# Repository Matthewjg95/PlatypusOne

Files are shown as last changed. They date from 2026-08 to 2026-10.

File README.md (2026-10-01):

# PlatypusOS

An extensible embedded operating environment for the **Arduino UNO Q**, built by
Platypus One. PlatypusOS is not a single application — it is an engineering
handheld platform where **every feature is an app**.

## Architecture at a glance

```
┌─────────────────────────────────────────────────────┐
│  apps/        launcher · shadowscan · viewer ·      │
│               measurement · inspection · docs ·     │
│               settings          (all implement IApp)│
├─────────────────────────────────────────────────────┤
│  services/    appfw · renderer · vision · ai ·      │
│               geometry · export · filesystem        │
├─────────────────────────────────────────────────────┤
│  platform/    HAL interfaces + board drivers        │
│               (IBoard · ICamera · ISensorHub ·      │
│                IDisplay · IAudioOutput · IMcuBridge)│
├─────────────────────────────────────────────────────┤
│  Arduino UNO Q:  Linux MPU (QRB2210)  ⇄  STM32U585 │
└─────────────────────────────────────────────────────┘
```

Dependency direction is strict: **apps → services → platform**. Nothing points
upward. Concrete hardware types exist only in board implementations and the
composition root ([main.cpp](apps/launcher/src/main.cpp)).

## Key principles

- **Everything is an app.** Features implement `IApp` and register with
  `AppRegistry`. The launcher is itself just an app.
- **Interfaces over hardware.** No module touches a driver; capabilities come
  through `IBoard` accessors that return `nullptr` when absent.
- **Dependency injection, no global state.** All services flow through
  `AppContext`, built once in the composition root.
- **Host-first development.** `HostSimBoard` lets the whole OS build and run on
  a workstation with zero hardware.
- **Plugin-ready.** `AppFactory` is the future dynamic-loading ABI.

## Building

```
cmake -B build -DPLATYPUS_TARGET_HOST=ON
cmake --build build
ctest --test-dir build
./build/apps/launcher/platypus_launcher
./build/apps/launcher/platypus_launcher --geometry 800x480
```

Requires CMake ≥ 3.22 and a C++20 compiler (GCC 12+, Clang 15+, MSVC 19.3+).
Every subsystem is an independent CMake target and compiles on its own.

`--geometry WxH` simulates a different panel (default 320×240). No resolution
is compiled in: the display target is deliberately dynamic while the production
panel is undecided, and prototyping runs against a linked external display —
see [ADR-0001](docs/adr/0001-dynamic-linked-prototype-display.md) and the
[presentation link protocol](docs/protocols/presentation.md).

The Scout prototype also has a local Linux/KMS kiosk for the UNO Q + Media
Carrier + Waveshare 800×480 panel. Use the [pinned UNO Q build/launch sequence](docs/hardware/UNO_Q_SCOUT_BASELINE.md)
for that path. Dream Lab was submitted September 30; [stabilization and evidence status](docs/contest/POST_DREAMLAB_STABILIZATION.md)
separate the merged single-capture baseline from staged sessions/classifier work.

## Documentation

- [docs/PRODUCT_REQUIREMENTS_BASELINE.md](docs/PRODUCT_REQUIREMENTS_BASELINE.md) — what Platypus One must be and how each requirement is verified
- [STATUS.md](STATUS.md) — where the project actually is right now
- [docs/ARCHITECTURE.md](docs/ARCHITECTURE.md) — layers, diagrams, rationale
- [docs/CODING_STANDARDS.md](docs/CODING_STANDARDS.md) — C++/Python conventions
- [docs/ROADMAP.md](docs/ROADMAP.md) — prioritized TODO roadmap
- Carrier-board methodology, BOM scope layering, and post-contest research
  dossiers live in the private planning overlay until their components are
  promoted into Contest Core
- [docs/adr/](docs/adr/README.md) — architecture decision records
- [docs/protocols/](docs/protocols/) — wire protocols (MCU bridge, presentation link)
- Per-module headers carry interface documentation inline.

## Repository layout

| Path | Contents |
|---|---|
| `platform/` | HAL interfaces and board drivers (hardware, display, camera, sensors, audio) |
| `services/` | Hardware-agnostic engines (appfw, renderer, vision, ai, geometry, export, filesystem) |
| `apps/` | User-facing applications |
| `third_party/` | Vendored dependencies (currently none — kept dependency-free) |
| `docs/` | Architecture, standards, diagrams, roadmap |
| `tests/` | Unit tests (run on host, no hardware needed) |

## License

PlatypusOS is licensed under the [Apache License 2.0](LICENSE). This permits
commercial use, modification, and distribution subject to the license terms.
The license does not grant rights to project names or trademarks.

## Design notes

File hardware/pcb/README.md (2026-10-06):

# Platypus One PCB workstream — design status

**Authoritative status for custom PCBs.** Last updated **2026-10-05**.
Tracking issue: [#33](https://github.com/Matthewjg95/PlatypusOne/issues/33).
Upstream gates (not duplicated here): [Rev A gates](../../docs/hardware/PERCEPTION_CARRIER_REV_A_GATES.md),
[pre-layout split](../../docs/hardware/PERCEPTION_CARRIER_REV_A_PRELAYOUT.md).

Nothing in this directory is bench evidence. Every value is tagged with where it
came from (datasheet, derived, estimate) or marked `BENCH_VERIFY` / `UNKNOWN`.

## What PCB are we designing?

**Perception Head PCB, Rev A** — a small rigid board at the top of the
handheld that carries the sensing stack as one calibrated unit:

| Function | Rev A implementation | Source sheet |
|---|---|---|
| ToF depth | Pololu #3419 VL53L8CX carrier, hosted on headers + 2× M2, own I2C bus, power-cyclable 3.29 V rail in the host 3.3 V logic domain | `tof.kicad_sch`, `power.kicad_sch` |
| IMU | Bosch BMI270, I2C bus A, INT1 direct to host | `imu.kicad_sch` |
| Controlled white illumination | 2-channel linear constant-current sink, analog set-point (DAC/filtered PWM), current-limited switched 5 V, off-board light boards | `illumination.kicad_sch` |
| Identity / calibration | AT24CS32 EEPROM with factory 128-bit serial, write-protected by default | `id_calibration.kicad_sch` |
| Control I/O | TCA9534 expander for slow enables (ToF power, illumination enable, EEPROM WP, status LED) | `host_interface.kicad_sch` |
| Host link | one locking 14-pin JST GH cable (5 V, 3V3, 2× I2C, 3 interrupts/sync, illumination set) + Qwiic bench port | `host_interface.kicad_sch` |
| Camera | **mechanical only**: 4 standoff holes for the selected IMX219 module; CSI stays on the Media Carrier | `debug_test.kicad_sch` |
| Bring-up | 31 test points, 3 Kelvin current shunts, LED-current sense points, illumination kill jumper | `debug_test.kicad_sch` |

KiCad project: [`perception_head_rev_a/`](perception_head_rev_a/README.md) (KiCad 9.0).

**Host / Power / Controls Carrier (B)** is defined at architecture/interface
level only: [HOST_CARRIER_ARCHITECTURE.md](HOST_CARRIER_ARCHITECTURE.md).

## Why does it exist?

The camera↔ToF relative pose is a calibration quantity. If camera and ToF are
held by the enclosure, every display change, cover removal or chassis revision
can invalidate calibration. A rigid head PCB that also holds the camera module
makes the pose a property of one serviceable sub-assembly, independent of the
display decision (#41) that is still moving.

## What is Rev A supposed to prove?

1. ToF + IMU + illumination can run on the UNO Q MCU side **without disturbing**
   the proven RGB CSI path (Media Carrier CSI + DSI display).
2. The single-cable interface (power + 2 I2C buses + interrupts) is electrically
   clean at the real cable length.
3. Camera↔ToF extrinsic calibration survives remove/refit of the head
   (datum-hole scheme).
4. Controlled illumination at a measured current improves capture repeatability
   enough to earn its power/thermal cost — or is shown not to.
5. Per-unit identity + compact calibration record can be read by software and
   tied to captures.
6. Real power numbers for every head load, measured through on-board shunts.

## Explicitly out of scope (Rev A)

MIPI CSI routing on our board; replacing the Media Carrier; display interface;
battery/charging; bare VL53L8CX integration (Rev B candidate); radar, thermal,
RF experiments, robotics; cosmetics; production certification; algorithm tuning.

## Status board

| Item | State | Notes |
|---|---|---|
| Architecture split A/B | **FROZEN** | per pre-layout doc |
| Camera = replaceable module on Media Carrier CSI | **FROZEN for Rev A** | |
| ToF option: host Pololu #3419 (not bare IC) | **DECIDED for Rev A** | [ledger §VL53L8CX](RESEARCH_LEDGER.md#vl53l8cx-decision-host-the-pololu-3419-for-rev-a) |
| ToF on dedicated I2C bus + switchable rail | **DECIDED** | reset = power cycle (UM3109 §4.2) |
| IMU = BMI270 on bus A | **DECIDED** | BNO055 is NRND |
| Illumination topology (linear CC, analog set) | **PROVISIONAL – strong** | current, LED part, placement open |
| LED current / LED part / light-board geometry | **OPEN** | optical + thermal + host 5 V evidence |
| EEPROM identity scheme | **PROVISIONAL – strong** | record schema to define in software |
| Host connector family/pinout | **PROVISIONAL** | JST GH 14 for bench; final after Fusion routing |
| Host-side pin assignment | **PROVISIONAL (TBD_*)** | candidates in [ICD](ICD_PERCEPTION_HEAD.md) |
| ToF rail 3.29 V + voltage-domain crossings | **DECIDED by worst-case analysis (ICD §5a) – BENCH_VERIFY (T2, T13)** | 3.43 V is a conditional fallback only |
| Board outline, hole positions, connector placement | **BLOCKED (MECHANICAL)** | [Fusion inputs](MECHANICAL_FUSION_INPUTS.md) |
| Camera choice (B0394/B0393/B0390) | **BLOCKED (BENCH)** — analysis pipeline ready, capture matrix not yet run | [intake table](CAMERA_EVIDENCE_INTAKE.md), [characterization](../../docs/hardware/CAMERA_CHARACTERIZATION.md) |
| ToF usefulness / operating modes | **BLOCKED (BENCH, Platypus Lab #3)** | no physical ToF data yet |
| Power budget | **BLOCKED (BENCH)** | [power tree](POWER_TREE_REV_A.md) |
| Schematic ERC | **0 errors / 0 warnings** (2026-10-05, KiCad 9.0.9) | [report](perception_head_rev_a/outputs/erc_report.txt) |
| Layout / Gerbers / order | **NOT STARTED – gated** | |

## What can proceed now (no physical evidence needed)

- Firmware skeleton for the head on the STM32 side: TCA9534 safe-init order,
  BMI270 config upload, AT24CS32 record format + CRC, ToF power-cycle state machine.
- Calibration record schema (EEPROM + host files keyed by serial).
- Symbol/footprint verification of remaining stock parts against manufacturer drawings.
- Light-board concept (LED candidates, diffuser, baffle) as a separate tiny board.
- Host-carrier block diagram refinement once the display path narrows.

## Gate releases

**Schematic freeze** requires all of:
1. Host pin map frozen (UNO Q pins proven by a bench harness with this exact signal set).
2. Pololu 1×4 header order continuity-checked; AVDD ≥ 3.13 V under 8×8 ranging at the chosen rail voltage.
3. Bus B clean on a scope at the real cable length (with/without C18/C19).
4. Host 5 V headroom measured with UNO Q + Media Carrier + display + camera running → sets R15 (switch limit) and LED full-scale.
5. Illumination current + LED part chosen from optical/thermal tests.
6. Platypus Lab ToF evidence shows ToF earns its place (or ToF is dropped/deferred, which simplifies the board).
7. Every DECISION REQUIRED row in the [register](DECISION_REGISTER.md) closed or explicitly deferred.
8. Measured, not inferred: register items **H1, H2, H4, H6, T2, T3, T4, T5, T13** stay provisional until bench evidence exists. ERC and the netlist check are hygiene, not circuit validation.

**Layout start** additionally requires:
1. Fusion delivers head outline envelope, camera/ToF optical centres, datum-hole
   positions, connector exits and keep-out cones ([list](MECHANICAL_FUSION_INPUTS.md)).
2. Camera module selected and its board/holes/lens stack measured (#40 T5).
3. Footprints frozen (connector families final).

**Fabrication** additionally requires:
1. DRC clean with fab-house rules; 3D STEP fit-checked in Fusion.
2. Bring-up plan ([BRINGUP_AND_TEST.md](BRINGUP_AND_TEST.md)) reviewed; test fixture/harness ready.
3. BOM availability re-checked on order day (stock/lifecycle).
4. Independent review of the schematic (human or second agent) with this README's gates ticked.

## Document map

| Document | Purpose |
|---|---|
| [RESEARCH_LEDGER.md](RESEARCH_LEDGER.md) | Sources and exact facts used; decisions derived from them |
| [DECISION_REGISTER.md](DECISION_REGISTER.md) | Every unknown, classified, owned, with blocking impact |
| [ICD_PERCEPTION_HEAD.md](ICD_PERCEPTION_HEAD.md) | UNO Q / Media Carrier ↔ head interface, connector candidates |
| [POWER_TREE_REV_A.md](POWER_TREE_REV_A.md) | Rails, KNOWN / MEASURED / ESTIMATED / UNKNOWN loads, bench measurements needed |
| [BOM_PERCEPTION_HEAD_REV_A.md](BOM_PERCEPTION_HEAD_REV_A.md) | Candidate BOM with rationale and alternates |
| [MECHANICAL_FUSION_INPUTS.md](MECHANICAL_FUSION_INPUTS.md) | Optical/mechanical constraints and what Fusion must supply |
| [BRINGUP_AND_TEST.md](BRINGUP_AND_TEST.md) | Safe power-up, bring-up sequence, failure isolation tests |
| [CAMERA_EVIDENCE_INTAKE.md](CAMERA_EVIDENCE_INTAKE.md) | Drop-in table for the B0394/B0393/B0390 results |
| [HOST_CARRIER_ARCHITECTURE.md](HOST_CARRIER_ARCHITECTURE.md) | Board B architecture and interfaces (no layout) |

Directory layout is deliberately flat: add `manufacturing/` or `bringup/`
sub-directories only when they contain real files (fab outputs, logs).

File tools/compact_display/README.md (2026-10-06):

# tools/compact_display

Software preparation for the compact DSI panels in
[COMPACT_DISPLAY_SELECTION.md](../../docs/hardware/COMPACT_DISPLAY_SELECTION.md):
the Waveshare 3.5inch DSI LCD (H) and (E) on UNO Q + UNO Media Carrier.

**None of this has run on a board yet.** Host tests prove consistency, not function.

| Path | Purpose |
|---|---|
| `panels/*.panel` | Panel definitions in the shell format of `dcuartielles/uno_q_dsi_displays` (pinned `d633636`), plus Goodix keys |
| `reference/waveshare_35dsi_overrides.json` | Values decoded from Waveshare's own `Waveshare_35DSI.dtbo`; the tests compare against it |
| `gen_overlay.py` | Overlay for a controller-less panel (polled GT911, no ATTINY) |
| `install_panel.sh` | Board-side install with backup and test-compose; `--dry-run` works anywhere |
| `restore_5in.sh` | Back to the proven 5" |
| `bench_accept.sh` | Acceptance stages D0–D7 → evidence + `results.json` |
| `test_compact_display.py` | Host unit tests |

```sh
python3 -m unittest tools/compact_display/test_compact_display.py
tools/compact_display/install_panel.sh --dry-run          # generate + compile the (H) overlay
```

Procedure: [COMPACT_DISPLAY_BENCH_ACCEPTANCE.md](../../docs/hardware/COMPACT_DISPLAY_BENCH_ACCEPTANCE.md).

The board scripts call upstream scripts for the module build. Upstream files
are not copied here: the upstream repository is the one that built our working
5", and we keep it as the single source.

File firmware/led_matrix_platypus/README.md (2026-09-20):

# led_matrix_platypus — UNO Q mascot / MCU aliveness check

Draws the Platypus One mascot on the UNO Q's **8 × 13** LED matrix (104 LEDs),
replacing the factory heart/animation demo.

It earns its place in `firmware/` by doubling as the first checklist item's
proof: [TEST_CHECKLISTS.md §1](../../docs/hardware/TEST_CHECKLISTS.md) ends with
"MCU side alive: stock LED matrix demo (or blink) runs". If the platypus
paddles, the MCU is running **our** code, not factory firmware — a stronger
signal than the stock demo, and it photographs well for the contest
documentation score.

## The animation

Four frames at 220 ms: glide → kick → glide → blink. The silhouette is a side
view facing left, shaded in four tones using the matrix's grayscale mode:

```
        ##########              crown of the head   (mid edges, full centre)
      ##  ##########            eye notch (off)
##########################      bill (dim→mid) | body (full) | tail (mid→dim)
##########################
      ####################      body + tail
      ##############            belly (mid, in shadow)
        ####    ####            webbed feet (dim, under the water)
```

Proportion carries the read at this size: the bill is two rows tall and the
tail three, against a six-row body, so the thin shapes either side are
unmistakably a bill and a paddle tail. The tones give it volume: lit from
above, darker underneath, extremities fading out.

## Editing the mascot

Frames are literal brightness tokens in `kPlatypus[][8][13]` — `o` off, `d`
dim, `m` mid, `X` full — so what you see in the source is what lights up. Edit
by eye; no bitmap tooling needed. The driver quantises to 8 hardware levels, so
the token values are chosen to land on levels 1 / 3 / 7.

## Porting note

The UNO Q matrix is **8 × 13**, unlike the UNO R4 WiFi's 12 × 8, so R4 examples
and frame-packing tools do not transfer. Only `showFrame()` and two lines in
`setup()` touch the vendor API:

```cpp
matrix.begin();
matrix.setGrayscaleBits(8);   // setup
matrix.draw(&frame[0][0]);    // showFrame — row-major 8x13 bytes, 0..255
```

**Verified on hardware** (2026-09-19) against `arduino:zephyr` 1.0.0 /
`Arduino_LED_Matrix` 0.1.3 via `arduino-cli compile --fqbn
arduino:zephyr:unoq` and `arduino-cli upload -p COM7`. The upload goes through
the board's Linux side, which drives OpenOCD over SWD to the STM32U585. Note
the 1-bit `renderBitmap()` macro on this core takes a non-`const` pointer, which
is why the first (unshaded) revision needed a `const_cast`; the grayscale
`draw()` path takes `const` directly.

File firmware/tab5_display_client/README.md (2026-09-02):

# tab5_display_client (M5Stack Tab5)

The display-client half of the
[presentation link](../../docs/protocols/presentation.md): receives pixel
tiles over USB CDC, blits them, reports touch. Deliberately dumb — no app
knowledge, per ADR-0001.

Shares `platform/display/include/platypus/hal/link/Framing.hpp` verbatim;
build with the include path, never a copied header (see the sketch header for
the `arduino-cli` line).

## Verification

Per STATUS.md protocol this sketch is **NOT COMPILED** until it builds against
the M5Stack Tab5 core. Bench questions to settle in the first session
(status board steps 5–6 in
[TEST_CHECKLISTS.md](../../docs/hardware/TEST_CHECKLISTS.md)):

- USB topology/role: which end hosts the CDC link (UNO Q USB-C ↔ Tab5 USB-C),
  and the resulting device path on the UNO Q (default assumption
  `/dev/ttyACM0`).
- RGB565 byte order into `pushImage` — flip `setSwapBytes` if colors invert.
- Touch coordinate orientation vs the negotiated geometry (rotation is the
  client's job, spec §5).
- Measure real tile throughput and replace the protocol's §2 estimates.

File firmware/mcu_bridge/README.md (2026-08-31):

# mcu_bridge firmware (STM32U585)

The MCU side of [mcu-bridge v1](../../docs/protocols/mcu-bridge.md): Ping/Pong
plus the core GPIO / analog / PWM topics. Shares
`platform/hardware/include/platypus/hal/mcu/Framing.hpp` with the Linux driver
and the host tests — build with the include path, do not copy the header:

```bash
arduino-cli compile --fqbn <uno-q-mcu-fqbn> firmware/mcu_bridge \
  --build-property "compiler.cpp.extra_flags=-I$(pwd)/platform/hardware/include"
```

`<uno-q-mcu-fqbn>` is the UNO Q MCU board id from the Arduino UNO Q core
(check `arduino-cli board listall` after installing the UNO Q platform); a
bench Nucleo U575/U585 with the STM32duino core works for protocol testing
over USB CDC.

## Verification

Per STATUS.md protocol this sketch is **NOT COMPILED** until it builds against
the real UNO Q core — the RPMsg serial binding and `analogWrite` range are the
board-specific risks. Bring-up sequence is
[TEST_CHECKLISTS.md §2](../../docs/hardware/TEST_CHECKLISTS.md): Ping/Pong
round-trip, then GPIO loopback (jumper two pins, `GpioSet` one, `GpioRead`
the other).

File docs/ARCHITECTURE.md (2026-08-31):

# PlatypusOS Architecture

## 1. Product model

PlatypusOS is an embedded operating environment for a commercial engineering
handheld (Platypus One) built on the Arduino UNO Q. The product is a *platform*:
every feature — 3D scanning (shadowscan), model viewing, measurement,
inspection, documentation capture, settings — is an application on a shared
runtime.

## 2. Target hardware

The Arduino UNO Q is a dual-brain board:

| Core | Role in PlatypusOS |
|---|---|
| Qualcomm QRB2210 (quad-A53, Linux) | Runs PlatypusOS proper: UI, vision, AI, storage |
| STM32U585 (Cortex-M33) | Real-time I/O: GPIO, PWM, ADC, deterministic sensor sampling |

The two communicate over an RPC transport abstracted by `IMcuBridge`
([IMcuBridge.hpp](../platform/hardware/include/platypus/hal/IMcuBridge.hpp)).
Nothing outside the bridge implementation knows the wire protocol.

## 3. Layering

```mermaid
flowchart TD
    subgraph apps
        L[launcher] --- S[settings] --- SS[shadowscan] --- V[viewer] --- M[measurement]
    end
    subgraph services
        AF[appfw<br/>IApp · AppContext · AppRegistry]
        R[renderer]
        FS[filesystem]
        G[geometry]
        VI[vision*] --- AI[ai*] --- EX[export*]
    end
    subgraph platform
        B[IBoard]
        C[ICamera]
        D[IDisplay]
        SH[ISensorHub]
        A[IAudioOutput]
        MB[IMcuBridge]
        ST[IStorage]
    end
    apps --> services --> platform
    B --> C & D & SH & A & MB & ST
```

\* skeleton directories, not yet implemented.

Rules:

1. **Strict downward dependencies.** An app may use services and HAL
   interfaces; a service may use HAL interfaces; the HAL depends on nothing.
2. **Interfaces at every boundary.** Concrete driver types appear only inside
   board implementations and the composition root.
3. **No global state.** The single composition root
   ([main.cpp](../apps/launcher/src/main.cpp)) constructs the object graph and
   injects it. The only static is the POSIX signal flag, which cannot be
   avoided.
4. **Independent compilation.** Every directory is a standalone CMake target;
   interface layers are header-only `INTERFACE` libraries.

## 4. The application model

```mermaid
sequenceDiagram
    participant Shell as Shell loop (main)
    participant Reg as AppRegistry
    participant App as IApp

    Shell->>Reg: create("one.platypus.shadowscan")
    Reg-->>Shell: unique_ptr<IApp>
    Shell->>App: onStart(ctx)
    loop every ~33 ms
        Shell->>App: onFrame(ctx, dt)
        Note over App: draws via ctx.renderer,<br/>reads hardware via ctx.board
    end
    App->>Shell: ctx.requestLaunch(id)
    Shell->>App: onStop()
```

- `AppContext` is the DI seam: `board`, `renderer`, `projects`, and a
  `requestLaunch` callback. Apps own nothing global.
- `AppManifest` declares identity and hardware requirements so the launcher can
  grey out apps whose hardware is absent.
- `AppFactory` (a plain function pointer) is deliberately ABI-simple: the same
  signature will be exported from dynamically loaded plugin `.so` files.

## 5. Hardware absence is normal

`IBoard` accessors return `nullptr` for missing capabilities. A Platypus One
without a camera still boots; apps declaring `requiresCamera` are simply not
launchable. This same mechanism supports future sensor expansion: new sensors
register self-describing `SensorDescriptor`s with `ISensorHub`, and generic UIs
render them without code changes.

## 6. Error handling

The HAL is exception-free across module boundaries: all fallible calls return
`Result<T>`/`Status` with a compact `Error` enum
([Result.hpp](../platform/hardware/include/platypus/hal/Result.hpp)). Services
may use exceptions internally but must not leak them into HAL callbacks.

## 7. Threading model

- The shell loop is single-threaded; all `IApp` callbacks run on it.
- Driver callbacks never invoke apps directly. Touch and button input enters the
  bounded `appfw::EventQueue`, then the shell dispatches a fixed snapshot on the
  UI thread each tick. Camera and sensor payload queues follow the same rule.
- Long computations (mesh reconstruction, AI inference) run on app-owned worker
  threads joined in `onStop()`.

## 8. Language split

- **C++20** — platform, services, app shells (deterministic, low-overhead).
- **Python 3.11+** — permitted in `services/ai` and `services/vision` behind a
  C++ interface boundary, for model prototyping on the Linux MPU. Production
  inference paths get ported to C++ once stable.

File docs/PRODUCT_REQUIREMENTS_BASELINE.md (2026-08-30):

# Platypus One — Product and System Requirements Baseline

- **Baseline:** P1-PRB-0.1
- **Date:** 2026-08-25
- **Status:** Proposed
- **Owner:** Matthew
- **Change authority:** Owner approval through pull request or an accepted ADR

This document is the design anchor for Platypus One. It translates the product
idea, industrial-design direction, PlatypusOS architecture, hardware BOM, and
contest obligations into one traceable baseline. It does not freeze unresolved
parts or claim performance that has not been measured.

## 1. Requirement language and status

- **SHALL**: required for the stated baseline.
- **SHOULD**: expected unless testing or a documented trade study rejects it.
- **MAY**: permitted, not required.
- **Locked**: owner decision already made; change requires an ADR or baseline revision.
- **Target**: design objective requiring verification.
- **Open**: decision or numeric threshold is not yet resolved.
- **Deferred**: intentionally outside the contest Rev A baseline.

A requirement is not verified merely because code, CAD, or a BOM line exists.
Verification evidence must be linked or recorded against the requirement.

## 2. Product definition

### 2.1 Mission

**An engineer standing beside you.**

Platypus One is a one-handed, local-first physical-engineering observation
instrument. It converts imperfect real-world inputs—photos, geometry,
measurements, motion, and sensor observations—into structured engineering
evidence that can be reviewed, exported, and improved through iteration.

The primary interaction is:

> **Point → Understand → Visualize/Create**

The larger closed loop is:

> reality → sensor → local interpretation → evidence → engineering artifact →
> experiment or decision → improved knowledge → next observation

### 2.2 Product boundary

| ID | Requirement | Status |
|---|---|---|
| PROD-001 | Platypus One SHALL be a civilian engineering tool for inspection, measurement, reverse engineering, and documentation. | Locked |
| PROD-002 | The product SHALL NOT be designed or presented for weapons, military operations, harmful surveillance, or autonomous targeting. | Locked |
| PROD-003 | The product SHALL operate without a required cloud connection for its baseline workflows. | Locked |
| PROD-004 | The product SHALL remain useful when an optional sensor, camera, module, or network connection is absent. | Locked |
| PROD-005 | Every included feature SHALL save a recognizable step in a physical-engineering workflow; novelty alone is insufficient justification. | Locked |
| PROD-006 | Platypus One SHALL be treated as a product platform, not a single-purpose scanner or meter. | Locked |

### 2.3 Primary users

The baseline serves makers, product designers, manufacturing engineers,
technicians, inspectors, repairers, field engineers, and students who work
beside physical objects and later need trustworthy digital records.

The owner is the first ergonomic test user. His measured thumb-to-pinky hand
span is approximately **7.5 in**. That is a prototype fit input, not a
population-wide anthropometric requirement; broader fit testing remains open.

## 3. Baseline workflows

### 3.1 Contest Rev A workflows

| ID | Workflow | Required outcome | Status |
|---|---|---|---|
| WF-001 | Inspect | View a live or captured sensor observation and save it into a project record with source context. | Target |
| WF-002 | Measure | Capture a supported measurement, display its value and unit, and save it with time and source metadata. | Target |
| WF-003 | Document | Capture a photo and note without moving the evidence through a separate phone/notebook workflow. | Target |
| WF-004 | Visualize | Open and inspect a supported mesh or point-cloud artifact on the handheld. | Target |
| WF-005 | Capture geometry | Convert a controlled physical observation into a reviewable geometry artifact through the ShadowScan path. | Target |
| WF-006 | Export | Move a project artifact to a standard, user-owned file without a proprietary cloud dependency. | Target |

Rev A does not require every aspirational application to be equally mature. The
contest prototype SHALL demonstrate at least one complete closed loop from
physical observation to saved evidence to exported engineering artifact.
ShadowScan plus measurement is the preferred demonstration path in the current
roadmap.

### 3.2 Future physical-to-CAD handoff

Platypus One is the physical-world capture counterpart to Mesh2CAD and the
portable SketchAsset library. A future workflow MAY:

1. observe or scan a part;
2. identify a useful mechanical interface;
3. ask the user to confirm critical dimensions;
4. create a source-agnostic SketchAsset;
5. open or export that interface for Fusion, FreeCAD, or KiCad.

Automatic SketchAsset creation is **Deferred** from contest Rev A. The
requirements now are that Platypus One preserve enough provenance and units for
a future adapter, and that it not lock evidence to one CAD backend.

## 4. Functional requirements

### 4.1 Application platform

| ID | Requirement | Verification | Status |
|---|---|---|---|
| FUNC-001 | PlatypusOS SHALL present capabilities as applications sharing common platform services. | Architecture inspection + host test | Locked |
| FUNC-002 | The launcher SHALL identify applications whose required hardware is absent and prevent launch without preventing system boot. | Automated host test | Locked |
| FUNC-003 | Applications SHALL access hardware through HAL interfaces rather than concrete device drivers. | Dependency inspection | Locked |
| FUNC-004 | Application, service, and platform dependencies SHALL point downward only: apps → services → platform. | Build graph/review | Locked |
| FUNC-005 | The display geometry SHALL be discovered at runtime; apps SHALL NOT compile in one panel resolution. | Automated layout/build review | Locked |
| FUNC-006 | Long-running vision, geometry, or inference work SHALL NOT block the UI event loop. | Integration test | Target |
| FUNC-007 | User-facing operations SHALL expose cancel, failure, or unavailable states instead of silently hanging. | App acceptance tests | Target |

### 4.2 Projects and evidence

| ID | Requirement | Verification | Status |
|---|---|---|---|
| DATA-001 | A saved observation SHALL belong to an identifiable local project or explicit standalone record. | ProjectStore test | Target |
| DATA-002 | A record SHALL preserve timestamp, units where applicable, producing app, source capability, and device/software revision when available. | Schema test | Target |
| DATA-003 | Raw observations SHALL remain distinguishable from derived results. | Schema and export inspection | Target |
| DATA-004 | A derived claim SHOULD include the transformation, settings, and confidence or limitation information needed to interpret it. | Report inspection | Target |
| DATA-005 | Rejected, failed, or anomalous captures SHALL NOT be silently presented as valid evidence. | Fault-injection test | Target |
| DATA-006 | Export SHALL use documented, user-owned formats and SHALL NOT require a Platypus cloud account. | Offline export test | Locked |
| DATA-007 | Saving or exporting SHALL avoid silently overwriting an existing artifact. | Filesystem test | Target |
| DATA-008 | Local project data SHALL remain available after an ordinary restart or loss of network connectivity. | Restart/offline test | Target |

### 4.3 Measurement and capture

| ID | Requirement | Verification | Status |
|---|---|---|---|
| CAP-001 | A measurement view SHALL show value, unit, source, and current validity state together. | UI inspection | Target |
| CAP-002 | The user SHALL be able to deliberately trigger a capture with the hand holding the device. | Ergonomic test | Locked |
| CAP-003 | The camera and ranging axis SHOULD align with the natural pointing direction of the barrel. | CAD inspection + physical test | Locked |
| CAP-004 | Geometry or measurement output SHALL state when required calibration is missing or expired. | Fault-injection test | Target |
| CAP-005 | Accuracy and repeatability claims SHALL be based on recorded calibration and test data; no numeric accuracy is baselined yet. | Test report review | Open |
| CAP-006 | The user SHALL be able to review a captured artifact before it is accepted into the project record. | Workflow test | Target |
| CAP-007 | Controlled illumination SHALL be available to supported camera/ShadowScan workflows. | Hardware test | Target |

## 5. Human factors and industrial design

| ID | Requirement | Verification | Status |
|---|---|---|---|
| HF-001 | Rev A SHALL use a fat pistol-grip form intended for stable one-handed operation. | CAD + physical fit test | Locked |
| HF-002 | The primary grip orientation SHALL be left-hand-first so the dominant right hand remains available to probe, mark, or adjust the work. | Ergonomic test | Locked |
| HF-003 | The scan trigger SHALL fall under the gripping hand's index finger without requiring a grip shift. | Physical fit test | Target |
| HF-004 | The push rotary encoder SHALL be reachable by the left thumb without releasing the grip. | Physical fit test | Locked |
| HF-005 | The display SHALL be the largest practical screen supported by the front-face packaging and balance constraints. | CAD trade study | Locked direction |
| HF-006 | The charging connector SHALL exit at the grip base so a cable hangs away from the work area. | CAD inspection | Locked |
| HF-007 | Camera/ToF placement SHOULD minimize parallax and preserve intuitive aiming in the intended grip. | CAD + calibration test | Target |
| HF-008 | The device SHOULD support use on a bench through a kickstand and/or 1/4-20 tripod interface. | CAD + fit test | Target |
| HF-009 | Critical controls SHALL be distinguishable by position and shape without requiring the user to read the display. | Physical usability test | Target |
| HF-010 | Production-handedness strategy beyond the Rev A left-hand-first prototype remains open; software rotation/remapping MAY support broader use. | Owner decision | Open |

No final outer dimensions or mass are baselined. They SHALL be derived from
component packaging, grip fit, balance, manufacturing process, and physical
prototype testing rather than copied from an AI concept sheet.

## 6. Hardware and packaging requirements

### 6.1 Core architecture

| ID | Requirement | Verification | Status |
|---|---|---|---|
| HW-001 | Rev A SHALL use the Arduino UNO Q as the central compute, UI, storage, wireless, and sensor-fusion platform. | BOM + assembly inspection | Locked |
| HW-002 | Linux-side work SHALL own UI, vision, local inference, geometry, and project storage. | Architecture/bring-up test | Locked |
| HW-003 | STM32-side work SHALL own deterministic I/O and sensor sampling through the documented MCU bridge. | Bridge integration test | Locked |
| HW-004 | The enclosure SHALL reserve at least the UNO Q planning envelope of 85 × 54 × 20 mm until an exact board model supersedes it. | Fusion interference check | Target |
| HW-005 | Exact vendor STEP models SHALL replace planning envelopes before carrier PCB/enclosure freeze. | CAD review | Target |

### 6.2 Display

| ID | Requirement | Verification | Status |
|---|---|---|---|
| DISP-001 | The production path SHALL target a 4.3–5 in MIPI-DSI, 800×480-class capacitive panel driven from Linux. | ADR-0002 + bring-up | Locked |
| DISP-002 | The exact panel part, active area, connector, FPC routing, and Linux device-tree support SHALL be verified before the enclosure aperture is frozen. | Candidate report + bring-up | Open |
| DISP-003 | 800×480 SHALL be the UI reference geometry, not a compiled-in assumption. | Host geometry tests | Locked |
| DISP-004 | A linked external display MAY be used for prototyping; it SHALL remain behind IDisplay. | Integration inspection | Locked |
| DISP-005 | If no viable DSI panel is identified by 2026-09-30, the documented ESP32-S3 bridge fallback SHALL be reconsidered so the carrier schedule can hold. | Decision gate review | Locked gate |

### 6.3 Enclosure, RF, and thermal

| ID | Requirement | Verification | Status |
|---|---|---|---|
| MECH-001 | The prototype enclosure SHOULD use a hybrid CNC-aluminum barrel/screen surround and printed polymer grip. | CAD/BOM inspection | Target |
| MECH-002 | The grip SHALL remain polymer or otherwise RF-transparent around the radio antenna region. | CAD + RF test | Locked |
| MECH-003 | No metal enclosure feature SHALL cover the UNO Q radio antenna without a verified RF path or external-antenna design. | CAD review + connectivity test | Locked |
| MECH-004 | The forward barrel SHALL package the camera, illumination, and selected ranging sensor along the pointing axis. | CAD interference check | Locked |
| MECH-005 | Thermal coupling between hot compute components and any aluminum heat-spreading feature SHALL be intentional and electrically safe. | Thermal design review | Target |
| MECH-006 | Surface temperature, sustained compute load, and throttling limits SHALL be measured before claiming passive-heatsink performance. | Thermal test | Open |
| MECH-007 | Service access SHALL permit assembly and replacement of the battery, compute board, display, and carrier without destructive enclosure work. | Assembly trial | Target |

### 6.4 Planning envelopes

These are packaging inputs, not final part specifications:

| Component | Current envelope |
|---|---:|
| Arduino UNO Q | 85 × 54 × 20 mm |
| Production display class | approximately 120 × 75 × 5 mm at 4.3 in; exact part TBD |
| Camera candidate | 25 × 25 × 10 mm |
| Rotary encoder | 24 × 24 × 30 mm |
| Flat battery candidate | 100 × 60 × 8 mm |
| ToF/IMU/color sensors | exact selected breakouts TBD |

### 6.5 Power

| ID | Requirement | Verification | Status |
|---|---|---|---|
| PWR-001 | Rev A SHALL use a protected rechargeable cell and a power path capable of supporting the measured UNO Q, display, sensor, and peak-compute load. | Electrical test | Target |
| PWR-002 | USB-C charging/power SHALL be accessible at the grip base. | CAD + charge test | Locked |
| PWR-003 | The system SHALL preserve or safely close project writes before an intentional shutdown when the platform provides adequate warning. | Power-loss test | Target |
| PWR-004 | The published runtime SHALL be based on a repeatable workload test; approximately two hours is a planning target, not a verified requirement. | Runtime test | Open |
| PWR-005 | Battery protection, conductor sizing, charging temperature range, and enclosure clearances SHALL be reviewed before untethered use. | Electrical safety review | Target |

## 7. Software and interface requirements

| ID | Requirement | Verification | Status |
|---|---|---|---|
| SW-001 | PlatypusOS SHALL retain host-first operation so platform and app work can continue without target hardware. | Host build/test | Locked |
| SW-002 | Platform code SHALL use C++20; Python MAY be used for AI/vision prototyping behind a C++ service boundary. | Build/review | Locked |
| SW-003 | HAL boundaries SHALL remain exception-free and return explicit Result/Status values. | API inspection | Locked |
| SW-004 | Camera and sensor callbacks SHALL hand data to the UI through a thread-safe event mechanism. | Concurrency test | Target |
| SW-005 | Applications SHALL use runtime display information and SHOULD remain usable at the 800×480 reference geometry. | Host UI tests | Target |
| SW-006 | Hardware-specific types SHALL appear only in board implementations and the composition root. | Dependency inspection | Locked |
| SW-007 | No baseline workflow SHALL require a cloud API, account, or subscription. | Offline system test | Locked |
| SW-008 | Dynamic third-party app loading, signed manifests, OTA, and full power management are Deferred to M4 unless pulled forward by a documented blocker. | Roadmap review | Deferred |

## 8. Engineering Scout Module family

Platypus One is the brain; interchangeable Engineering Scout Modules are a
future field-extension family. Candidate concepts include Scout-Cam, Scope, RF,
Thermal, Light, Measure, and Tag.

| ID | Requirement | Verification | Status |
|---|---|---|---|
| MOD-001 | Rev A SHALL reserve an expansion concept and accessible packaging region but is not required to ship a detachable Scout Module. | CAD review | Deferred implementation |
| MOD-002 | A future dock SHOULD combine mechanical retention, power, data, module identification, and energy management. | Interface trade study | Deferred |
| MOD-003 | Module absence or failure SHALL NOT prevent the base device from booting. | Fault test | Locked architecture |
| MOD-004 | Module capabilities SHOULD be discoverable through the same capability model used for onboard sensors. | Architecture prototype | Deferred |
| MOD-005 | Supercapacitor-only or dock-charged single-capture modules remain research concepts and SHALL NOT be treated as a Rev A commitment. | Baseline review | Deferred |
| MOD-006 | Modules MAY use energy from the base device, a dedicated battery, a small local store, or harvesting only after the energy budget and safety behavior are documented. | Module-specific verification | Deferred |

## 9. Quality, reliability, safety, and privacy

| ID | Requirement | Verification | Status |
|---|---|---|---|
| QUAL-001 | The host build and automated tests SHALL pass before a release candidate is labeled verified. | CI/build record | Target |
| QUAL-002 | Target-hardware features SHALL remain marked unverified until exercised on the actual board or an accepted representative fixture. | Status review | Locked |
| QUAL-003 | A capture failure SHALL leave the previous accepted project artifact recoverable. | Fault-injection test | Target |
| QUAL-004 | Calibration data and software/firmware revision SHOULD be included with measurements that depend on them. | Export review | Target |
| SAFE-001 | The product SHALL provide no autonomous actuation of machinery in Rev A. | Architecture inspection | Locked |
| SAFE-002 | Sensor or inference output SHALL be framed as engineering assistance, not an unqualified safety certification. | UI/report review | Locked |
| SAFE-003 | The enclosure SHALL prevent ordinary user contact with energized conductors and retain the battery against movement or puncture. | Physical safety inspection | Target |
| PRIV-001 | Camera, project, and measurement data SHALL remain local by default. | Offline/privacy test | Locked |
| PRIV-002 | Any future network transfer SHALL be a deliberate user action with an identifiable destination. | Workflow review | Target |
| PRIV-003 | The product SHALL NOT conceal recording state during camera or audio capture. | UI/indicator test | Target |

Environmental ingress, drop height, operating temperature, chemical
resistance, ESD immunity, and regulatory targets are **Open**. Rev A SHALL NOT
claim a rating that has not been tested.

## 10. Contest and milestone constraints

| ID | Requirement | Verification | Status |
|---|---|---|---|
| CON-001 | The hardware application package SHALL include an original Fusion design/dataset (.f3d), preliminary BOM naming UNO Q and Fusion, original cover work, and English project copy. | Application checklist | Locked |
| CON-002 | The owner, not an agent, SHALL submit the Hackster application and final entry. | Process check | Locked |
| CON-003 | The hardware application target date is 2026-09-04 ahead of the reported 2026-09-07 deadline; the owner SHALL verify the live contest page. | Owner confirmation | Open external verification |
| CON-004 | The final contest submission target is 2026-12-16 through 2026-12-18 ahead of the reported 2026-12-20 deadline. | Submission record | Target |
| CON-005 | The contest enclosure and carrier design SHALL use Autodesk Fusion/Fusion Electronics. | Native files + exports | Locked |
| CON-006 | AI-generated concept sheets SHALL remain references only; contest-facing art and CAD SHALL be original work. | Submission review | Locked |

## 11. Rev A acceptance baseline

Platypus One Rev A is acceptable for the contest prototype when all of the
following are true:

1. A reviewable Fusion assembly packages the UNO Q envelope, selected display
   envelope, camera, ranging sensor, encoder, trigger, battery, USB-C exit, RF
   window, and major service clearances without unresolved hard interference.
2. The physical prototype can be held in the left hand, aimed, triggered, and
   navigated with the encoder without a grip change during a representative
   task.
3. PlatypusOS boots with absent optional hardware, reports capability
   availability, and runs at the actual display geometry.
4. At least one complete physical-observation workflow produces a saved local
   project record and a standard exported artifact.
5. The measurement/capture result distinguishes raw evidence, derived output,
   units, validity, and known limitations.
6. Power, thermal, display, camera, and selected sensor bring-up evidence is
   recorded against the hardware checklists.
7. A repeatable demonstration and recovery path exists; a failed capture does
   not destroy the previous accepted result.
8. Contest deliverables include native Fusion files, BOM, schematics where
   applicable, code, original photos/video, and a candid account of measured
   performance and limitations.

## 12. Open decisions and decision gates

| Decision | Needed by | Blocks |
|---|---|---|
| Exact DSI panel, FPC, touch controller, and Linux support | 2026-09-30 gate | aperture, display driver, enclosure depth |
| ToF: VL53L1X vs VL53L8CX | carrier freeze | placement, first ranging driver |
| IMU: BNO055 vs BMI270 | carrier freeze | placement, first IMU driver |
| Camera: UVC OV5640-class vs higher-resolution module | camera-path confirmation | barrel window, driver |
| Trigger switch technology | carrier/enclosure freeze | control placement |
| Expansion connector and reserved module envelope | carrier/enclosure freeze or explicit descope | module dock |
| Exact battery and validated power budget | enclosure freeze | grip volume, runtime |
| Production handedness strategy | after Rev A ergonomic test | future enclosure/control layout |
| Numeric measurement accuracy/precision thresholds | after sensor selection and calibration plan | published claims |
| Environmental and drop targets | post-contest product planning | material, sealing, compliance |

## 13. Traceability sources

This baseline consolidates, but does not replace:

- [PlatypusOS architecture](ARCHITECTURE.md)
- [Project status](../STATUS.md)
- [Roadmap](ROADMAP.md)
- [Industrial design notes](hardware/INDUSTRIAL_DESIGN.md)
- [Hardware BOM](hardware/BOM.md)
- [Hardware acquisition roadmap](hardware/ACQUISITION_ROADMAP.md)
- [Hardware application checklist](contest/HARDWARE_APPLICATION_CHECKLIST.md)
- [ADR-0001: dynamic linked prototype display](adr/0001-dynamic-linked-prototype-display.md)
- [ADR-0002: MIPI-DSI production display](adr/0002-dsi-production-display.md)
- [MCU bridge protocol](protocols/mcu-bridge.md)

When a source conflicts with this baseline, do not silently select one. Record
the conflict, determine which decision is newer, and update the baseline or
write an ADR.

## 14. Change control

- Requirement IDs are stable once this baseline is accepted.
- Wording may be clarified without changing intent.
- Adding, deleting, or materially weakening a SHALL requires owner approval.
- A cross-layer or hardware-direction change requires an ADR.
- A requirement may move to Deferred only with a documented consequence and
  recovery path.
- Verified status requires evidence; implementation alone is not evidence.

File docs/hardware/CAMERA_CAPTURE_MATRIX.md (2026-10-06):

# Camera capture matrix — IMX219 bench-off (#40)

Generated from [`tools/camera_characterize/matrix_spec.json`](../../tools/camera_characterize/matrix_spec.json)
(`camera_characterize.py plan`). Edit the spec, not this table, then regenerate.

**Distances (150 / 250 / 400 / 600 mm) are bench study points, not product
working distances.** The representative distance (250 mm) carries calibration,
repeatability, lighting and clutter cells.

## Operator rules (every camera)

1. Power off before connecting or swapping a module (CSI is not hot-pluggable).
2. Bring-up first: `tools/csi_bench/csi_bench.sh <SKU> all "notes"` (PR #42).
   Record enumeration, reboot repeat, cold power cycle and DSI/touch
   coexistence in `dataset.json → bringup` with the run directories as evidence.
3. `camera_characterize.py init datasets/<sku>-<date> --camera <SKU> --dataset-id <sku>-<date>`,
   then fill `camera` (silkscreen photo!), `platform` (repo SHA, `uname -a`,
   image, CSI port, enumeration), `physical` (calipers; `status: measured`)
   and the exposure/gain/focus defaults. Anything not known stays `UNKNOWN`.
4. Fixed exposure and gain for the whole dataset unless a cell says otherwise;
   record any change on the frame.
5. Focus: set once, record it, never touch it during the dataset
   (B0394 ring locked; B0390 fixed; B0393 `not_exposed` unless a lens control
   exists, then record its position on every frame).
6. `camera_characterize.py capture datasets/<dir> --command 'tools/camera_characterize/capture_raw.sh {out}'`
   walks the cells below. Failed or bad frames are discarded *with a reason*,
   never deleted.
7. Calibration set B comes after removing and re-installing the camera in its
   fixture with focus untouched: that is the stability test. The plan tags the
   two sets with distinct `mount_id`s. Never reuse a mount_id for a set taken
   without a real remount, because the gate counts only distinct mountings.
8. Measure and verify the printed targets (ChArUco square pitch over 6 squares,
   20 mm reference square, part with calipers) and set `status: verified` +
   `source`. Until then the analysis reports shape, never absolute accuracy.

Issue #40 IMX219 bench-off capture matrix. Distances are bench study points, not final product working distances.

## B0394 — 74 frames

Before the first frame: Set the M12 focus at the representative distance on the 20 mm square, lock it, photograph the ring. Record focus_mode=manual_locked and the ring position description. Do not touch focus until the dataset is finished.

| Cell | Distance (mm) | Scene | Placement | Lighting | Count |
|---|---|---|---|---|---|
| d150-ref-center | 150 | dimensional_reference | center | even | 2 |
| d150-ref-edge | 150 | dimensional_reference | edge | even | 2 |
| d150-charuco-center | 150 | geometry | center | even | 1 |
| d150-charuco-edge | 150 | geometry | edge | even | 1 |
| d250-ref-center | 250 | dimensional_reference | center | even | 2 |
| d250-ref-edge | 250 | dimensional_reference | edge | even | 2 |
| d250-charuco-center | 250 | geometry | center | even | 1 |
| d250-charuco-edge | 250 | geometry | edge | even | 1 |
| d400-ref-center | 400 | dimensional_reference | center | even | 2 |
| d400-ref-edge | 400 | dimensional_reference | edge | even | 2 |
| d400-charuco-center | 400 | geometry | center | even | 1 |
| d400-charuco-edge | 400 | geometry | edge | even | 1 |
| d600-ref-center | 600 | dimensional_reference | center | even | 2 |
| d600-ref-edge | 600 | dimensional_reference | edge | even | 2 |
| d600-charuco-center | 600 | geometry | center | even | 1 |
| d600-charuco-edge | 600 | geometry | edge | even | 1 |
| d250-calib-A | 250 | calibration | varied | even | 15 |
| d250-repeat | 250 | repeatability | center | even | 10 |
| d250-rotated | 250 | planar_part | rotated | even | 2 |
| d250-light-hard-shadow | 250 | lighting | center | hard_shadow | 2 |
| d250-light-low | 250 | lighting | center | low | 2 |
| d250-light-bright-overhead | 250 | lighting | center | bright_overhead | 2 |
| d250-clutter | 250 | clutter | center | even | 2 |
| d250-calib-B | 250 | calibration | varied | even | 15 |

## B0390 — 74 frames

Before the first frame: Fixed focus: record focus_mode=fixed.

| Cell | Distance (mm) | Scene | Placement | Lighting | Count |
|---|---|---|---|---|---|
| d150-ref-center | 150 | dimensional_reference | center | even | 2 |
| d150-ref-edge | 150 | dimensional_reference | edge | even | 2 |
| d150-charuco-center | 150 | geometry | center | even | 1 |
| d150-charuco-edge | 150 | geometry | edge | even | 1 |
| d250-ref-center | 250 | dimensional_reference | center | even | 2 |
| d250-ref-edge | 250 | dimensional_reference | edge | even | 2 |
| d250-charuco-center | 250 | geometry | center | even | 1 |
| d250-charuco-edge | 250 | geometry | edge | even | 1 |
| d400-ref-center | 400 | dimensional_reference | center | even | 2 |
| d400-ref-edge | 400 | dimensional_reference | edge | even | 2 |
| d400-charuco-center | 400 | geometry | center | even | 1 |
| d400-charuco-edge | 400 | geometry | edge | even | 1 |
| d600-ref-center | 600 | dimensional_reference | center | even | 2 |
| d600-ref-edge | 600 | dimensional_reference | edge | even | 2 |
| d600-charuco-center | 600 | geometry | center | even | 1 |
| d600-charuco-edge | 600 | geometry | edge | even | 1 |
| d250-calib-A | 250 | calibration | varied | even | 15 |
| d250-repeat | 250 | repeatability | center | even | 10 |
| d250-rotated | 250 | planar_part | rotated | even | 2 |
| d250-light-hard-shadow | 250 | lighting | center | hard_shadow | 2 |
| d250-light-low | 250 | lighting | center | low | 2 |
| d250-light-bright-overhead | 250 | lighting | center | bright_overhead | 2 |
| d250-clutter | 250 | clutter | center | even | 2 |
| d250-calib-B | 250 | calibration | varied | even | 15 |

## B0393 — 79 frames

Before the first frame: First run tools/csi_bench/csi_bench.sh B0393 probe and record whether a lens/VCM subdevice exists. If none: focus_mode=not_exposed for every frame (compatibility result). If one exists: record its focus position control value on every quantitative frame (motorized_position).

| Cell | Distance (mm) | Scene | Placement | Lighting | Count |
|---|---|---|---|---|---|
| d150-ref-center | 150 | dimensional_reference | center | even | 2 |
| d150-ref-edge | 150 | dimensional_reference | edge | even | 2 |
| d150-charuco-center | 150 | geometry | center | even | 1 |
| d150-charuco-edge | 150 | geometry | edge | even | 1 |
| d250-ref-center | 250 | dimensional_reference | center | even | 2 |
| d250-ref-edge | 250 | dimensional_reference | edge | even | 2 |
| d250-charuco-center | 250 | geometry | center | even | 1 |
| d250-charuco-edge | 250 | geometry | edge | even | 1 |
| d400-ref-center | 400 | dimensional_reference | center | even | 2 |
| d400-ref-edge | 400 | dimensional_reference | edge | even | 2 |
| d400-charuco-center | 400 | geometry | center | even | 1 |
| d400-charuco-edge | 400 | geometry | edge | even | 1 |
| d600-ref-center | 600 | dimensional_reference | center | even | 2 |
| d600-ref-edge | 600 | dimensional_reference | edge | even | 2 |
| d600-charuco-center | 600 | geometry | center | even | 1 |
| d600-charuco-edge | 600 | geometry | edge | even | 1 |
| d250-calib-A | 250 | calibration | varied | even | 15 |
| d250-repeat | 250 | repeatability | center | even | 10 |
| d250-rotated | 250 | planar_part | rotated | even | 2 |
| d250-light-hard-shadow | 250 | lighting | center | hard_shadow | 2 |
| d250-light-low | 250 | lighting | center | low | 2 |
| d250-light-bright-overhead | 250 | lighting | center | bright_overhead | 2 |
| d250-clutter | 250 | clutter | center | even | 2 |
| d250-calib-B | 250 | calibration | varied | even | 15 |
| d250-focus-rest | 250 | focus | center | even | 5 |

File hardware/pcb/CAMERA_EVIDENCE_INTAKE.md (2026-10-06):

# Camera evidence intake → Perception Head

The camera bench-off itself lives in #40 and its comparison table in
`docs/hardware/CSI_CAMERA_BENCH.md` (PR #42, tests T1–T10). **Do not duplicate
results here.** This page lists only what the head PCB consumes, so a result
can be dropped in and immediately unblock a design item. Fill a cell only with
a link to preserved evidence (image/JSON/photo/commit); otherwise leave `—`.

**Producer (2026-10-06):** `tools/camera_characterize` turns the #40 capture
matrix into `derived/<version>/report.md` + `decision.json`
([CAMERA_CHARACTERIZATION.md](../../docs/hardware/CAMERA_CHARACTERIZATION.md)).
Its per-camera **"PCB / Fusion handoff"** block carries the table B fields
(measured envelope, holes, optical-centre offset, connector side, cable),
the working-distance envelope, focus-access need and calibration stability
after remove/reinstall. Copy values here only from a physical-capture report
(never from the synthetic CI report) and link the report + its analysis
version. Role outputs map to table A: PROPOSED → value; CANDIDATES /
INSUFFICIENT EVIDENCE → leave `—`.

Additional head-relevant fields the report provides:

| Field | Report source | Feeds |
|---|---|---|
| Focus access (ring reachable / sealed / none / software-recorded) | handoff block, `focus_type` + `bringup.focus_control` | window/bezel, service cover |
| Calibration survives remove/reinstall (focal Δ between sets A/B) | `calibration_focal_rel_delta` | datum-hole scheme (Rev A goal 3) |
| Working-distance envelope (distances passing the edge-rise rule) | `working_envelope_distances` | baseline P2, illumination L2 |
| B0393 focus control on UNO Q | `focus_control_exposed` / `bringup.focus_control` (PR #42: no lens subdev) | whether AF is a product option at all |

## A. Decisions the head needs

| Output | Value | Evidence link | Unblocks |
|---|---|---|---|
| Reference / measurement camera | — | — | H4–H7 pattern, optical centre (M1) |
| Product candidate | — | — | Fusion head envelope |
| Fallback | — | — | — |
| Preferred working distance (mm) | — | — | baseline P2, illumination L2 |
| Focus behaviour accepted (fixed / locked manual / AF with recorded state) | — | — | calibration record fields |

## B. Physical data per module (MEASURE, calipers + photo over grid)

| Field | B0394 | B0393 | B0390 | Feeds |
|---|---|---|---|---|
| Board W × H × t (mm) | — | — | — | outline |
| Mounting hole centres (mm, from board corner) + Ø | — | — | — | H4–H7 footprint positions |
| Lens/holder height above board (mm) | — | — | — | front height limit, window gap |
| Lens outer Ø / holder footprint (mm) | — | — | — | keep-out |
| Optical centre offset from board centre (mm) | — | — | — | baseline, extrinsic seed |
| FFC connector side + cable type (15/22-pin) | — | — | — | P9 bend volume |
| Required clear aperture at window (from FOV) | — | — | — | window/bezel |

## C. Electrical / behavioural data (from #40 tests)

| Field | B0394 | B0393 | B0390 | Feeds |
|---|---|---|---|---|
| Enumerates + streams on Media Carrier (T1/T2) | link | link | link | keeps "camera on Media Carrier" decision |
| DSI + touch coexistence (T4) | link | link | link | ICD §1 |
| Current: preview / capture (T10) | — | — | — | power tree §3 |
| Calibration residual (T8) and repeatability after refocus/power cycle | — | — | — | calibration record design |
| Low-light behaviour (T9) | — | — | — | illumination need (L1/L2) |
| Glare with a bench LED at 2–3 offsets (new, optional) | — | — | — | light-board geometry (L3) |

## D. How results flow

1. Matthew fills #40 / CSI_CAMERA_BENCH.md with evidence.
2. Copy the PCB-relevant numbers into tables B/C with links.
3. Update [DECISION_REGISTER.md](DECISION_REGISTER.md) rows M1/M2 (and L2/L3 if illumination data exists).
4. Fusion places the camera + ToF optical centres ([MECHANICAL_FUSION_INPUTS.md](MECHANICAL_FUSION_INPUTS.md) §4).
5. Move H4–H7 in layout; nothing in the schematic changes for any of the three modules.

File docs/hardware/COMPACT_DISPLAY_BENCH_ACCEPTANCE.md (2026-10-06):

# Compact display bench acceptance (D0–D7)

For the leading candidate, the Waveshare 3.5inch DSI LCD (H). The same
procedure applies to the (E) with its `.panel` file. See the background in
[COMPACT_DISPLAY_SELECTION.md](COMPACT_DISPLAY_SELECTION.md).

- **Automation:** stages D1–D7 are automated where a machine can judge.
  The operator judges colours and touch position.
- **Evidence:** every run writes raw output plus `results.json` to
  `/var/lib/platypus-compact-display/evidence/<UTC>-<boot>/`.
- **Archiving:** copy that directory into the repo, or attach it to #41.
  A stage without preserved evidence did not happen.
- **PENDING** means the operator still owes an answer. It is never a pass.

## Before the panel arrives (nothing here changes the board)

1. On the UNO Q, build `display_probe` from this repo and put it on `PATH`.
   This is the same build as the 5" bring-up.
2. Clone upstream and check out the pinned commit:
   `git clone https://github.com/dcuartielles/uno_q_dsi_displays && git -C uno_q_dsi_displays checkout d633636527a213e884dae05468ffd355d12974f1`.
3. Install the tools: `sudo apt install device-tree-compiler i2c-tools v4l-utils`.
4. Record the 5" baseline once. This proves the fallback still works before
   anything changes:
   - run `display_probe`;
   - run `display_probe --input 10`;
   - save the output as `5in-baseline.txt`.

## Install (reversible)

```sh
sudo shutdown -h now                      # power OFF, swap the 5" for the 3.5" (D0 below)
# boot (5" overlay still installed; the 3.5" will be dark - expected)
sudo tools/compact_display/install_panel.sh ~/uno_q_dsi_displays
sudo reboot
```

`install_panel.sh` aborts before changing anything if any of these fail:

- the overlay does not compose against the board's DTB;
- the upstream checkout is not at the pinned commit;
- the carrier overlays are missing.

**Rollback:** `sudo tools/compact_display/restore_5in.sh ~/uno_q_dsi_displays && sudo reboot`.
Then repeat step 4 and compare against `5in-baseline.txt`.

## Stages

Run `sudo tools/compact_display/bench_accept.sh --boot-kind cold` after the
first boot. It runs every stage. `--stage Dn` re-runs one stage.

| Stage | Action | PASS (all of) | FAIL → first suspect |
|---|---|---|---|
| **D0 connect** | Power off. 22-pin end in the carrier DISPLAY connector exactly as the 5" photos ([DSI_BRINGUP.md](DSI_BRINGUP.md)). 15-pin end in the panel, contacts per the panel silkscreen. 5 V/3 A supply. Photo `D0-assembly.jpg` | Operator confirms; photo saved | — |
| **D1 identify** | Read the GT911 product ID (reg 0x8140) at the installed address and the other one. Probe 0x45 | `0x39 0x31 0x31` ("911") at the installed address, **and** nothing at 0x45 | No ID at either address → FFC orientation/seat, then 3V3 at the panel. ID only at the other address → reinstall (auto-detect picks it). 0x45 answers → a 5"/4.3" is still attached |
| **D2 boot** | Compare the slot overlay with the built one. Find our compatible in `/proc/device-tree`. Driver bound on the mipi-dsi device. Collect DSI/panel/goodix/CCI dmesg errors | Slot = build, node live, `panel-simple` bound | Not live → `arduino-linux-config carrier show`. Not bound → DKMS module did not load (`modinfo panel-simple \| grep platypus`) |
| **D3 enumerate** | `/sys/class/drm/card*-DSI-*` status and modes | `connected` with `480x800` | Connector absent → overlay graph. Mode wrong → panel-simple descriptor |
| **D4 render** | Stop the display manager; `display_probe --prefer dsi --pattern 25`; photo `D4-pattern.jpg` | Probe rc 0 at 480×800. **Operator:** red top-left, green top-right, blue bottom-left, white bottom-right, yellow frame on all 4 edges, no roll/flicker | Black with D3 PASS → panel not self-initialising on this host (main risk). Rolling/noise → link rate: retry with a lower `CLOCK_KHZ`. Swapped colours → format |
| **D5 touch** | Goodix in `/proc/bus/input/devices`; `display_probe --input 30`; tap TL, TR, BR, BL, centre | Device present **and** a `down` event inside each of the five 20 % zones | Device present, zero events → CCI 12-byte fault (Goodix fix not loaded). Points mirrored → add touchscreen-inverted/swapped props |
| **D6 repeat** | Each boot: rerun `--stage D6 --boot-kind cold\|warm`. Cold = supply unplugged ≥10 s; warm = `sudo reboot` | ≥5 cold **and** ≥5 warm boots since install, every one passing D1, D2, D3 and touch-device | Intermittent D1 → the CCI cold-boot outage seen upstream. Record which boot, and keep cycling to measure the rate |
| **D7 camera** | Pattern up; capture 90 frames (USB webcam auto, or `CAM_DEV=/dev/videoN`, or `CAM_CMD='…'` for the CSI module from #40); then 5-point touch again | Capture OK, no new DSI/CCI/goodix dmesg errors, DSI still connected, touch coverage still passes, operator saw no blanking | New CCI errors → polling vs camera bus contention: record, then compare with the touch driver unloaded |

**Overall PASS** = D0–D7 all PASS. The minimum to call the (H) *compatible*
is D1–D5 PASS. D6 and D7 decide whether it is *usable*.

## What a PASS does and does not mean

- **A PASS proves:** this panel unit, on this UNO Q image, with these files,
  shows correct pixels and takes touch, repeatably, alongside the camera.
- **A PASS does not prove:**
  - brightness or readability outdoors;
  - power headroom (POWER_TREE H2 measures that, with the panel lit);
  - mechanical fit;
  - long-run thermal behaviour;
  - behaviour after a kernel upgrade (DKMS rebuilds; rerun D2–D5 after one).

## After the run

1. Commit the evidence directory under `docs/hardware/evidence/compact-display-<date>/`.
2. In the selection doc, update the classes from BENCH REQUIRED to PROVEN or FAILED.
3. If D4 fails black on a working D3, stop. Restore the 5". Report on #41
   with `D2-dmesg-errors.txt`. The next candidate is the 4.3" (zero new software).

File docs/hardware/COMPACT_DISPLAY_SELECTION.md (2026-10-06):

# Compact display selection (3.5–4.0") — UNO Q + UNO Media Carrier

Issue: [#41](https://github.com/Matthewjg95/PlatypusOne/issues/41). Written 2026-10-05.
**None of the candidates below has been connected to our UNO Q.** This page
says what is known, how it is known, and what the bench has to show.

| Class | Meaning here |
|---|---|
| **PROVEN** | Observed on *our* UNO Q + Media Carrier (bench notes / photos / logs in this repo) |
| **DOCUMENTED** | Written in a manufacturer document, kernel source, Arduino schematic, or a third party's recorded result on an UNO Q |
| **INFERRED** | Our reasoning from documented facts; plausible, not shown |
| **BENCH REQUIRED** | Settled only by a stage in [the bench procedure](COMPACT_DISPLAY_BENCH_ACCEPTANCE.md) |
| **BLOCKED / UNKNOWN** | No source available; says what would unblock it |

Raspberry Pi support counts as DOCUMENTED for *the panel's own behaviour*
(timings, touch chip, what the host must send). It never counts as UNO Q
support: the Pi uses the vc4 DSI host and its own overlays, and the UNO Q
uses the Qualcomm MSM DSI host plus Arduino's overlays.

## Decision

**Leading candidate: Waveshare 3.5inch DSI LCD (H), SKU 33087** — 480×800
portrait IPS, GT911 touch, 15-pin FFC, 3.3 V only.

- **Recommendation:** buy one as a bench evaluation unit. This is not a product freeze.
- **Fallback:** the 4.3inch DSI LCD. It carries no software risk, because the
  community has verified it on an UNO Q with the same `.panel` file as our proven 5".
  It is larger, and it is landscape-native.
- **Reasons for the (H)** are in [§6](#6-decision-matrix).

#41 says not to *order or freeze* until the Fusion envelope study is done.
This recommendation is for one evaluation unit. Driver compatibility is the
open question here, and only a panel on the bench can answer it. The aperture
stays unfrozen until D0–D7 pass and the mock-up agrees.

## 1. What the proven 5" gives us (PROVEN, [DSI_BRINGUP.md](DSI_BRINGUP.md))

| Reusable piece | Reused for the (H)? | Notes |
|---|---|---|
| Media Carrier DSI0 + `5-dsi-touch-a` slot + `arduino-linux-config` | **Yes, unchanged** | Our overlay goes in the same slot; the 5" overlay is backed up first |
| 15-pin 1.0 mm → 22-pin 0.5 mm FFC, orientation photographed | **Yes** | The (H) has the same Raspberry Pi 15-pin pinout (DOCUMENTED, Waveshare wiki) |
| panel-simple descriptor build (upstream `20-build-drivers.sh`, `25-install-dkms.sh`) | **Yes** | Our `.panel` file uses the upstream format. Generated patch checked against mainline panel-simple.c (§5) |
| **Single DSI lane on the MSM host** | **Yes** | The proven 5" already runs 1 lane at 27.777 MHz × 24 bpp = **667 Mbit/s** (upstream `waveshare-800x480.panel`) |
| ATTINY regulator at 0x45 + FT5x06 touch at 0x38 | **No** | The (H) has neither: no host-controlled power, reset or backlight |
| `DrmDisplay`, `display_probe`, kiosk | **Yes** | Touch detection is generic (`EV_ABS` + `BTN_TOUCH`, scaled to mode), so GT911 needs no code. No backlight device → `setBacklight` returns NotSupported, and nothing calls it |
| Kiosk layout (ADR-0001 geometry-driven) | **Yes, extended** | Portrait path added (§7). Landscape output byte-identical to main |

## 2. Candidates

### 2.1 Waveshare 3.5inch DSI LCD (H) — SKU 33087 — LEADING

| Item | Value | Class / source |
|---|---|---|
| Size / active area | 3.5", VA 45.36 × 75.80 mm; lens 52.56 × 88.87; PCB 56 × 86.5 | DOCUMENTED (2D drawing) |
| Resolution / orientation | 480 × 800, **portrait-native** | DOCUMENTED (wiki, `Waveshare_35DSI.dtbo` 35H) |
| Lanes / bit rate | FFC wires 2 lanes; Waveshare's overlay drives **1**. 33.6 MHz × 24 / 1 = **806 Mbit/s** | DOCUMENTED / DERIVED |
| Connector | 15-pin 1.0 mm. Pins 2/3 D1, 5/6 CLK, 8/9 D0, 11/12 SCL/SDA, 14/15 3V3 | DOCUMENTED (wiki pin table) |
| Power | 3.3 V, 180 mA, from the FFC; no 5 V | DOCUMENTED (Waveshare FAQ) |
| Touch | GT911, 5-point. Overlay lists 0x14 **and** 0x5d; wiki shows `10-0014 Goodix`. **No INT or RST on the FFC** | DOCUMENTED |
| Controller / init | **None from the host.** The Pi overlay is `vc4-kms-dsi-generic` with timings only: no regulator, reset GPIO, backlight or init sequence | DOCUMENTED (decompiled overlay → [reference JSON](../../tools/compact_display/reference/waveshare_35dsi_overrides.json)) |
| Backlight | Not adjustable; always on | DOCUMENTED |
| DT / DRM path on UNO Q | panel-simple descriptor (private compatible) + polled goodix + our overlay | INFERRED (§4); BENCH D2–D5 |
| Adapter | **Passive**: the proven 15→22 cable | DOCUMENTED (pin match) / BENCH D0–D1 |
| UNO Q software work | Done in this PR (`tools/compact_display/`); upstream Goodix CCI fix reused | — |
| Mechanics | Portrait. 56 mm PCB → 72 mm head with 8 mm edges, inside the 75–85 band. FFC exits the top short edge (STEP) | DOCUMENTED / DERIVED |

### 2.2 Waveshare 3.5inch DSI LCD (E) — SKU 33086

**Electrically and in software, a sibling of the (H):**

- same `Waveshare_35DSI.dtbo` (35E override);
- 1 lane at 24 MHz → 576 Mbit/s, *below* the proven 667;
- the same GT911 with no INT, and no controller;
- 640 × 480 landscape; VA 70.67 × 53.27; PCB 77 × 65.

`panels/waveshare-3in5-dsi-e.panel` is prepared and tested. Nothing on I2C
distinguishes it from the (H), so it carries no detect keys.

**Why it is not leading:**

- Landscape, 77.27 mm wide → 93.3 mm head. That is over the 75–85 band.
- Mounting it portrait needs software rotation, which `DrmDisplay` does not have.
- The 640×480 kiosk layout truncates the title in the side panel (§7).
- Its lower bit rate makes it the lower-*electrical*-risk 3.5". If the (H)
  fails at 806 Mbit/s but works with a slower clock, the (E) becomes interesting.

### 2.3 Waveshare 4-DSI-TOUCH-A — SKU 34354

**Panel (DOCUMENTED, Waveshare docs + `panel-waveshare-dsi-v2.c`):**

- 4.0", 480 × 800 portrait-native, ST7701S, GT911;
- **2 lanes**, video + HSE + LPM, non-continuous clock;
- a vendor **init sequence** sent by the host;
- **5 V 4.75–5.25 V, ≥180 mA input that the Media Carrier DSI connector does not carry**;
- software backlight through the panel's controller;
- 108.30 × 65.10 × 7.9 mm aluminium back, 8× M2.5.

**Software:** the compatible `waveshare,4.0-dsi-touch-a` exists **only in
`rpi-6.18.y`** (absent from 6.12–6.17). The upstream "derived panel" route
(as used for the community-verified 4-DSI-TOUCH-C) is the plausible path:
port the driver, plus an overlay derived from Arduino's 10.1" one
(INFERRED, not attempted).

**Risks:**

- the init sequence must survive the MSM host;
- the driver is new code on a 7.0 kernel;
- 5 V needs its own wire, or a Host Carrier provision;
- it is 108 mm tall.

**Status:** medium risk. Fallback if 3.5" proves too small in the mock-up.

### 2.4 Waveshare 2.8inch DSI LCD — SKU 22028 (lower bound)

- 480 × 640, VA 58.0 × 43.6, glass 71.3 × 52.9 (DOCUMENTED).
- The photographed PCB carries an **ICN6211** bridge (the 5" family) and has
  software backlight.
- Its exact host-side driver/overlay is **BLOCKED/UNKNOWN**: the wiki was not
  decoded this sprint.
- Reference only. It is smaller than the (H) in active area by 26 % and
  brings no electrical advantage.

### 2.5 Waveshare 4.3inch DSI LCD (fallback, not in the brief's list)

**DOCUMENTED (third-party UNO Q result):** upstream `waveshare-800x480.panel`
records the 4.3" verified on an UNO Q + Media Carrier, kernel 7.0.0, on
2026-09-08 (800×480, backlight, touch, no DSI errors). It is the same
definition as our proven 5", so for us it is **zero new software**.

**Mechanics:**

- PCB 106 × 68, depth 14.05 mm.
- Landscape-native, so portrait mounting needs rotation (84 mm head).
- Landscape mounting means a 122 mm wide head.

This was the #43 "next to buy" choice. It still separates size from driver,
but it is the larger size we are trying to leave.

### 2.6 Excluded

Waveshare 4-DSI-TOUCH-C (community-verified on UNO Q) and the other
round/square panels are excluded. Their glass is round or square, and their
outline works against the compact head (#41 comment 3).

## 3. Electrical compatibility

**Media Carrier DSI0** (Arduino ASX00083 datasheet §4.5; schematic sheet "DSI FLAT"):

- 22-pin 0.5 mm, 4 lanes + clock;
- I2C through a TCA9406 level shifter onto the SoC **CCI** controller;
- 3.3 V from the UNO Q `PWR_3P3V` buck (3.1–3.5 V; ABX00162 datasheet);
- **no GPIO lines**.

So a panel needing a host-driven reset, interrupt, enable or 5 V cannot get
it from this connector.

| | (H) | (E) | 4-DSI-TOUCH-A | 4.3" DSI LCD |
|---|---|---|---|---|
| Supply needed | 3V3 180 mA | 3V3 (not stated; INFERRED ≈ (H)) | **5 V ≥180 mA (extra wire)** | 3V3 (proven path) |
| Lanes used | 1 | 1 | 2 | 1 |
| Per-lane rate | 806 Mbit/s | 576 | ≈ (ST7701 mode) | 667 |
| Needs host GPIO | no | no | via its 0x45 controller (I2C) | via ATTINY 0x45 (I2C) |
| Touch IRQ | none → polling | none → polling | via controller | FT5x06 polled (proven) |
| Adapter | passive 15→22 | passive 15→22 | 22-pin direct + 5 V lead | passive 15→22 |

**INFERRED risks for the (H):**

1. **806 Mbit/s on one lane** is 21 % above the rate proven on this host (667).
   We hold no QRB2210 DSI PHY rate limit from Arduino or Qualcomm documents,
   and no UNO Q data above 667.
   *Mitigation:* if D3 passes and D4 rolls or tears, try a lower `CLOCK_KHZ` in
   the `.panel`. The panel's own tolerance is unknown.
2. **180 mA on `PWR_3P3V`**, a rail that also feeds the STM32, ANX7625 and Wi-Fi.
   Arduino gives no spare-capacity figure. The 5" (backlight also from 3V3) is
   already running from it, unmeasured.
   *Action:* POWER_TREE H2 measurement.
3. **Self-initialisation.** The Pi sends no init commands, so none are needed.
   But the vc4 host might send something implicit in its LP-to-HS handover
   that the MSM host does not. *Settled by:* D4.

## 4. DSI / touch / Linux DT

**DT path (INFERRED):**

```
&cci_i2c0  : goodix,gt911 @0x14, touchscreen-size 480x800, NO interrupts/reset
&mdss_dsi0 : vdda-supply=&pm4125_l5; panel@0 compatible "platypus,waveshare-3in5-dsi-h"
&mdss_dsi0_out : remote-endpoint=&panel_in; data-lanes=<0>
```

- These are the same three targets and the same supply as the upstream overlay
  running our 5" (PROVEN path). It drops the ATTINY regulator, backlight and
  edt-ft5x06 nodes, and adds the Goodix node.
- The upstream generator cannot express this. It drops touch whenever there is
  no panel controller, hence our
  [`gen_overlay.py`](../../tools/compact_display/gen_overlay.py).
- **Panel driver:** mainline `panel-simple` has no generic DSI "timings from DT"
  panel, so the descriptor is compiled in. This is the same mechanism as the
  proven 5". The compatible is private, so nothing built in can win the bind
  race (the lesson of upstream's 4-DSI-TOUCH-C notes).
- **Touch:** mainline `goodix.c` falls back to `input_setup_polling` at 17 ms
  when `client->irq <= 0` (DOCUMENTED, source read).
  - Without a reset GPIO the driver cannot choose the address. It uses whatever
    the GT911 latched at power-up. Hence `install_panel.sh` reads the product ID
    at both 0x14 and 0x5d before generating the overlay.
  - Goodix reads exceed the CCI controller's 12-byte limit. The upstream fix
    (`17-install-goodix-fix.sh`, measured by its author on an UNO Q) is reused.
- **Polling cost:** every 17 ms on the bus that also serves the carrier's
  devices. Camera CCI coexistence is D7. Whether a CSI camera shares this CCI bus
  is UNKNOWN; bench required.
- **Rotation:** none needed for the (H) in a portrait head. Both 3.5" panels
  need `touchscreen-size` only; no swap/invert properties are expected.
  D5 corner taps check this.

## 5. Software prepared (reversible) — `tools/compact_display/`

| File | What it does | Verified here |
|---|---|---|
| `panels/waveshare-3in5-dsi-h.panel`, `…-e.panel` | Upstream-format panel definitions + GOODIX/detect keys, every value sourced in the header | Unit tests vs the decoded vendor overlay; 60.0 Hz; bit rates |
| `gen_overlay.py` | Controller-less overlay generator | Overlays compile with `dtc -@`; fixups for `cci_i2c0`, `mdss_dsi0`, `mdss_dsi0_out` |
| `install_panel.sh` | Pre-flight → backup → GT911 address probe → generate → `fdtoverlay` test-compose against the board's DTB (aborts before changing anything) → upstream driver build + Goodix fix → slot install + enable | `--dry-run` in CI; shellcheck. **Never run on a board** |
| `restore_5in.sh` | Re-runs the exact proven 5" install; `--offline` restores backed-up overlay + module binaries | shellcheck. **Never run on a board** |
| `bench_accept.sh` | Stages D0–D7 → evidence dir + `results.json` | shellcheck. **Never run on a board** |

The upstream `gen-panel-patch.py` (pinned d633636) was run against mainline
`panel-simple.c` with the (H) `.panel`. It inserts a 480×800 descriptor:
htotal 640, vtotal 875, 33.6 MHz → 60.0 Hz, 1 lane, RGB888, `MODE_VIDEO`.
This shows the patch applies textually. It was not compiled against the
UNO Q kernel headers.

The proven 5" config is not modified. `install_panel.sh` copies the 5" slot
overlay, carrier settings and module hashes and binaries to
`/var/lib/platypus-compact-display/backup-<UTC>/` before it touches anything.
The 5" and the compact panel cannot both be installed: they share one slot,
and panel-simple carries one generated descriptor. Switching is reinstall + reboot.

## 6. Decision matrix

Scores run 1–5, where 5 is best. Weights reflect #41: size first, then integration risk.

| Criterion (weight) | 3.5" (H) | 3.5" (E) | 4-DSI-TOUCH-A | 4.3" DSI LCD | 2.8" |
|---|---|---|---|---|---|
| Fits SM1 portrait head band 75–85 mm (×3) | **5** (72 mm, spare) | 2 (93 mm landscape) | 4 (81 mm) | 3 (84 mm, rotation) | 5 |
| Usable UI area (×2) | 3 (45×76 mm) | 3 (71×53) | 4 (52×86) | 5 | 1 |
| Electrical simplicity on DSI0 (×2) | **5** 3V3 only, passive | **5** | 2 (+5 V wire) | **5** (proven) | 3 (unknown) |
| UNO Q software risk (×3) | 3 (generic panel, no init; new overlay) | 3 (same; lower bit rate) | 2 (init seq + 6.18 driver port) | **5** (community-verified; our 5" def) | 1 (unknown) |
| Native orientation matches portrait head (×1) | **5** | 1 | **5** | 1 | 4 |
| Brightness / backlight control (×1) | 2 (270 cd/m², fixed) | 2 (fixed) | 4 (software) | 4 (software) | 4 |
| Mechanical data quality (×1) | **5** (2D + STEP) | 4 (2D) | 4 | 3 | 3 |
| **Weighted total (/65)** | **52** | 38 | 43 | 52 | 37 |

**The (H) and the 4.3" tie.** The tie breaks on the brief:

- the target is 3.5–4.0", with 3.5 preferred;
- the 4.3" is the size #41 was opened to leave;
- the 4.3" needs rotation work in a portrait head.

So the 4.3" is the **fallback**, and its value is precisely that it needs no
new driver work.

The 4-DSI-TOUCH-A ranks third. It is credible, but its 5 V lead and driver
port make it a deliberate second step only if 3.5" proves too small in the
mock-up.

## 7. Kiosk portrait finding (software, host-verified)

`scout_kiosk --offscreen-size WxH` renders the real loop at any geometry.
`computeLayout` now stacks preview over panel when height > width.
Landscape takes the original path unchanged: the 800×480 output is
byte-identical to main.

- **480×800:** usable without change (CI smoke added).
- **640×480 (the (E)):** the side panel truncates "ENGINEERING SCOUT".
  This is recorded, not fixed. It belongs to UI work, which is out of scope.

## 8. Risks and what retires them

| Risk | Class | Retired by |
|---|---|---|
| (H) does not light without Pi-specific init | INFERRED | D3 (mode) + D4 (pixels) |
| 806 Mbit/s single lane unstable | INFERRED | D4 photo + D6 repeat; fallback lower clock / (E) |
| GT911 address varies by unit / boot | DOCUMENTED (both listed) | D1 + D6 (address logged each boot) |
| Polled touch misses taps or loads CCI | INFERRED | D5 corner coverage, D7 |
| 3V3 rail headroom with 180 mA panel | INFERRED | POWER_TREE H2 (measure with panel + camera) |
| Always-on backlight (no dimming → power, glare) | DOCUMENTED | Accept for Rev A, or the 4-DSI-TOUCH-A later |
| Cold-boot CCI outage seen upstream on ATTINY panels | DOCUMENTED (upstream) | D6 cold boots. No ATTINY here, so only touch can be affected |
| FFC route length/bend in the head | UNKNOWN | Fusion route → cable length (MECHANICAL inputs) |

## 9. Mechanical inputs for Fusion

[`compact_display_mechanical.csv`](compact_display_mechanical.csv) is in Fusion
Parameter I/O format, with the same naming and `disp_edge_min` as PR #43's
`rev_a_sm1_parameters.csv`. It fills the 3.5" rows #43 left UNRESOLVED:

- outline;
- active area and its offset (the (H) VA sits 3.63 mm from the top and 9.44 mm from the bottom);
- depth;
- hole pattern (49 × 58, the Raspberry Pi pattern);
- FFC edge and position.

**Effect on the SM1 proportions:**

- The (H) is narrower than every other candidate: 72 mm with 8 mm edges.
- The head band (75–85) is kept. The spare 3–13 mm is left to the mock-up
  (grip, edge margin); it is not spent.
- 88.9 mm of glass leaves 36–56 mm of the 125–145 mm height for the sensor
  flange and controls.
- The FFC leaves at the top edge, toward the sensor flange. Fusion must route
  it past the camera/ToF datum bracket without loading it.

The enclosure is not redesigned here.

## 10. Bench queue

See [COMPACT_DISPLAY_BENCH_ACCEPTANCE.md](COMPACT_DISPLAY_BENCH_ACCEPTANCE.md).

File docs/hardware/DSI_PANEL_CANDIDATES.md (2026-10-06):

# UNO Q DSI panel candidates

> **Compact display (3.5–4.0"), 2026-10-05:** superseded for panel choice by
> [COMPACT_DISPLAY_SELECTION.md](COMPACT_DISPLAY_SELECTION.md) — leading
> candidate Waveshare 3.5inch DSI LCD (H), bench procedure
> [COMPACT_DISPLAY_BENCH_ACCEPTANCE.md](COMPACT_DISPLAY_BENCH_ACCEPTANCE.md).
> The 5" stays the development fixture and software fallback.

> **Bench reality, 2026-09-28:** the panel actually in hand is the Waveshare
> *5inch DSI LCD* (800×480, ICN6211, 15-pin FPC), not Candidate A below, and the
> board image predates the carrier overlays. The executable plan for the
> hardware on the bench is [DSI_BRINGUP.md](DSI_BRINGUP.md).

**Research date:** 2026-08-25  
**Decision state:** DSI architecture remains selected; exact panel selection is conditional.

## Recommendation

Use the **Waveshare 5-DSI-TOUCH-A** as the first hardware proof-of-life
candidate, through the **Arduino UNO Media Carrier (ASX00083)**. It is the only
panel in the 4.3–5 inch target range for which the current UNO Q configuration
tool ships a named device-tree profile.

This changes the expected production geometry from “800×480-class landscape”
to **720×1280 native portrait, rendered as 1280×720 landscape if rotation is
supported by the compositor/application**. Do not freeze the enclosure around
this panel yet. Freeze only after the bench test below proves display, touch,
rotation, suspend/resume, and backlight control.

The DSI path is technically credible, but procurement is **not yet cleared**:

- Arduino's store listed the Media Carrier at €19.89 but “Coming Soon” and
  “Sold out” on the research date.
- The 5-inch panel is orderable from Waveshare, but its exact mechanical drawing
  still needs to be captured into the Fusion model before enclosure freeze.
- The current Arduino profile names this specific Waveshare family; generic
  Raspberry Pi DSI compatibility is not enough to establish UNO Q support.

If the Media Carrier cannot be obtained, or the proof-of-life test fails by the
existing **2026-09-30** gate, activate the ESP32-S3 RGB bridge fallback in
ADR-0002.

## What the UNO Q actually exposes

The UNO Q board does not expose a directly usable display FFC. Its raw
multimedia signals are on the underside **JMEDIA/JMISC high-speed board-to-board
connectors**. The supported breakout is the UNO Media Carrier.

The current carrier documentation establishes:

| Item | Verified value |
|---|---|
| Carrier | Arduino UNO Media Carrier, SKU **ASX00083** |
| Host connection | JMEDIA + JMISC underside connectors |
| Display receptacle | DSI0, **22 contacts, 0.5 mm pitch, four-lane-capable** Raspberry Pi “mini” FFC form |
| Logic | SoC control signals are in the **1.8 V** domain |
| Display interface | MIPI-DSI; touch/control uses the panel's I²C path |
| Carrier outline | 68.58 × 53.34 mm |
| Carrier power | Host rails; optional 7–24 V input for high-power configurations |
| Published receptacle MPN | **Not identified in Arduino's public datasheet/manual** |

The public Arduino material describes the DSI connector by physical/interface
class, but does not give its manufacturer part number or a text pin-by-pin table.
The safe design contract is therefore the documented Raspberry Pi-compatible
22-pin/0.5 mm interface and an included vendor cable—not an assumed receptacle
MPN. Obtain the ASX00083 schematic/CAD package and verify the footprint before
copying this connector onto any custom carrier.

The carrier is not merely a passive convenience. It supplies level translation,
power-control circuitry, and the supported physical path from the UNO Q's
high-speed connectors. A custom FFC adapter should not be the Rev A plan.

Sources:

- [UNO Media Carrier user manual](https://docs.arduino.cc/tutorials/uno-media-carrier/user-manual)
- [UNO Media Carrier datasheet source](https://github.com/arduino/docs-content/blob/main/content/hardware/02.uno/carriers/uno-media-carrier/datasheet/datasheet.md)
- [UNO Media Carrier store page](https://store.arduino.cc/products/uno-media-carrier)
- [Raspberry Pi 22-pin connector description](https://www.raspberrypi.com/documentation/computers/compute-module.html)

## Candidate comparison

Prices and availability are snapshots from manufacturer storefronts on
2026-08-25; re-check before ordering.

| Candidate | Mechanical/display facts | FFC / electronics | Current price | UNO Q Linux assessment |
|---|---|---|---:|---|
| **A. Waveshare 5-DSI-TOUCH-A** | 5 inch IPS, 720×1280 native portrait, optical bonding, five-point capacitive touch | 22-pin DSI family; panel profile is shipped by Arduino | **$34.95–36.99**, listed for purchase | **Recommended.** Exact named profile exists: `display=5-dsi-touch-a`. Still requires bench validation and landscape rotation validation. |
| **B. Waveshare 4.3-DSI-TOUCH-A** | 116.50 × 68.90 mm outline; 93.60 × 56.16 mm active area; 480×800 native portrait; 500 cd/m²; ST7701S + GT911; five-point touch | MIPI two-lane; kit includes reverse-contact 22-pin 0.5 mm FFCs; separate 5 V input documented | **$28.99**, Add to Cart | **Plausible, not supported.** Connector class and chips are credible, but no UNO Q profile exists. It needs a new panel/touch overlay and proof that the carrier's power/control routing matches. |
| **C. DFRobot DFR0550-V2** | 120.7 × 75.8 × 4.9 mm; 108.0 × 64.8 mm active area; 800×480; 550 cd/m²; optical bonding; five-point touch | Raspberry Pi DSI; 3.3 V, about 700 mA; supplied with 50 mm and Pi 5 300 mm ribbon cables | **$49.90**, orderable | **Low confidence.** Attractive mechanical fit and exact legacy resolution, but DFRobot documents Raspberry Pi compatibility only and Arduino ships no profile. Controller identity and UNO Q initialization sequence remain unverified. |

Candidate sources:

- [Waveshare 5-DSI-TOUCH-A product page](https://www.waveshare.com/5-dsi-touch-a.htm)
- [Waveshare 4/4.3-DSI-TOUCH-A product page](https://www.waveshare.com/4-dsi-touch-a.htm)
- [Waveshare DSI interface notes](https://docs.waveshare.com/Displays/LCD/DSI)
- [Waveshare 4.3-DSI-TOUCH-A technical page](https://docs.waveshare.com/4.3-DSI-TOUCH-A)
- [DFRobot DFR0550-V2 product page](https://www.dfrobot.com/product-2791.html)

### Why Candidate A wins

Arduino's current software registry is decisive. It explicitly provides
`5-dsi-touch-a`, `8-dsi-touch-a`, and `10-dsi-touch-a` display options for
the Media Carrier. Candidate A is the sole 4.3–5 inch option on that list.

Candidate B is the more compact industrial-design fit, and Candidate C preserves
the existing 800×480 assumption, but both would turn panel selection into kernel
integration work. Waveshare itself warns that DSI requires driver and
initialization support and that screens are not generally interchangeable.
Matching connector pitch and lane count therefore does not clear either panel.

The 5-inch portrait panel's resolution is not a renderer blocker because
PlatypusOS already treats display geometry as runtime data. It is, however, a
mechanical and UX change that must be tested before the housing is frozen.

## Debian/device-tree path

Do **not** hand-edit `config.txt` or manually install Raspberry Pi overlays on
the UNO Q. Arduino provides `arduino-linux-config`, which composes the
board-specific overlays into the boot DTB.

Expected workflow on a current UNO Q image:

```bash
sudo arduino-linux-config carrier list

sudo arduino-linux-config carrier enable media-carrier \
  display=5-dsi-touch-a

sudo arduino-linux-config carrier show media-carrier
sudo reboot
```

The current Arduino registry maps that option to:

```text
qrb2210-arduino-imola-carrier-media.dtbo
qrb2210-arduino-imola-carrier-media-panel-5in_touch_a-dsi.dtbo
```

It also marks the USB-C video/sound overlay incompatible with the DSI profile.
Internally, the tool runs `fdtoverlay` against
`/boot/efi/dtb/qcom/qrb2210-arduino-imola-base.dtb` and atomically replaces
`/boot/efi/dtb/qcom/qrb2210-arduino-imola.dtb`; the change takes effect after
reboot. Use the CLI/UI rather than reproducing that implementation manually.

Sources:

- [Arduino Linux Config CLI](https://github.com/arduino/arduino-linux-config)
- [UNO Q Media Carrier registry](https://github.com/arduino/arduino-linux-config/blob/main/internal/registry/registry.go)
- [Overlay application implementation](https://github.com/arduino/arduino-linux-config/blob/main/internal/dto/apply.go)

## Proof-of-life acceptance test

Order only the panel and carrier for the first pass. Do not commit the enclosure
or a custom carrier PCB until all checks pass.

1. Photograph labels, both FFC ends, contact orientation, and carrier/display
   connector orientation before assembly.
2. With power removed, install the Media Carrier and the panel using the supplied
   reverse-contact 22-pin cable.
3. Power from a supply with adequate headroom and enable
   `display=5-dsi-touch-a`.
4. After reboot, record:
   - `arduino-linux-config carrier show media-carrier`
   - `uname -a`
   - `cat /proc/device-tree/model`
   - `ls /sys/class/drm`
   - `dmesg` lines for DSI, DRM, panel, backlight, and touch
   - `libinput list-devices` or equivalent touch enumeration
5. Verify cold boot output, 30-minute display stability, all touch points,
   coordinate alignment, backlight adjustment, and three reboot cycles.
6. Verify application rendering in native portrait and intended landscape
   orientation. Record the physical active area and bezel with calipers.
7. Verify USB-C charging/data behavior while DSI is active; do not assume the
   incompatible USB-C video overlay implies all USB-C functions are unavailable.
8. Suspend/resume if the product image supports suspend, then repeat touch and
   backlight checks.

Pass criteria:

- No repeated DSI/DRM/panel errors in `dmesg`.
- Full-frame output with no clipping or persistent flicker.
- Touch is enumerated automatically and maps correctly after rotation.
- Backlight is controllable and survives reboot.
- The measured stack fits the intended barrel/display envelope.
- USB-C retains the charging/data behavior needed by the product.

## Order and fallback gates

| Gate | Result |
|---|---|
| At least two purchasable 4.3–5 inch candidates documented | **Pass** |
| A candidate has a shipped UNO Q software profile | **Pass: 5-DSI-TOUCH-A** |
| Media Carrier immediately purchasable from Arduino | **Fail on research date: Coming Soon / Sold out** |
| Exact production mechanical stack verified | **Pending hardware** |
| DSI + touch proof-of-life on UNO Q | **Pending hardware** |

Recommended order when available:

1. Arduino UNO Media Carrier ASX00083.
2. Waveshare 5-DSI-TOUCH-A, panel-only configuration with supplied FFCs.
3. No alternate panel in the first order; use the bench result to decide whether
   compactness justifies funding a custom 4.3-inch overlay.

Keep the 2026-09-30 fallback gate. Trigger fallback if the carrier is still
unobtainable, Candidate A cannot pass the acceptance test, or its rotated
mechanical envelope is incompatible with the industrial design.

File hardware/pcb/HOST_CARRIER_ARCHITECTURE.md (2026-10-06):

# Host / Power / Controls Carrier (board B) — architecture only

Status: **architecture + interfaces, no layout.** Physical layout waits for
the compact-display decision (#41) and measured system power (P1/H2).
The UNO Media Carrier remains the multimedia reference platform.

## Responsibilities

| Function | Direction | Notes / open items |
|---|---|---|
| Battery + protection + charging | required | Battery **not sized** (POWER_BATTERY_REFERENCE.md gate). Pack class (2S/3S smart pack vs 1S) drives topology. |
| System 5 V rail | required | Feeds UNO Q (5 V pin or DC_IN 7–24 V path — choose after H1), display, head (allocate ≥1 A for head). |
| Power path | required | USB-C charge-while-operating; soft power switch; brown-out safe shutdown signal to UNO Q. |
| Perception-head connection | required | Mates head J1 (JST GH 14 for Rev A); routes ICD signals to MCU pins once frozen. |
| Trigger | required | MCU GPIO with hardware debounce (RC) + EXTI; wake-capable pin. |
| Rotary encoder + push | required | Needs a timer CH1/CH2 pair in encoder mode (e.g. TIM3: D8/PB4 + A2/PA6 candidate); keep out of the head's candidate pins. |
| Buttons (2–3) | required | MCU GPIO or I2C expander on bus A. |
| Service/debug | required | USB-C pass-through, UART console (JCTL SE4 is **1.8 V** — level-shift), test points on rails, SWD only if exposed by UNO Q. |
| Compact display adaptation | only if needed | Native 22-pin DSI via Media Carrier preferred. Leading 3.5in (H) needs **none** (3V3 + I2C + 1 lane over the passive 15→22 cable); a 5 V lead only if the 4-DSI-TOUCH-A fallback is chosen ([selection](../../docs/hardware/COMPACT_DISPLAY_SELECTION.md)). |
| Media Carrier replacement/consolidation | deferred | Only if packaging forces it; would bring CSI/DSI routing onto our board — explicitly not Rev A. |

## Interfaces

- **To UNO Q:** standard UNO headers (JDIGITAL/JANALOG/Qwiic) for MCU-domain
  signals; power via 5 V pin or DC_IN. Do not use 1.8 V SoC GPIO without
  translation; never use CCI I2C or MI2S pins as GPIO.
- **To head:** [ICD_PERCEPTION_HEAD.md](ICD_PERCEPTION_HEAD.md) — the head's
  signal list is the contract; the host carrier adapts to it.
- **To display:** Media Carrier DSI0 (no change for Rev A).
- **To battery:** pack connector + SMBus (if smart pack) to MCU bus A or a
  dedicated bus — decide with the pack.

## Gates before layout

1. Display panel + driver path chosen (#41) and its 5 V load measured.
2. System power matrix measured (POWER_TREE_REV_A.md §4) → battery class.
3. Head ICD pins frozen (H6) and encoder/trigger pins allocated without conflicts.
4. Fusion gives the board envelope, connector positions and cable routes.

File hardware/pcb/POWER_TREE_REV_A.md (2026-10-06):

# Perception Head Rev A — power tree (preliminary)

Status 2026-10-05. Classes: **KNOWN** (manufacturer document) ·
**MEASURED** (preserved Platypus One bench evidence) · **ESTIMATED** (stated
engineering estimate, reason given) · **UNKNOWN** (needs a measurement).
Do **not** size the battery from this file. Sources: [ledger](RESEARCH_LEDGER.md).

**MEASURED values preserved in the repository: none.** (Searched docs and
evidence folders on 2026-10-05; the power matrix in
[POWER_BATTERY_REFERENCE.md](../../docs/hardware/POWER_BATTERY_REFERENCE.md)
is still all TBD.)

## 1. Rail tree

```
UNO Q 5V_USB_VBUS (JANALOG 5) ──J1.1/2──┬─ D1 SMF5V0A TVS
                                        └─ SH1 0.05 Ω ── +5V_HEAD ──┬─ U1 TLV758P (EN = TOF_PWR_EN, default OFF)
                                                                    │     └─ 3.29 V TOF_LDO_OUT ── SH2 0.1 Ω ── +3V3_TOF ── Pololu #3419 VIN
                                                                    │                                   (carrier LDOs → AVDD 3.3 V, CORE/IOVDD 1.8 V)
                                                                    └─ U3 TPS2553 (EN = ILLUM_EN, default OFF, limit ≈0.65 A)
                                                                          └─ +5V_ILLUM ── J3/J4 light boards ── Q1/Q2 + 1 Ω sense (linear CC sinks)
UNO Q PWR_3P3V (Qwiic 2 / JANALOG 4) ──J1.5── SH3 1 Ω ── +3V3_LOGIC ── BMI270 · AT24CS32 · TCA9534 · TLV9062 · pull-ups · status LED
```

Design intent: almost nothing on the UNO Q's shared 3.3 V buck (which also
feeds the STM32, ANX7625 and Wi-Fi); ToF and LEDs ride on 5 V where the USB-C
contract (5 V/3 A) is the documented limit.

## 2. Head loads

| Load | Rail | Typical | Max / peak | Class | Basis |
|---|---|---|---|---|---|
| VL53L8CX active ranging (via Pololu VIN) | +3V3_TOF ← +5V_HEAD | 100 mA | 150 mA peak | KNOWN | Pololu #3419; consistent with ST DS Table 12 (AVDD 43/50 + CORE 50/80 mA, +10 mA peaks) and AN5897 (215 mW typ / 320 mW max in the sensor) |
| VL53L8CX HP idle | +3V3_TOF | ~4 mA | ~19 mA | KNOWN | DS Table 12 (AVDD 1/1.6, CORE 3/17 mA) + shifter |
| ToF rail off | — | 0 | back-feed only | ESTIMATED | active discharge LDO; T5 to measure |
| U1 LDO dissipation | — | 0.17 W | 0.26 W (ΔTj ≈ 45 °C @ RθJA 176.9 °C/W) | KNOWN/DERIVED | (5 − 3.29 V) × I |
| BMI270 | +3V3_LOGIC | 0.69 mA | 0.97 mA (performance mode) | KNOWN @1.8 V; ESTIMATED same @3.3 V | Bosch DS Table 1 |
| AT24CS32 | +3V3_LOGIC | ≤6 µA standby; 0.4 mA read | 3.0 mA max during write | KNOWN | Atmel-8869C DC table (specified at 5 V; lower at 3.3 V) |
| TCA9534 | +3V3_LOGIC | µA | ≤0.25 mA | ESTIMATED | confirm DS ICC table |
| TLV9062 | +3V3_LOGIC | 1.08 mA | ~1.2 mA | KNOWN | 538 µA/ch |
| Q1/Q2 base drive | +3V3_LOGIC (via op-amp) | 0 | 5 mA at full scale | DERIVED | 2 × 254 mA / hFE(min 100) |
| Status LED D2 | +3V3_LOGIC | 1.3 mA when on | 1.3 mA | ESTIMATED | (3.3 − ~2.0 V)/1 kΩ |
| Pull-ups held low (R14, R24, R26) | +3V3_LOGIC | 0 | 1 mA | DERIVED | 3 × 0.33 mA |
| TPS2553 quiescent | +5V_HEAD | 0.12 mA (on) | 0.14 mA | KNOWN | SLVS841F supply-current table |
| TLV758P ground current | +5V_HEAD | 25 µA | 35 µA | KNOWN | DS IGND |
| Illumination, 2 ch at design full scale | +5V_ILLUM | 0 (off) | 2 × 254 mA = 0.51 A | DESIGN LIMIT (not a requirement) | R16/R17 + 1 Ω |
| — of which LEDs | | | ≈1.5 W | ESTIMATED | Vf ≈ 3.0 V at 254 mA (LED not selected) |
| — of which Q1+Q2 | | | ≈0.9 W | DERIVED | (5 − 3.0 − 0.25 V) × 0.254 A × 2 |
| — of which sense resistors | | | 0.13 W | DERIVED | 0.254² × 1 Ω × 2 |
| Illumination hard cap | +5V_ILLUM | | 0.592–0.709 A | KNOWN/DERIVED | TPS2553 eq. 1 with R15 = 40.2 kΩ |
| Measurement shunts SH1/SH2/SH3 | | | 37 mW / 2 mW / µW | DERIVED | I²R |

### Head totals (DERIVED from the rows above)

| Operating state | +5V_HEAD | +3V3_LOGIC | Head power |
|---|---|---|---|
| Idle, ToF off, LEDs off | ~0.2 mA | ~2–4 mA | ~0.01 W |
| ToF ranging, LEDs off | 100 mA typ / 150 mA peak | ~3–4 mA | 0.51 W typ / 0.76 W peak |
| ToF ranging + LEDs at design full scale | ~0.61 A typ / 0.66 A peak | ~10 mA | ≈3.1 W typ |
| Absolute bound (limiter + ToF peak) | 0.86 A | ~10 mA | ≈4.3 W |

**Margin rule (ESTIMATED, to be replaced by measurement):** allocate 1.0 A at
5 V to the head on the host carrier; Rev A bench may run LEDs at reduced
set-point until H2 shows UNO Q + display + camera leave that headroom.

## 3. System-level placeholders (all UNKNOWN)

| Load | Rail | Status | How it gets measured |
|---|---|---|---|
| UNO Q (Linux idle / camera pipeline / Wi-Fi burst) | 5 V USB-C | UNKNOWN | inline USB-C meter, states below |
| UNO Media Carrier (incl. on-board level shifting) | via UNO Q | UNKNOWN | difference with/without carrier |
| Compact display + backlight — leading 3.5in (H): **180 mA at 3.3 V on UNO Q `PWR_3P3V` via the DSI FFC** (vendor; backlight fixed, always on) | UNO Q PWR_3P3V (no 5 V) | DOCUMENTED (vendor), UNMEASURED | 5 in dev panel as proxy now; re-measure on the (H) with kiosk + camera ([selection](../../docs/hardware/COMPACT_DISPLAY_SELECTION.md) §3) |
| IMX219 camera module (each of B0394/B0393/B0390; B0393 VCM) | Media Carrier camera rail | UNKNOWN | difference preview vs no camera; record per SKU |
| Perception head | 5 V + 3V3 | §2 (datasheet-based) | head shunts SH1/SH3 |
| Battery → 5 V conversion loss | — | UNKNOWN (topology not chosen); ESTIMATED 85–93 % efficiency for a buck from 2S/3S | measure once host carrier power stage exists |

## 4. What Matthew needs to measure (closes the system model)

Use the USBC-VAMETER3 (or equivalent) inline on the UNO Q USB-C input,
5 V/3 A PD source, record 30 s average + max for each state; log ambient temp.

1. **UNO Q alone:** boot peak, Linux idle, CPU-heavy (Scout analyzer run).
2. **+ Media Carrier:** idle.
3. **+ 5 in DSI display:** idle at fixed backlight, kiosk running.
4. **+ CSI camera (B0394 first):** live preview, still capture burst; repeat for B0393 (incl. autofocus sweep) and B0390.
5. **+ Pololu VL53L8CX on Qwiic/3.3 V bench wiring:** 4×4@10 Hz and 8×8@15 Hz continuous (also supplies T2 AVDD and P2).
6. **+ bench LED at fixed current** (e.g. 100/200/250 mA from a CC bench supply into one high-CRI LED): captures for L1/L2 — measure the LED current separately, not through the UNO Q.
7. **5 V presence on DC_IN power** (H1) and DC_IN input current for the same states once a 7–24 V supply is used.
8. **Brown-out check:** run state 4 + ToF + 0.5 A dummy load on 5 V header; note any reset/USB disconnect.

Results go in `docs/hardware/POWER_BATTERY_REFERENCE.md` (matrix) with raw
meter screenshots/logs under the evidence folder; then this file's §3 changes
from UNKNOWN to MEASURED with links.

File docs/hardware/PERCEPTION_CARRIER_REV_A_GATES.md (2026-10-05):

# Rev A perception carrier — entry gates

> **Electrical design work (2026-10-05):** the Perception Head Rev A schematic,
> research ledger, decision register, ICD, power tree and bring-up plan live in
> [`hardware/pcb/`](../../hardware/pcb/README.md). This file remains the gate
> definition; `hardware/pcb/README.md` tracks which gates are released.

Status: planning gate, 2026-09-30. This document prevents schematic/layout work from outrunning verified interfaces.

The custom carrier is the primary Platypus One path. Integrated commercial RGB-D modules are reference/fallback architectures, not the default.

## Mission

Create one mechanically rigid perception head that can eventually combine:
- RGB image capture
- multizone ToF depth
- IMU
- controlled white illumination
- calibration/provenance data

The carrier exists to make the sensing stack repeatable and serviceable. It must not become a second general-purpose compute board.

## Gate 0 — proven workflow

Before carrier layout, preserve the current working reference workflow:
`touch → RGB capture → Engineering Observation → display → saved evidence`.

A carrier revision may not remove that fallback path until its replacement has equivalent physical evidence.
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

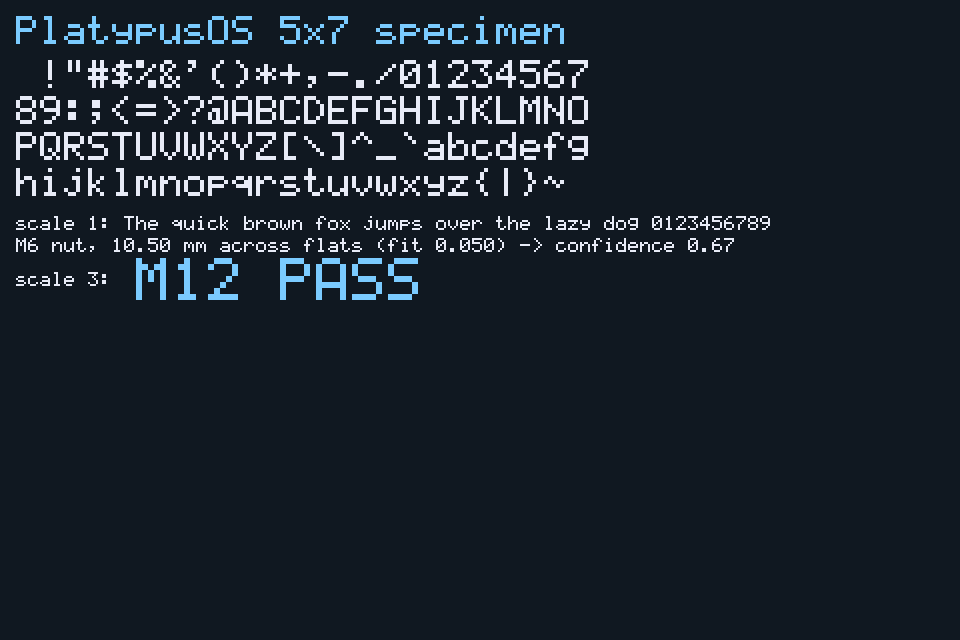
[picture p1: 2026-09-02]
docs/media/renders/font-specimen.png

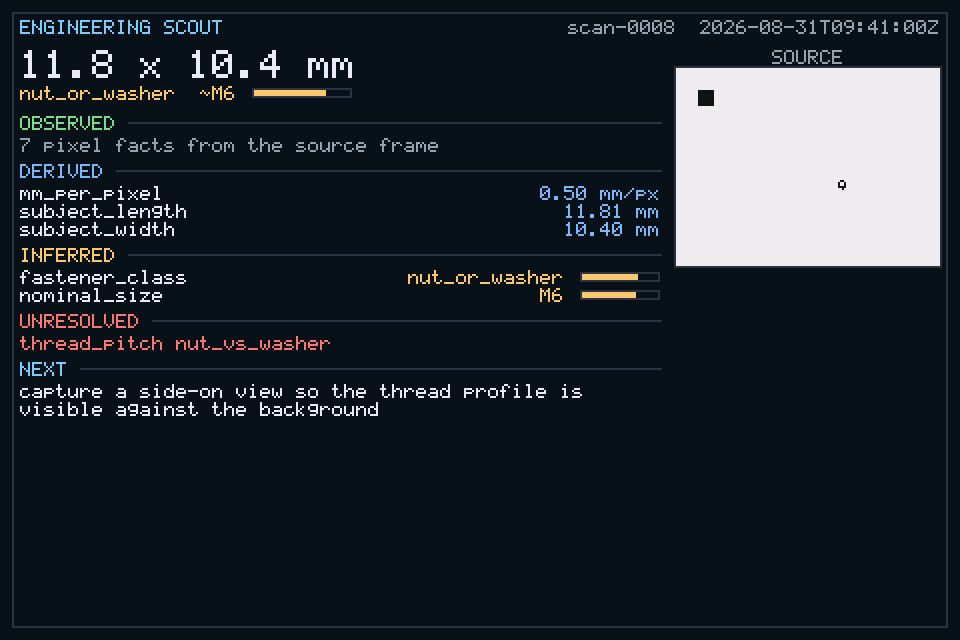
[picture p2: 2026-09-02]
docs/media/renders/scout-card-thumbnail.png

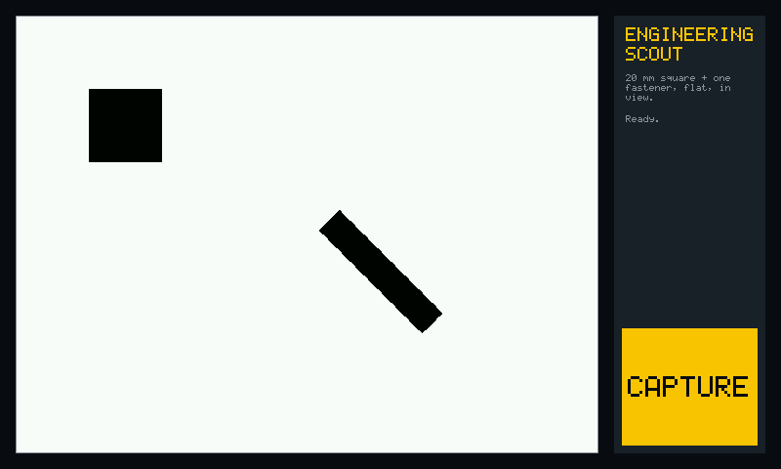
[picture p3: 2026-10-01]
docs/contest/media/scout-kiosk-preview.png

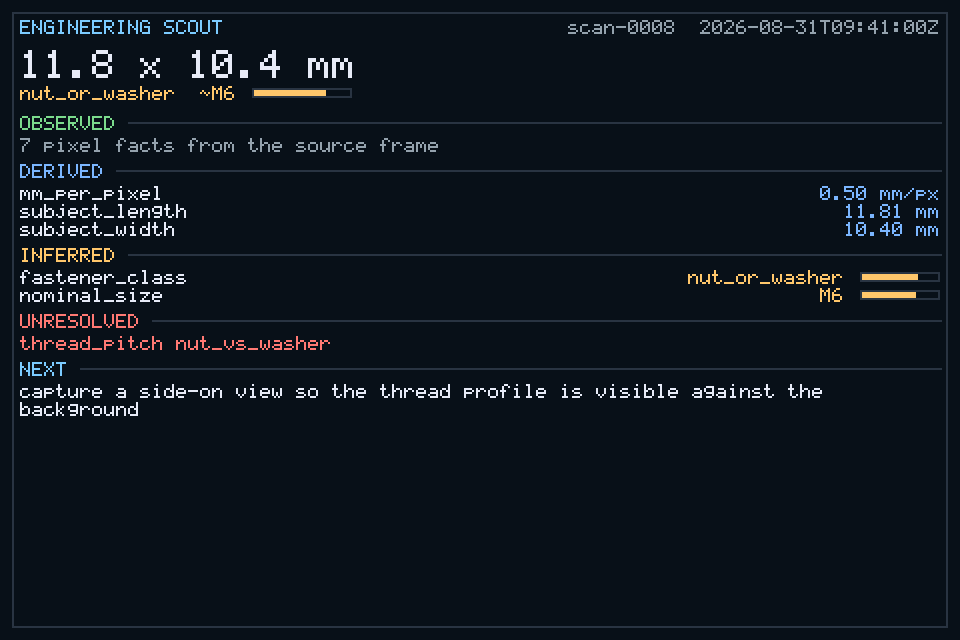
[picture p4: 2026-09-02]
docs/media/renders/scout-card-nut.png

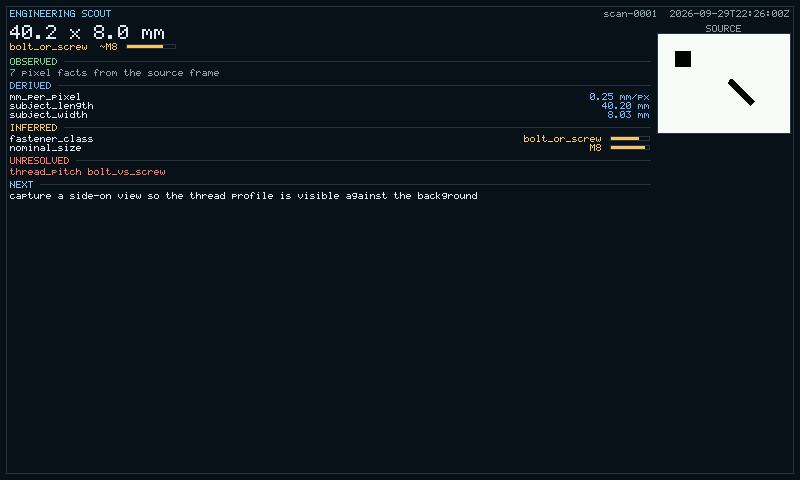
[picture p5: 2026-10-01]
docs/contest/media/scout-kiosk-card.png

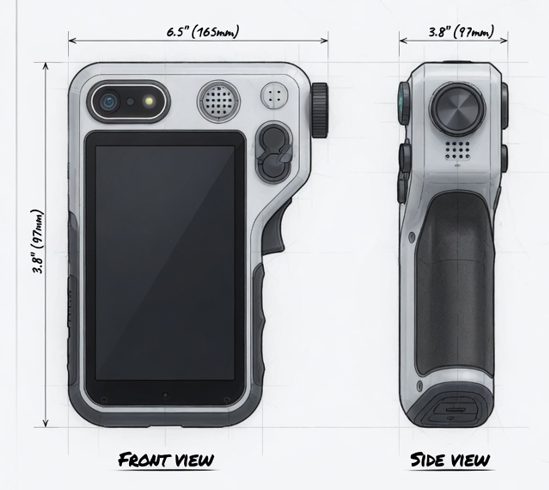
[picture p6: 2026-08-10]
docs/media/Prototype sketch 1.png

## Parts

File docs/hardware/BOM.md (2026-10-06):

# Platypus One — Bill of Materials (rev B, planning — merged)

Status date: **2026-09-30**. This is the **master planning and inventory superset**, not the frozen hardware-request BOM or the bounded Contest Core build (scope layers are governed in the private planning overlay). It merges the original planning BOM with the
envelope BOM from `industrial_design/bounding_boxes/BOM_v0_1.md` (which stays
as the packaging-envelope tracker). **Alternates are kept deliberately** —
selection analysis is pending; do not delete an option without a decision
note. Prices are indicative USD; refresh at order time.

Legend: ACQ = PLANNED → ORDERED → RECEIVED → TESTED. ✦ = primary candidate.

## Core compute

| # | Item | Qty | Est. | Envelope (mm) | Source | Notes | ACQ |
|---|---|---|---|---|---|---|---|
| 1 | **Arduino UNO Q (4G)** ✦ | 1 | $59 (or free) | 68.58×53.34 board outline; 3D clearance TBD from official STEP | Contest hw / store.arduino.cc | Required by contest. Hardware recipients announced Sep 18 | PLANNED |
| 2 | microSD 32 GB A1 | 1 | $12 | — | Amazon/DigiKey | OS + data partition | PLANNED |
| 3 | USB-C PD supply 5V/3A + cable | 1 | $15 | — | Amazon | Bench power | PLANNED |

> Received research/de-risk inventory (rows R1–R4) and its component dossiers
> are tracked in the private planning overlay, not in the public repository.
> Research intake never creates a Contest Core requirement.

## Display — **DECIDED: 4a (DSI)** per [ADR-0002](../adr/0002-dsi-production-display.md); analysis in [DISPLAY_COMPARISON.md](DISPLAY_COMPARISON.md)

| # | Option | Est. | Envelope (mm) | Notes | ACQ |
|---|---|---|---|---|---|
| 4a | **Waveshare 5-DSI-TOUCH-A + UNO Media Carrier** ◐ CONDITIONAL | Panel $34.95–36.99 + carrier €19.89 | Panel CAD TBD; carrier 68.58×53.34 | Only 4.3–5″ panel with a shipped UNO Q profile; 720×1280 native portrait. Carrier was Coming Soon / sold out on 2026-08-25. Proof plan: [DSI_PANEL_CANDIDATES.md](DSI_PANEL_CANDIDATES.md) | PLANNED |
| 4b | 4.3" parallel-RGB 800×480 cap. (SUB3-class, ST7262E43 + GT1151) + ESP32-S3 bridge | ~$35+bridge | ~121×76×7 | FALLBACK ONLY (activated if 4a sourcing fails by Sep 30) | HOLD |
| 4c | 3.2" ILI9341 320×240 SPI, resistive (XPT2046) | $16 | ~90×55×10 | DESCOPE NET only; matches current renderer/sim as built | HOLD |
| 4e | **Waveshare 3.5inch DSI LCD (H), SKU 33087** + Media Carrier + existing 15→22 cable | (check on order day) | 56×88.9×~10.7 (vendor drawing/STEP) | Compact-display LEADING candidate (#41). 480×800 portrait, GT911, 3V3 180 mA. Software prepared, **not yet bench-tested**: [COMPACT_DISPLAY_SELECTION.md](COMPACT_DISPLAY_SELECTION.md) | RECOMMENDED (1 bench unit) |
| 4d | USB-C/HDMI portable monitor or Waveshare 5" HDMI (H) | $40 | dev only | Prototyping fixture, never the product (consumes USB-C) | PLANNED |

## Input

| # | Item | Qty | Est. | Envelope (mm) | Source | Notes | ACQ |
|---|---|---|---|---|---|---|---|
| 5 | Rotary encoder, EC11-style w/ push | 1 | $3 | 24×24×30 | DigiKey | Primary nav control, at left thumb per ID doc | PLANNED |
| 6 | Tactile buttons 6×6 mm | 4 | $2 | — | DigiKey | Trigger + function keys | PLANNED |

## Sensing (alternates kept — analysis pending)

> Perception Head Rev A part selections with rationale (ToF carrier, IMU, illumination driver, ID EEPROM):
> [`hardware/pcb/BOM_PERCEPTION_HEAD_REV_A.md`](../../hardware/pcb/BOM_PERCEPTION_HEAD_REV_A.md).

| # | Item | Qty | Est. | Envelope (mm) | Source | Notes | ACQ |
|---|---|---|---|---|---|---|---|
| 7a | Camera: USB UVC OV5640-class autofocus ✦ | 1 | $25 | 25×25×10 | Amazon | Simplest Linux path (V4L2) | PLANNED |
| 7b | Camera: 13 MP autofocus module | 1 | $40 | 25×25×10 | TBD | Higher fidelity for ShadowScan; confirm UVC or MIPI-CSI availability on UNO Q before choosing | PLANNED |
| 8a | ToF: VL53L1X (single-zone, 4 m) | 1 | $12 | 13×18×2 (breakout) | Pololu/Adafruit | FALLBACK — proven, cheap single distance channel if multizone integration threatens schedule | HOLD |
| 8b | **ToF: VL53L8CX (8×8 multizone)** ✦ | 1 | $20 | 6×6×3 IC; breakout envelope TBD | ST/SparkFun | PREFERRED — 64-zone coarse depth, target/background separation, multiple-target handling, and camera-geometry cross-check; not a precision CAD scanner | PLANNED |
| 9a | **IMU: BMI270** ✦ | 1 | $8 | 2.5×3.0×0.8 IC; breakout TBD | DigiKey/Bosch | Rev A primary candidate: current device, I²C/SPI, 3.3 V-compatible VDD/VDDIO range; fusion runs on our side | PLANNED |
| 9b | BNO055 fused IMU | 1 | $25 | 20×27×4 (breakout) | Adafruit/Bosch | DEV/FALLBACK ONLY — Bosch marks BNO055 not recommended for new designs; do not anchor custom carrier to it | HOLD |
| 10 | Color: TCS34725 | 1 | $8 | 20×20×3 | Adafruit | Multi-measure lineage feature | PLANNED |
| 11 | Radar: Grove BGT24LTR11 Doppler | 1 | $30 | 40×20×12 | Seeed | **V2 candidate** (machine-health app per utilities roadmap) — envelope reserved, not in Rev A build | DEFERRED |
| 12 | White LED high-CRI + driver | 2 | $2 | — | DigiKey | Controlled shadow casting + illumination | PLANNED |

## Power

| # | Item | Qty | Est. | Envelope (mm) | Source | Notes | ACQ |
|---|---|---|---|---|---|---|---|
| 13 | Flat Li-ion/LiPo 3.7 V ~2500 mAh protected ✦ | 1 | $15 | 100×60×8 | Adafruit | Flat pack per packaging direction; exact cell TBD after display decision (display dominates power budget) | PLANNED |
| 14 | USB-C charge/boost board 5 V 3 A | 1 | $20 | ~30×20×6 | Adafruit/DigiKey | Stable 5 V under Linux load; port exits grip base | PLANNED |
| 15 | Power switch SPDT slide | 1 | $1 | — | DigiKey | | PLANNED |

## Audio & feedback

| # | Item | Qty | Est. | Source | Notes | ACQ |
|---|---|---|---|---|---|---|
| 16 | Piezo buzzer or 1 W speaker + PAM8302 | 1 | $6 | Adafruit | IAudioOutput | PLANNED |
| 17 | Vibration motor disc (optional) | 1 | $2 | Adafruit | Haptics stretch | PLANNED |

## Enclosure & interconnect (PCBWay scope — $300 credit if selected)

| # | Item | Qty | Est. | Source | Notes | ACQ |
|---|---|---|---|---|---|---|
| 18 | Carrier/breakout PCB (I²C hub, buttons, encoder, power) | 1 | ~$60 asm | **PCBWay** | Follow the [Rev-A methodology](CARRIER_BOARD_DEVELOPMENT_METHOD.md); observability/recoverability first; freeze gate Nov 10 | PLANNED |
| 19 | Enclosure: CNC alu barrel + printed polymer grip (hybrid per [INDUSTRIAL_DESIGN.md](INDUSTRIAL_DESIGN.md)) | 1 set | ~$120–250 | **PCBWay** | Metal barrel likely $150–250 alone — quote early; RF window required | PLANNED |
| 20 | JST-SH/Qwiic cables, headers, M2/M2.5 standoffs kit | — | $15 | Adafruit/Amazon | | PLANNED |
| 21 | Hookup wire, heat-shrink | — | $10 | Amazon | | PLANNED |

## Tools (if not owned)

| # | Item | Est. | ACQ |
|---|---|---|---|
| T1 | Soldering iron + solder + flux | $40 | PLANNED |
| T2 | Multimeter | $25 | PLANNED |
| T3 | USB-UART 3.3 V adapter | $10 | PLANNED |
| T4 | Digital calipers | $20 | PLANNED |

## Software (rubric: tools count)

| Item | Cost | Notes |
|---|---|---|
| Autodesk Fusion (+ Electronics) | Free personal / contest license | Enclosure + carrier PCB + schematics + contest measurement-to-parameter handoff |
| PlatypusOS (this repo) | — | C++20/CMake, own work |
| Arduino App Lab / UNO Q image | Free | Board OS |

## Totals (primary candidates only, excl. tools & contest-provided)

- With contest hardware + $300 PCBWay credit: **≈ $200–230 out of pocket**
- Fully self-funded worst case: **≈ $450–500 + tools**

## Pending decisions blocking ordering

1. **Display proof (4a)** — architecture is decided, but final selection awaits
   the UNO Media Carrier + 5-DSI-TOUCH-A bench test in
   [DSI_PANEL_CANDIDATES.md](DSI_PANEL_CANDIDATES.md). Blocks battery sizing
   and enclosure freeze; renderer geometry remains runtime-dynamic.
2. Camera 7a vs 7b — blocked on confirming UNO Q camera input paths.
3. **ToF architecture selected: 8b preferred.** VL53L8CX multizone depth now supports
   the contest capture-to-Fusion workflow; VL53L1X remains the schedule fallback.
   Final breakout, interface choice, optical window, calibration, and bench proof remain open.
4. **IMU direction updated:** BMI270 is the Rev A primary candidate. BNO055 is retained only as a development fallback because Bosch marks it not recommended for new designs. Bench/software validation of BMI270 remains required before schematic freeze.

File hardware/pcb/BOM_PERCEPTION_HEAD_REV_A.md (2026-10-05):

# Perception Head Rev A — candidate BOM with rationale

Machine-readable BOM (exported from the schematic, grouped, with DNP flags):
[`perception_head_rev_a/outputs/perception_head_rev_a_bom.csv`](perception_head_rev_a/outputs/perception_head_rev_a_bom.csv).
This page explains **why** each active/selected part is there and what the
fallback is. Lifecycle checked on manufacturer pages 2026-10-05. Stock: one JLCPCB parts-library snapshot (2026-10-05, table below). Redo at 2–3 distributors on order day. Status: SELECTED (use unless
evidence says otherwise) · CANDIDATE (reasonable, still comparing) ·
PROVISIONAL (placeholder until a gate closes).

## Active parts and modules

| Ref | Part (MPN) | Package | Status | Why this part | Verified against | Alternate |
|---|---|---|---|---|---|---|
| M1 | Pololu **#3419** VL53L8CX carrier | 12.7 × 22.9 mm, 0.1" headers | SELECTED (Rev A) | Same hardware as Platypus Lab evidence; solves 3-rail supply + 1.8 V I/O; swappable | Pololu drawing + schematic; custom footprint from drawing | Pololu VL53L7CX carrier (pin-compatible, 90° FoV); bare VL53L8CX = Rev B |
| U1 | TI **TLV75801PDBVR** | SOT-23-5 | SELECTED | Adjustable (sets 3.29 V; 3.43 V fallback), 1 % ref, active discharge for clean ToF reset, EN, 500 mA / 350 mA ISC, ACTIVE | DS pinout = KiCad `TLV75801PDBV` symbol | TLV75533P (fixed 3.3 V, less AVDD headroom) |
| U2 | Bosch **BMI270** | LGA-14 2.5 × 3.0 | SELECTED | Current Bosch IMU, 3.3 V-compatible VDD/VDDIO, I2C, 2 INTs, low current; BNO055 is NRND | Pinout Table 22 (= BMI160 symbol); Bosch land pattern → custom footprint | BMI323 (newer, different pinout/package — would need new footprint) |
| U3 | TI **TPS2553DBVR** | SOT-23-6 | SELECTED | Current-limited, soft-start, reverse-blocking 5 V switch with FAULT: protects host 5 V from LED faults; EN default off | SLVS841F pin table → custom symbol | TPS22918 (no current limit) + polyfuse |
| U4 | TI **TLV9062IDR** | SOIC-8 | SELECTED | RRIO dual, 3.3 V supply, 10 MHz, low offset → accurate low-voltage current sense loop; hand-reworkable package | DS; stock `TLV9062xD` symbol | TLV9002 (lower GBW), MCP6002 |
| U5 | Microchip **AT24CS32-STUM-T** | SOT-23-5 | SELECTED | 4 KB + factory 128-bit unique serial + WP pin: identity and compact calibration in one part | Family DS (AT24CS04/08) pinout = stock symbol; AT24CS32 DS to confirm serial read (C4) | 24AA025E48 (EUI-48, 256 B) |
| U6 | TI **TCA9534PWR** | TSSOP-16 | SELECTED | 8 I/O over bus A, no internal pull-ups (defaults defined by our resistors), INT, 5 V-tolerant | DS pin table = stock symbol | PCA9534 (NXP), PCAL6408A |
| Q1, Q2 | Nexperia **BCP56-16** | SOT-223 | CANDIDATE | 80 V/1 A NPN pass element; BJT linear-mode SOA; cheap, common | Stock symbol (B1 C2 E3 C-tab) | BCX56 (SOT-89, less dissipation); logic MOSFET in DPAK if dissipation grows |
| D1 | **SMF5V0A-E3-08** (Vishay) | SMF (SOD-123F) | CANDIDATE | 5 V unidirectional TVS on cable 5 V input | Footprint stock `D_SMF` | SMBJ5.0A (bigger) |
| D2 | Green LED 0603 | 0603 | GENERIC | Firmware heartbeat/status | — | any |

## Stock snapshot (JLCPCB parts library, 2026-10-05)

| MPN | Stock | LCSC code | Note |
|---|---|---|---|
| TLV75801PDBVR | 164,219 | C2877852 | — |
| TPS2553DBVR | 57,938 | C55266 | — |
| TCA9534PWR | 15,089 | C783615 | — |
| TLV9062IDR | 170,048 | C398355 | — |
| BMI270 | 8,032 | C2836813 | — |
| BCP56-16,115 | 32,184 | C92221 | — |
| SMF5V0A-E3-08 | 12,353 | C1972946 | (SMF6V0A-E3-08: 34,287, if 5.5 V VBUS leakage matters) |
| **AT24CS32-STUM-T** | **52** | C147891 | **thin**: SOIC 28, UDFN 261; alternate 24AA025E48T-I/OT 6,428 (C129895). See register C5 |
| SM14B-GHS-TB(LF)(SN) | 3,288 | C265343 | genuine JST |
| SM04B-SRSS-TB(LF)(SN) | thin (genuine) | — | compatible clones plentiful, e.g. HC-1.0-4PWT 108,747 |
| SM02B-GHS-TB(LF)(SN) | 2 (genuine) | C189893 | compatible clones plentiful, e.g. A1257WR-S-2P 63,705 |
| Pololu #3419 | not checked | — | buy from Pololu directly |

## Connectors / mechanical

| Ref | Part | Status | Why | Alternate |
|---|---|---|---|---|
| J1 | JST **SM14B-GHS-TB(LF)(SN)** (mates GHR-14V-S) | PROVISIONAL | Locking, 1 A/contact, 14 signals in one cable, cheap ready-made leads | Molex Pico-Lock, 0.5 mm FFC — after Fusion routing (H8) |
| J2 | JST **SM04B-SRSS-TB(LF)(SN)** | SELECTED | Qwiic bench port for bus A | — |
| J3, J4 | JST **SM02B-GHS-TB(LF)(SN)** | PROVISIONAL | Locking 2-wire LED light-board links | Pads + soldered leads |
| JP1 | Solder jumper (open) | SELECTED | Hard illumination kill | — |
| H1–H3 | M2 holes (datum/slot/clamp) | PROVISIONAL | Locate-then-clamp head to datum bracket | Dowel pins (C3 result) |
| H4–H7 | M2 holes (camera standoffs) | PROVISIONAL | Head carries the camera module | Pattern from measured module (M2) |
| FID1–2 | Fiducials | SELECTED | Cheap insurance for machine assembly | — |

## Passives with design meaning (generic parts otherwise)

| Ref | Value | Function | Basis |
|---|---|---|---|
| R5 / R6 | 49.9 k / 10 k (**0.5 %**) | ToF rail 3.29 V (52.3 k → 3.43 V conditional fallback, ICD §5a) | 0.55 × (1 + R5/R6) |
| R7 / R13 | 100 k | ToF rail and LED switch OFF at power-up | EN pull-downs |
| R15 | 40.2 k (1 %) | U3 limit ≈0.65 A nom | TPS2553 eq. 1 |
| R16 / R17 / C13 | 120 k / 10 k / 220 n | ILLUM_SET → 0–0.254 V, PWM filter, OFF when floating | divider ratio 1/13 |
| R22 / R23 | 1 Ω 1 % 1206 (≥0.25 W) | LED current sense: 1 mV = 1 mA | — |
| SH1 / SH2 / SH3 | 0.05 Ω 1206 / 0.1 Ω 0805 / 1 Ω 0603 | Head 5 V / ToF / logic current measurement | Kelvin TPs |
| R9, R11 | 0 Ω | I2C mode strap (ToF), IMU address 0x68 | — |
| R24 | 10 k | EEPROM write-protected by default | — |
| R27 | 1 k | expander → ILLUM_EN series, lets JP1 override safely | — |
| R28–R30 | 100 k | defined levels for expander P2, IMU INT2/INT1 before firmware config | — |

DNP options (fitted footprints, unpopulated): R1–R4 bus pull-ups, R8 ToF
force-on, R10 expander-controlled ToF I2C reset, R12 IMU 0x69, C15/C16 loop
compensation, C18/C19 bus-B damping.

## Not on this board (listed so they are not forgotten)

| Item | Status | Note |
|---|---|---|
| IMX219 camera module (B0394 / B0393 / B0390) | BLOCKED on #40 | Mounted to H4–H7; FFC to Media Carrier CSI |
| White LEDs (light boards) | OPEN (L6) | High-CRI (≥90) mid-power 3030/3535 class; choose after L2/L3 |
| Light-board PCB / diffuser / baffle | OPEN | Tiny separate board; geometry from Fusion + glare tests |
| Harness J1 → UNO Q (Qwiic + 0.1" pins) | Rev A bench | GHR-14V-S pre-crimped leads |

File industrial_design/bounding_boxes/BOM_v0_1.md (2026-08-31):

# Platypus One BOM v0.1 — packaging envelopes

> Canonical parts BOM (with alternates + acquisition tracking):
> [docs/hardware/BOM.md](../../docs/hardware/BOM.md). This file tracks
> **packaging envelopes only** until vendor STEP models replace them.

| Component | Candidate | Envelope (mm) |
| --- | --- | --- |
| Compute | Arduino UNO Q | 68.58 x 53.34 board outline (official mech. drawing); 3D clearance TBD from STEP |
| Display | 5-7 in LCD | 165 x 100 x 8 |
| Camera | 13 MP autofocus | 25 x 25 x 10 |
| ToF | VL53L8CX | 6 x 6 x 3 |
| Radar | Grove BGT24LTR11 | 40 x 20 x 12 |
| IMU | BMI270 | 10 x 10 x 3 |
| Rotary Encoder | EC11-style | 24 x 24 x 30 |
| Battery | Flat Li-ion | 100 x 60 x 8 |

Next action: replace every envelope with an exact vendor STEP model.

> **UNO Q note:** production CAD must use Arduino's official STEP model /
> mechanical drawing (board outline 68.58 × 53.34 mm), not an approximate
> envelope. Board outline (2D) and required 3D clearance are separate
> concepts — never derive a component height from the outline.

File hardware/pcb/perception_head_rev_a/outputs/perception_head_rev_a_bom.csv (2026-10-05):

Refs | Value | Footprint | Manufacturer | MPN | Status | Qty | DNP | Spec | Note
C1,C3,C5,C9,C10,C14,C17 | 100n | Capacitor_SMD:C_0603_1608Metric |  |  |  | 7 |  | X7R/X5R, >=10 V | VDD decoupling,VDDIO decoupling
C2,C12 | 10u | Capacitor_SMD:C_0805_2012Metric |  |  |  | 2 |  | X5R 10 V
C4,C8 | 4.7u | Capacitor_SMD:C_0805_2012Metric |  |  |  | 2 |  | X5R 10 V | Local bulk at carrier VIN
C6,C11 | 1u | Capacitor_SMD:C_0603_1608Metric |  |  |  | 2 |  | X7R/X5R, >=10 V
C7 | 2.2u | Capacitor_SMD:C_0805_2012Metric |  |  |  | 1 |  | X5R 10 V (>=1 uF effective)
C13 | 220n | Capacitor_SMD:C_0603_1608Metric |  |  |  | 1 |  | X7R/X5R, >=10 V | PWM filter
C15,C16 | 1n | Capacitor_SMD:C_0603_1608Metric |  |  |  | 2 | DNP | X7R/X5R, >=10 V | DNP_OPTION compensation
C18,C19 | 22p | Capacitor_SMD:C_0603_1608Metric |  |  |  | 2 | DNP | C0G 50 V | DNP_OPTION: Pololu suggests tens of pF if its shifter oscillates on long leads,DNP_OPTION: as C18; BENCH_VERIFY with the real host cable length
D1 | SMF5V0A | Diode_SMD:D_SMF | Vishay/Littelfuse | SMF5V0A-E3-08 | CANDIDATE | 1 |  |  | Unidirectional 5 V TVS on host 5 V input (Zener symbol used for K/A polarity)
D2 | GREEN | LED_SMD:LED_0603_1608Metric |  |  | GENERIC | 1 |  |  | Firmware status LED via expander P7 (active high)
FID1,FID2 | Fiducial | Fiducial:Fiducial_1mm_Mask2mm |  |  |  | 2
H1 | DATUM_PRIMARY | MountingHole:MountingHole_2.2mm_M2 |  |  |  | 1 |  |  | Primary locating hole (pin/shoulder screw). Position from Fusion.
H2 | DATUM_SLOT | MountingHole:MountingHole_2.2mm_M2 |  |  |  | 1 |  |  | Becomes a slot at layout (anti-rotation). Position from Fusion.
H3 | CLAMP | MountingHole:MountingHole_2.2mm_M2 |  |  |  | 1 |  |  | Clamp-only screw; does not locate.
H4,H5,H6,H7 | CAM_MNT | MountingHole:MountingHole_2.2mm_M2 |  |  |  | 4 |  |  | Camera module standoff (PROVISIONAL),Camera module standoff. PROVISIONAL Pi-camera 21 x 12.5 mm pattern; MEASURE selected Arducam board (T5).
J1 | HOST_14P_TBD | Connector_JST:JST_GH_SM14B-GHS-TB_1x14-1MP_P1.25mm_Horizontal | JST | SM14B-GHS-TB(LF)(SN) | PROVISIONAL | 1 |  |  | Connector family/pin order not frozen; mates GHR-14V-S
J2 | QWIIC_BUS_A | Connector_JST:JST_SH_SM04B-SRSS-TB_1x04-1MP_P1.00mm_Horizontal | JST | SM04B-SRSS-TB(LF)(SN) | SELECTED | 1 |  |  | Qwiic pinout 1 GND 2 3V3 3 SDA 4 SCL (matches UNO Q QWIIC1)
J3 | LIGHT_BOARD_1 | Connector_JST:JST_GH_SM02B-GHS-TB_1x02-1MP_P1.25mm_Horizontal | JST | SM02B-GHS-TB(LF)(SN) | PROVISIONAL | 1 |  |  | Pin1 LED anode (+5V_ILLUM), pin2 LED cathode (sink)
J4 | LIGHT_BOARD_2 | Connector_JST:JST_GH_SM02B-GHS-TB_1x02-1MP_P1.25mm_Horizontal | JST | SM02B-GHS-TB(LF)(SN) | PROVISIONAL | 1
JP1 | ILLUM_KILL | Jumper:SolderJumper-2_P1.3mm_Open_RoundedPad1.0x1.5mm |  |  | OPEN by default | 1 |  |  | Close to permanently disable illumination
M1 | Pololu #3419 | PlatypusOne:Pololu_3419_VL53L8CX_Carrier_THT | Pololu | 3419 | SELECTED (Rev A) | 1 |  |  | Contains VL53L8CX; 100 mA typ / 150 mA peak per Pololu
Q1,Q2 | BCP56-16 | Package_TO_SOT_SMD:SOT-223-3_TabPin2 | Nexperia | BCP56-16,115 | CANDIDATE | 2 |  |  | Linear pass element; BJT chosen for linear-mode SOA over small trench MOSFETs
R1,R2,R3,R4 | 4.7k | Resistor_SMD:R_0603_1608Metric |  |  |  | 4 | DNP | 1% 0.1W | DNP_OPTION Pololu shifter has 10k,DNP_OPTION host has 2.2k
R5 | 49.9k | Resistor_SMD:R_0603_1608Metric |  |  |  | 1 |  | 0.5% 0.1W (sets ToF rail band) | Vout 3.29 V (52.3k = 3.43 V fallback, see ICD 5a)
R6,R14,R17,R24,R26 | 10k | Resistor_SMD:R_0603_1608Metric |  |  |  | 5 |  | 0.5% 0.1W (sets ToF rail band),1% 0.1W | FAULT open-drain pull-up,Set divider bottom; defines OFF when host floats,TCA9534 INT is open-drain,Vout set (bottom),Write-protect by default
R7,R13,R28,R29,R30 | 100k | Resistor_SMD:R_0603_1608Metric |  |  |  | 5 |  | 1% 0.1W | Defined level until INT1 enabled,Defined level until INT2 enabled,Defines expander P2 when R10 is DNP,Illumination OFF at power-up,ToF rail OFF at power-up
R8 | 10k | Resistor_SMD:R_0603_1608Metric |  |  |  | 1 | DNP | 1% 0.1W | DNP_OPTION TOF_FORCE_ON (bench)
R9,R11 | 0 | Resistor_SMD:R_0603_1608Metric |  |  |  | 2 |  | 0 ohm jumper | I2C address 0x68 (populated),I2C mode strap (populated)
R10,R12 | 0 | Resistor_SMD:R_0603_1608Metric |  |  |  | 2 | DNP | 0 ohm jumper | DNP_OPTION address 0x69,DNP_OPTION: expander controls SPI/I2C pin (remove R9 first)
R15 | 40.2k | Resistor_SMD:R_0603_1608Metric |  |  |  | 1 |  | 1% 0.1W | Current limit ~650 mA nom (BENCH_VERIFY vs host 5 V)
R16 | 120k | Resistor_SMD:R_0603_1608Metric |  |  |  | 1 |  | 1% 0.1W | Set divider top
R18,R19 | 470 | Resistor_SMD:R_0603_1608Metric |  |  |  | 2 |  | 1% 0.1W | Base drive
R20,R21,R25,R27 | 1k | Resistor_SMD:R_0603_1608Metric |  |  |  | 4 |  | 1% 0.1W | Feedback,Series so JP1 can override the expander without a short,~1 mA status LED
R22,R23 | 1 | Resistor_SMD:R_1206_3216Metric |  |  |  | 2 |  | 1% 0.25W+ sense | I_LED1 = V(TP27) / 1 ohm,I_LED2 = V(TP28) / 1 ohm
SH1 | 0.05 | Resistor_SMD:R_1206_3216Metric |  |  |  | 1 |  | 1% 0.5W current shunt | Head 5 V current measurement; Kelvin TPs TP1/TP2
SH2 | 0.1 | Resistor_SMD:R_0805_2012Metric |  |  |  | 1 |  | 1% 0.25W current shunt | ToF current measurement; Kelvin TPs TP6/TP7
SH3 | 1 | Resistor_SMD:R_0603_1608Metric |  |  |  | 1 |  | 1% 0.1W current shunt | Logic 3V3 current measurement; Kelvin TPs TP4/TP5
TP1 | +5V_HOST | TestPoint:TestPoint_Pad_D1.5mm |  |  |  | 1
TP2 | +5V_HEAD | TestPoint:TestPoint_Pad_D1.5mm |  |  |  | 1
TP3 | +5V_ILLUM | TestPoint:TestPoint_Pad_D1.5mm |  |  |  | 1
TP4 | +3V3_HOST | TestPoint:TestPoint_Pad_D1.5mm |  |  |  | 1
TP5 | +3V3_LOGIC | TestPoint:TestPoint_Pad_D1.5mm |  |  |  | 1
TP6 | TOF_LDO_OUT | TestPoint:TestPoint_Pad_D1.5mm |  |  |  | 1
TP7 | +3V3_TOF | TestPoint:TestPoint_Pad_D1.5mm |  |  |  | 1
TP8 | TOF_AVDD | TestPoint:TestPoint_Pad_D1.5mm |  |  |  | 1
TP9 | TOF_CORE_1V8 | TestPoint:TestPoint_Pad_D1.5mm |  |  |  | 1
TP10,TP11,TP12 | GND | TestPoint:TestPoint_Keystone_5019_Miniature |  |  |  | 3
TP13 | I2C_A_SCL | TestPoint:TestPoint_Pad_D1.5mm |  |  |  | 1
TP14 | I2C_A_SDA | TestPoint:TestPoint_Pad_D1.5mm |  |  |  | 1
TP15 | I2C_B_SCL | TestPoint:TestPoint_Pad_D1.5mm |  |  |  | 1
TP16 | I2C_B_SDA | TestPoint:TestPoint_Pad_D1.5mm |  |  |  | 1
TP17 | TOF_INT_N | TestPoint:TestPoint_Pad_D1.5mm |  |  |  | 1
TP18 | TOF_SYNC | TestPoint:TestPoint_Pad_D1.5mm |  |  |  | 1
TP19 | TOF_LPN | TestPoint:TestPoint_Pad_D1.5mm |  |  |  | 1
TP20 | TOF_PWR_EN | TestPoint:TestPoint_Pad_D1.5mm |  |  |  | 1
TP21 | IMU_INT1 | TestPoint:TestPoint_Pad_D1.5mm |  |  |  | 1
TP22 | IMU_INT2 | TestPoint:TestPoint_Pad_D1.5mm |  |  |  | 1
TP23 | ILLUM_SET | TestPoint:TestPoint_Pad_D1.5mm |  |  |  | 1
TP24 | ILLUM_VSET | TestPoint:TestPoint_Pad_D1.5mm |  |  |  | 1
TP25 | ILLUM_EN | TestPoint:TestPoint_Pad_D1.5mm |  |  |  | 1
TP26 | ILLUM_FAULT_N | TestPoint:TestPoint_Pad_D1.5mm |  |  |  | 1
TP27 | ILED1_SENSE | TestPoint:TestPoint_Pad_D1.5mm |  |  |  | 1
TP28 | ILED2_SENSE | TestPoint:TestPoint_Pad_D1.5mm |  |  |  | 1
TP29 | EXP_INT_N | TestPoint:TestPoint_Pad_D1.5mm |  |  |  | 1
TP30 | TOF_I2C_RST_OPT | TestPoint:TestPoint_Pad_D1.5mm |  |  |  | 1
TP31 | EEPROM_WP | TestPoint:TestPoint_Pad_D1.5mm |  |  |  | 1
U1 | TLV75801PDBVR | Package_TO_SOT_SMD:SOT-23-5 | Texas Instruments | TLV75801PDBVR | SELECTED | 1 |  |  | 500 mA adj LDO, 1% Vref, active discharge, ISC 350 mA; Pololu peak ~150 mA
U2 | BMI270 | PlatypusOne:Bosch_LGA-14_3x2.5mm_P0.5mm_BoschLand | Bosch Sensortec | BMI270 | SELECTED | 1 |  |  | Active part (BNO055 is NRND). I2C 0x68.
U3 | TPS2553DBVR | Package_TO_SOT_SMD:SOT-23-6 | Texas Instruments | TPS2553DBVR | SELECTED | 1 |  |  | Current-limited 5 V switch for LED rail; FAULT -> expander P5
U4 | TLV9062IDR | Package_SO:SOIC-8_3.9x4.9mm_P1.27mm | Texas Instruments | TLV9062IDR | SELECTED | 1 |  |  | RRIO dual op-amp, 1.8-5.5 V; supplied from +3V3_LOGIC
U5 | AT24CS32-STUM-T | Package_TO_SOT_SMD:SOT-23-5 | Microchip | AT24CS32-STUM-T | SELECTED | 1 |  |  | 32 Kbit + 128-bit serial (0x58, dummy write 0x0800, read 16 B); fixed 0x50; JLC stock thin 2026-10-05, alt 24AA025E48T
U6 | TCA9534PWR | Package_SO:TSSOP-16_4.4x5mm_P0.65mm | Texas Instruments | TCA9534PWR | SELECTED | 1 |  |  | 0x20. P0 TOF_PWR_EN out, P1 TOF_LPN (input unless addr change), P2 spare/TOF I2C reset opt, P3 ILLUM_EN_REQ out (via R27), P4 EEPROM_WP out, P5 ILLUM_FAULT_N in, P6 IMU_INT2 in, P7 STATUS_LED out

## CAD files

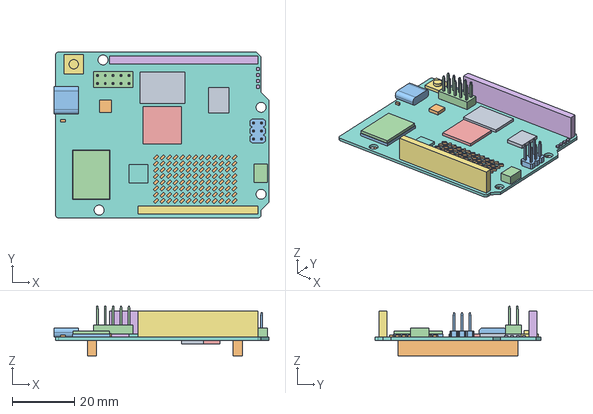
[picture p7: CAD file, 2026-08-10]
CAD/arduino_q.step
69.1 x 53.3 x 16.0 mm
Document x 128

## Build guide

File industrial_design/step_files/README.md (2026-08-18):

# STEP Files

Mechanical models used to package Platypus One.

## Current assets

- `CAD/arduino_q.step` — Arduino UNO Q model already present in the repository. Arduino publishes official STEP files for the UNO Q.

## Initial component selections / sources

- Arduino UNO Q — core compute board (required by contest).
- 5-inch display envelope — current packaging target; final display part number still under evaluation.
- Grove Doppler Radar (BGT24LTR11) — advanced motion/vibration sensing candidate.
- Flat Li-ion battery — preferred packaging direction; exact cell not yet selected.
- Rotary encoder — primary physical navigation control; exact part not yet selected.

## Source links

- Arduino UNO Q hardware page: https://docs.arduino.cc/hardware/uno-q
- Arduino UNO Q official STEP archive: https://github.com/arduino/docs-content/blob/main/content/hardware/02.uno/boards/uno-q/downloads/ABX00162-step.zip
- Seeed Grove Doppler Radar wiki: https://wiki.seeedstudio.com/Grove-Doppler-Radar/
- Waveshare 5inch HDMI LCD (H) V4 reference: https://www.waveshare.com/wiki/5inch_HDMI_LCD_%28H%29_V4

> Do not treat provisional envelope models as production CAD. Replace them with vendor STEP files once exact part numbers are frozen.

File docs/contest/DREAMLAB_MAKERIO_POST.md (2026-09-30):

# Dream Lab entry — maker.io post draft, form answer, and shot list

Working draft for the **Arduino UNO Q Dream Lab Challenge** entry. Written
2026-09-30 against the official rules and the state of the bench that day.

## The rules that shape this post

From DigiKey's challenge page and official rules (read 2026-09-30):

| | |
|---|---|
| Deadline | **11:59 p.m. CT, September 30, 2026** |
| How to enter | (1) build with the UNO Q, (2) publish a **maker.io project post** with **#UNOQDreamLab**, (3) submit the official form with the post link |
| Form asks | name, email, phone, project link, and *"If you won the Dream Lab, what would you do with it?"* |
| Eligibility | US resident, 18+, registered **MyDigiKey** account, one entry per person |
| Judging | five criteria at **20% each**: creativity/originality, technical execution, effective use of the UNO Q, **quality of documentation**, potential impact/innovation. Tie-break: creativity, then execution |
| Rights | "All entries … become the property of DigiKey"; broad licence to reproduce, modify and publicise; entrant warrants the entry is original and non-infringing |

What that means for the post:

- **Documentation is a full fifth of the score.** Show the loop working on
  the real board, with real photos, real numbers and the failures.
- **"Effective use of the UNO Q"** rewards showing *both* halves of the board
  (Linux MPU and STM32 MCU). Say clearly what each half does today.
- **Keep the post scoped to Engineering Scout.** PlatypusOne Core's industrial
  design and Rev A hardware are the Autodesk AU 2027 entry. Leave them out of
  this post rather than handing them to a second sponsor under a "property of"
  clause. The code is already public under Apache-2.0, so linking the repo
  gives nothing new away.
- **Credit third-party work** (originality warranty): the panel overlay and
  drivers from `dcuartielles/uno_q_dsi_displays`, Arduino's Zephyr core and
  LED-matrix library, and AI coding assistance.

---

## Post draft

> Placeholders are `[PHOTO: …]` and `[VIDEO]`. Numbers marked **(update)**
> should be replaced with today's bench data if a validation run happens
> before posting. Step 5 (sessions) is verified on the host only: confirm it on
> the board, or cut it to one line under "What's next", before posting.

### Engineering Scout: a UNO Q instrument that measures a part and says what it doesn't know

**#UNOQDreamLab**

Put an unknown screw on a card beside a printed 20 mm square and tap
CAPTURE. Engineering Scout measures it, names what it probably is, and saves
an engineering record. The record separates what the camera **observed**, what
was **derived** from that, what is only **inferred**, and what is still
**unresolved**, and it names the next view that would answer the unresolved
part. If the scene can't be measured honestly, Scout refuses and tells you
what to change instead of guessing.

[PHOTO: the whole bench — UNO Q on the Media Carrier, 5" panel showing a result card, webcam over the calibration card]

[VIDEO: under one minute — part down, tap, card, second capture in worse light, refusal + guidance, finish]

#### 1. Why

Every workbench has a jar of unidentified fasteners. Identifying one means
calipers, a thread gauge and a chart. Worse, most "AI measurement" demos report
a confident number whether or not the photo supports it. I wanted the
opposite: an instrument that is useful in ordinary, imperfect light and honest
about its uncertainty. It should be the first function of a real engineering
tool, not an object-detection demo.

#### 2. Hardware

| Part | Role |
|---|---|
| Arduino UNO Q | Qualcomm QRB2210 Linux side runs camera, vision, inference, UI and storage; STM32U585 MCU side runs Zephyr |
| Arduino UNO Media Carrier (ASX00083) | 22-pin MIPI-DSI "DISPLAY" connector for the panel |
| Waveshare 5inch DSI LCD, 800×480, capacitive touch (Rev2.2) | the instrument's screen and CAPTURE / FINISH buttons |
| Waveshare MIPI-DSI-Cable-12cm (15→22 pin) | panel ↔ carrier |
| USB webcam (640×480 YUYV) + USB-C hub | the camera, on the UNO Q's USB-C port |
| Printed calibration card with a 20 mm reference square | in-frame scale anchor |

[PHOTO: cable orientation, both ends — docs/media/hardware/dsi-cable-carrier-end.jpg and dsi-cable-panel-end.jpg]

#### 3. How it works (from the operator's side)

1. The panel shows a live camera preview and a guidance panel.
2. Tap **CAPTURE**. The UNO Q grabs a frame, finds the 20 mm square
   (the scale) and the part, measures the part, and classifies it.
3. The **evidence card** shows the headline measurement (e.g. `40.2 × 8.0 mm`,
   `bolt_or_screw ~M8`) and four colour-coded sections: OBSERVED (pixel
   facts), DERIVED (mm/px, length, width), INFERRED (class and nominal size with
   confidence bars), UNRESOLVED (thread pitch, bolt vs screw), plus NEXT (the
   view that would resolve them).
4. **Refusal is a feature.** No square in view, a part that runs off the frame
   edge, or a speck too small to be a part gives a plain instruction ("No part
   found beside the square. Keep it fully in frame.") and no number. The
   attempt is still saved as evidence.
5. **Sessions.** Captures of one object are grouped. Scout asks for more
   ("shift or rotate the part") until three captures agree within 0.5 mm,
   then FINISH writes a CAD handoff bundle: the silhouette as **DXF (mm)** for
   Fusion 360 / KiCad, as JSON for a mesh-to-CAD tool, the source image and a
   summary.

[PHOTO: evidence card on the panel for a real screw]
[PHOTO: session summary screen with the exported outline]

#### 4. Software architecture

Written in C++20, with no OpenCV and no cloud:

- **Camera:** V4L2, YUYV at 640×480.
- **Display:** KMS/DRM directly — a dumb framebuffer on the DSI panel, touch
  and buttons from evdev. A `platypus-mode` switch toggles between the kiosk
  and the stock desktop, because only one of them can own the screen.
- **Vision:** illumination flattening (a robust surface fit that removes
  lighting gradients), Otsu thresholding, connected components, reference
  square detection, rejection of blobs clipped by the frame edge and of
  specks under 10 mm², and a marching-squares outline tracer.
- **Inference:** a fastener classifier over the measured geometry with
  nominal-size matching (M-series), reporting confidence rather than a bare
  label.
- **Evidence contract:** every capture is an append-only
  *Engineering Observation* JSON record with provenance on every claim, saved
  next to its source image. Inference can never masquerade as measurement.
- **Tested off the board:** the same code builds on Windows (MSVC) and Linux
  (GCC) in CI; a synthetic ground-truth battery and a renderer let the whole UI
  be reviewed without hardware.

**UNO Q split today:** the Linux side does perception, inference, UI and
storage. The STM32 runs the status LED matrix (an animated platypus). A
Linux↔MCU bridge protocol is written and host-tested but not yet on the board.
Next, the MCU takes over the deterministic work: capture trigger, controlled
illumination, and a turntable for multi-view capture.

#### 5. Results — honest numbers

**Synthetic ground-truth battery (21 cases):** 21/21 behave as specified;
classification 17/17, nominal size 15/15; length error 0.30 mm mean / 0.49 mm
max; width 0.27 / 0.50 mm; all 4 intentional failure cases refuse for the
right reason.

**First light on real hardware (29 Sep, late night, poor lighting):** the
pipeline ran end to end on the UNO Q with the real webcam. The reference
square was found correctly. An M6 screw (calipers: 44.45 mm long, 9.48 mm
head) measured **49.6 × 12.1 mm** — a large over-read, most likely from the
part's shadow under a single low light. Refusals worked as designed (for
example, a frame with the square but no part → "No part found").
**(update)** with the lighting matrix below if run before posting.

| Condition | Captures | Result / refusal |
|---|---|---|
| Even desk light | **(update)** | |
| Uneven overhead | **(update)** | |
| Moderate shadow | **(update)** | |
| Part rotated | **(update)** | |
| No part / square hidden | **(update)** | refusal + guidance |

#### 6. What went wrong (and what I learned)

- **The display stayed dark across two bench sessions.** The panel never answered on I²C. The
  Waveshare 15→22 cable is *opposite-sided*: the gold fingers are on different
  faces at each end, so "same face up at both ends" is wrong. I found it with a
  continuity beeper because I don't own a multimeter. (Photos of the correct
  orientation are above.)
- **Enabling DSI turns off DisplayPort over USB-C** and left the port in
  device mode, so no webcam. The kiosk service forces the port to host mode
  and hands it back on exit.
- **Shadows are the enemy of silhouettes.** Illumination flattening fixed a
  lighting-gradient failure; shadows still inflate measurements. Controlled
  light from the MCU is the next fix.

#### 7. What's next

- STM32 capture trigger and ring light; bench validation across lighting
  conditions.
- Side-view capture for thread pitch and bolt vs screw.
- More object profiles (PCBs, flat brackets, turned parts), and multi-view
  capture toward 3D.

#### 8. Code and credits

- Code (Apache-2.0): https://github.com/Matthewjg95/PlatypusOne
- DSI panel overlay and drivers:
  [dcuartielles/uno_q_dsi_displays](https://github.com/dcuartielles/uno_q_dsi_displays)
- Arduino UNO Q Zephyr core and LED-matrix library
- Built with AI coding assistance (Claude Code)

---

## Form answer — "If you won the Dream Lab, what would you do with it?"

> Draft, about 100 words; edit to your voice.

I'd turn Engineering Scout from a bench prototype into a validated
instrument. Right now I debug hardware with a continuity beeper — that's how I
found the DSI cable fault that kept this display dark across two bench
sessions. A scope and
meter would let me bring up the STM32-driven capture trigger and ring light
properly, measure my own power budget, and verify the carrier I'm designing
for the handheld version. A proper bench also means real calibration and
validation data: measurements checked against gauges across lighting
conditions, published so other makers can trust the numbers — not just see a
demo.

---

## Shot list (about 45 minutes with the board)

1. **Hero photo:** board, carrier, panel on, webcam, calibration card. Daylight if
   possible.
2. **Evidence card on glass** for a real screw (photograph the panel).
3. **Lighting matrix:** 3–4 captures each in even light, uneven overhead,
   shadow, and rotated. Note calipers truth, measured value and any refusal.
   That fills §5's table.
4. **One refusal on purpose** (cover the square) → guidance on screen.
5. **One session:** three captures → FINISH → summary screen; open
   `outline.dxf` in Fusion 360 for a screenshot.
6. **Video under 60 s:** part down → tap → card → worse light → refusal →
   fix → finish.
7. Pull the records: `scp -r arduino@192.168.1.32:PlatypusOne/observations .`
   (and `sessions`).

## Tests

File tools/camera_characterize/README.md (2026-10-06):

# tools/camera_characterize

The camera evidence pipeline for the IMX219 bench-off (#40). It goes from
physical captures to a traceable report and a three-role decision gate.
Design and limits: [docs/hardware/CAMERA_CHARACTERIZATION.md](../../docs/hardware/CAMERA_CHARACTERIZATION.md).

**No camera result exists yet.** `tests/` uses synthetic fixtures, which test
software behaviour and are never camera evidence.

```sh
pip install -r tools/camera_characterize/requirements.txt          # host analysis only
cmake --build build --target scout_measure                         # Scout analyzer bridge
cc=tools/camera_characterize/camera_characterize.py

python3 $cc plan                                                   # the capture matrix
python3 $cc init <exp>/datasets/b0394-20261007 --camera B0394 --dataset-id b0394-20261007
python3 $cc capture <exp>/datasets/b0394-20261007 \
    --command 'tools/camera_characterize/capture_raw.sh {out}'     # on the UNO Q (stdlib only)
python3 $cc validate <exp>                                         # exit 1 on errors
python3 $cc all <exp>                                              # analyze + compare + report
python3 -m unittest discover -s tools/camera_characterize/tests -v
```

| Path | Role |
|---|---|
| `camchar/contract.py` | manifest schema + validation (stdlib) |
| `camchar/plan.py`, `matrix_spec.json` | capture matrix, dataset init, coverage (stdlib) |
| `camchar/capture.py`, `capture_raw.sh` | guided board-side capture (stdlib + v4l-utils). The script is **untested on hardware** |
| `camchar/images.py` | raw10p / raw16 / ABGR8888 / YUYV / PNG / PNM loaders (read-only) |
| `camchar/metrics.py` | exposure, region sharpness, edge rise |
| `camchar/calibration.py`, `camchar/target.py` | ChArUco calibration; printable target |
| `camchar/geometry.py` | centre vs edge residuals |
| `camchar/repeatability.py` | Scout measurements via `tools/scout_measure`, stats, accuracy |
| `camchar/decision.py`, `decision_criteria.json` | per-camera metrics, three-role gate. Criteria fixed before data |
| `camchar/report.py` | Markdown report + PCB/Fusion handoff block |
| `templates/experiment.json` | experiment manifest to copy |

Bump `ANALYSIS_VERSION` (`camchar/__init__.py`) whenever a change can alter a number.

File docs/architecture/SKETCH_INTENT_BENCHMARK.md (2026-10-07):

# Sketch intent resolver - benchmark report

Generated by `services/sketch_intent/bench/benchmark.py` (resolver `sketch-intent-0.1.0`, default parameters, tolerance 2.0 px). Deterministic; re-run to reproduce.

**Everything below except the washer section is synthetic.** GT discrepancy is measured against exact synthetic geometry and says how far the *proposal* is from the shape that generated the contour. It is not a statement about the accuracy of any camera, scale, or real part. Residuals inside proposals are fit diagnostics, not accuracy.

## Freeze status

Resolver code and parameters match `bench/FREEZE.json` (frozen 2026-10-07T09:23:41Z, source sha256 `d2bf462c42a2ccc5...`). The held-out set, the ShadowScan renders and the washer were first run after that freeze, and nothing was changed in response to them.

## Failure cases (generated)

Listed first so they are not lost in the tables. None of these was tuned away.

- **dev `rounded_rectangle`**: expectation `tangent` failed (got `{'true_in_gt/proposed': 3, 'true_in_gt/question': 1}`).
- **heldout `H_L_plate`**: expectation `kinds` failed (got `['line', 'line', 'line', 'line', 'line', 'line', 'line']`).
- **heldout `H_rounded_rect_small_r`**: expectation `closed` failed (got `[False]`).
- **heldout `H_noisy_rect_sigma1`**: expectation `kinds` failed (got `['freeform']`).
- **noise sweep `rectangle (90 deg)`, fixed tolerance 2 px, σ 0.75**: segmentation wrong (not 4 lines) in 5 of 5 runs; slowest run 4.7 s.
- **noise sweep `rectangle (90 deg)`, fixed tolerance 2 px, σ 1.0**: segmentation wrong (not 4 lines) in 5 of 5 runs; slowest run 11.7 s.
- **noise sweep `rectangle (90 deg)`, matched tolerance 3.5 px, σ 1.0**: segmentation wrong (not 4 lines) in 2 of 5 runs; slowest run 0.5 s.
- **noise sweep `rectangle (90 deg)`, matched tolerance 5.25 px, σ 1.5**: segmentation wrong (not 4 lines) in 1 of 5 runs; slowest run 0.8 s.
- **noise sweep `rectangle (90 deg)`, matched tolerance 7 px, σ 2.0**: segmentation wrong (not 4 lines) in 1 of 5 runs; slowest run 0.5 s.
- **noise sweep `skew 2 deg`, fixed tolerance 2 px, σ 0.75**: 22 perpendicular hypotheses PROPOSED on a skewed shape (silent perfection; 5 runs).
- **noise sweep `skew 2 deg`, fixed tolerance 2 px, σ 0.75**: segmentation wrong (not 4 lines) in 5 of 5 runs; slowest run 5.3 s.
- **noise sweep `skew 2 deg`, fixed tolerance 2 px, σ 1.0**: segmentation wrong (not 4 lines) in 5 of 5 runs; slowest run 12.3 s.
- **noise sweep `skew 2 deg`, matched tolerance 3.5 px, σ 1.0**: 2 perpendicular hypotheses PROPOSED on a skewed shape (silent perfection; 5 runs).
- **noise sweep `skew 2 deg`, matched tolerance 3.5 px, σ 1.0**: segmentation wrong (not 4 lines) in 1 of 5 runs; slowest run 0.5 s.
- **noise sweep `skew 2 deg`, matched tolerance 5.25 px, σ 1.5**: 21 perpendicular hypotheses PROPOSED on a skewed shape (silent perfection; 5 runs).
- **noise sweep `skew 2 deg`, matched tolerance 5.25 px, σ 1.5**: segmentation wrong (not 4 lines) in 1 of 5 runs; slowest run 0.5 s.
- **noise sweep `skew 2 deg`, matched tolerance 7 px, σ 2.0**: 20 perpendicular hypotheses PROPOSED on a skewed shape (silent perfection; 5 runs).
- **noise sweep `skew 2 deg`, matched tolerance 7 px, σ 2.0**: segmentation wrong (not 4 lines) in 1 of 5 runs; slowest run 0.4 s.
- **noise sweep `skew 6 deg`, fixed tolerance 2 px, σ 0.75**: 12 perpendicular hypotheses PROPOSED on a skewed shape (silent perfection; 5 runs).
- **noise sweep `skew 6 deg`, fixed tolerance 2 px, σ 0.75**: segmentation wrong (not 4 lines) in 5 of 5 runs; slowest run 4.5 s.
- **noise sweep `skew 6 deg`, fixed tolerance 2 px, σ 1.0**: segmentation wrong (not 4 lines) in 5 of 5 runs; slowest run 12.1 s.
- **noise sweep `skew 6 deg`, matched tolerance 3.5 px, σ 1.0**: segmentation wrong (not 4 lines) in 1 of 5 runs; slowest run 0.4 s.
- **noise sweep `skew 6 deg`, matched tolerance 5.25 px, σ 1.5**: segmentation wrong (not 4 lines) in 1 of 5 runs; slowest run 0.4 s.
- **noise sweep `skew 6 deg`, matched tolerance 7 px, σ 2.0**: 1 perpendicular hypotheses PROPOSED on a skewed shape (silent perfection; 5 runs).
- **noise sweep `skew 6 deg`, matched tolerance 7 px, σ 2.0**: segmentation wrong (not 4 lines) in 1 of 5 runs; slowest run 0.4 s.
- **density sweep scale 0.5, spacing 0.5 px**: primitives `llllllll` (expected alternating line/arc), closed True, 7 questions.
- **density sweep scale 0.5, spacing 1.0 px**: primitives `llllllll` (expected alternating line/arc), closed True, 4 questions.
- **density sweep scale 0.5, spacing 2.0 px**: primitives `llllllll` (expected alternating line/arc), closed False, 5 questions.
- **density sweep scale 0.5, spacing 4.0 px**: primitives `llllllll` (expected alternating line/arc), closed True, 4 questions.
- **density sweep scale 1.0, spacing 2.0 px**: primitives `llllalal` (expected alternating line/arc), closed False, 4 questions.
- **density sweep scale 1.0, spacing 4.0 px**: primitives `alalalll` (expected alternating line/arc), closed True, 2 questions.
- **density sweep scale 2.0, spacing 4.0 px**: primitives `alflal` (expected alternating line/arc), closed False, 0 questions.
- **ShadowScan `plate_with_holes.png`**: 4 analytic circles for 5 true holes.
- **ShadowScan `irregular_bracket.png`**: 1 analytic circles for 2 true holes.
- **ShadowScan `plate_with_cutout.png`**: hole errors beyond the corpus tolerance ±0.3 mm: [-0.333].
- **ShadowScan `rounded_plate_with_slot.png`**: hole errors beyond the corpus tolerance ±0.3 mm: [-0.366].
- **ShadowScan `pcb_board.png`**: 11 analytic circles for 12 true holes.
- **ShadowScan `pcb_board.png`**: 8156 hypotheses / 1275 questions - pairwise hypotheses do not scale to many features.
- **washer scan-0053**: the round washer's edges are not single circles within 0.222 mm; they split into arcs and 5 short lines.
- **washer scan-0053**: 2 perpendicular constraints PROPOSED between those spurious short lines (each ~5 deg from 90, inside the band because the lines are short): angular constraints on short segments are weakly determined and the decision rule does not say so.

## Development fixtures (used while writing the resolver)

| case | sampler | σ px | points | runtime ms | GT Hausdorff (worst loop) | false proposals | missed | true→question | expectations |
|---|---|---|---|---|---|---|---|---|---|
| noisy_rectangle | walk | 0.4 | 638 | 63 | 0.14 px / 0.014 mm | 0 | 0 | 0 | 3/3 |
| skewed_quadrilateral | walk | 0.4 | 640 | 70 | 0.13 px / 0.013 mm | 0 | 0 | 0 | 5/5 |
| rounded_rectangle | walk | 0.3 | 660 | 229 | 0.59 px / 0.059 mm | 0 | 0 | 1 | 4/5 (fail: tangent) |
| circle | walk | 0.4 | 376 | 35 | 0.05 px / 0.005 mm | 0 | 0 | 0 | 3/3 |
| partial_arc | walk | 0.4 | 279 | 61 | 0.71 px / 0.071 mm | 0 | 0 | 0 | 3/3 |
| missing_segment | walk | 0.4 | 589 | 76 | 26.46 px / 2.646 mm | 0 | 0 | 0 | 3/3 |
| outliers | walk | 0.4 | 640 | 101 | 0.13 px / 0.013 mm | 0 | 0 | 0 | 4/4 |
| plate_two_holes_and_slot | walk | 0.3 | 1328 | 188 | 0.18 px / 0.018 mm | 0 | 0 | 0 | 3/3 |
| small_scale_rectangle | walk | 0.25 | 320 | 36 | 0.14 px / 0.056 mm | 0 | 0 | 0 | 2/2 |
| large_sparse_rectangle | walk | 0.6 | 850 | 325 | 0.14 px / 0.004 mm | 0 | 0 | 0 | 2/2 |
| freeform_blob | walk | 0.3 | 635 | 837 | 1.13 px / 0.113 mm | 0 | 0 | 0 | 2/2 |
| uncalibrated_rectangle | walk | 0.4 | 640 | 64 | 0.13 px | 0 | 0 | 0 | 2/2 |

Constraint decisions scored against GT (dev): correctly_not_proposed 8, correctly_proposed 76, true_but_question 1

Failed expectations (reported, not tuned away):

- `rounded_rectangle` / tangent: got `{'true_in_gt/proposed': 3, 'true_in_gt/question': 1}`

<details><summary>Questions raised</summary>

- `rounded_rectangle`: c16 tangent g3/g2/g4: tangent (fillet between two lines): arc center moves 1.09 px, radius 23.93 -> 22.75 px; constrained max residual 2.51 px. Beyond the evidence band: accept as design intent?
- `missing_segment`: c15 collinear g5/g1: one straight edge across 52.9 px of missing contour? joint line max residual 0.94 px; the bridged part has no evidence. Beyond the evidence band: accept as design intent?
- `plate_two_holes_and_slot`: c27 equal_radius g5/g7: equal radius: 14.02 vs 12.55 px (10.5 % apart); constrained max residual 1.04 px. Inside the band, but the evidence fits clearly worse with it (RMS inflation): accept as design intent?
- `plate_two_holes_and_slot`: c28 equal_radius g5/g9: equal radius: 14.02 vs 12.11 px (13.7 % apart); constrained max residual 1.22 px. Inside the band, but the evidence fits clearly worse with it (RMS inflation): accept as design intent?
- `plate_two_holes_and_slot`: c29 equal_radius g6/g7: equal radius: 14.03 vs 12.55 px (10.5 % apart); constrained max residual 0.96 px. Inside the band, but the evidence fits clearly worse with it (RMS inflation): accept as design intent?
- `plate_two_holes_and_slot`: c30 equal_radius g6/g9: equal radius: 14.03 vs 12.11 px (13.7 % apart); constrained max residual 1.14 px. Inside the band, but the evidence fits clearly worse with it (RMS inflation): accept as design intent?

</details>

## Held-out fixtures (first run after the freeze; mostly raster-traced contours)

| case | sampler | σ px | points | runtime ms | GT Hausdorff (worst loop) | false proposals | missed | true→question | expectations |
|---|---|---|---|---|---|---|---|---|---|
| H_hexagon | raster | 0.2 | 484 | 63 | 1.57 px / 0.157 mm | 0 | 0 | 0 | 3/3 |
| H_L_plate | raster | 0.2 | 1026 | 177 | 1.68 px / 0.168 mm | 0 | 0 | 0 | 1/2 (fail: kinds) |
| H_trapezoid | raster | 0.2 | 620 | 62 | 0.53 px / 0.053 mm | 0 | 0 | 0 | 3/3 |
| H_triangle | raster | 0.2 | 648 | 65 | 0.36 px / 0.036 mm | 0 | 0 | 0 | 3/3 |
| H_near_rectangle_1deg | raster | 0.2 | 640 | 68 | 0.55 px / 0.055 mm | 0 | 0 | 0 | 2/2 |
| H_slot_plate | raster | 0.2 | 1268 | 198 | 101.77 px / 10.177 mm | 0 | 0 | 0 | 2/2 |
| H_four_equal_holes | raster | 0.2 | 1252 | 123 | 1.17 px / 0.117 mm | 0 | 0 | 0 | 2/2 |
| H_ellipse | raster | 0.2 | 545 | 291 | 1.01 px / 0.101 mm | 0 | 0 | 0 | 1/1 |
| H_rounded_rect_small_r | raster | 0.2 | 689 | 100 | 2.10 px / 0.210 mm | 0 | 0 | 3 | 0/1 (fail: closed) |
| H_noisy_rect_sigma1 | walk | 1.0 | 638 | 9607 | 3.27 px / 0.327 mm | 0 | 0 | 0 | 0/1 (fail: kinds) |

Constraint decisions scored against GT (heldout): correctly_not_proposed 4, correctly_proposed 58, true_but_question 3

Failed expectations (reported, not tuned away):

- `H_L_plate` / kinds: got `['line', 'line', 'line', 'line', 'line', 'line', 'line']`
- `H_rounded_rect_small_r` / closed: got `[False]`
- `H_noisy_rect_sigma1` / kinds: got `['freeform']`

<details><summary>Questions raised</summary>

- `H_hexagon`: c8 coincident g5/g6: junction vertex lies 2.21 px from the traced junction point. Beyond the evidence band: accept as design intent?
- `H_L_plate`: g1: corner region fits chamfer_line and fillet_arc; the evidence does not decide between them
- `H_L_plate`: g3: corner region fits sharp_corner and chamfer_line and fillet_arc; the evidence does not decide between them
- `H_near_rectangle_1deg`: c1 perpendicular g1/g2: perpendicular: measured 89.09 deg (0.91 deg from ideal); constrained max residual 1.63 px vs tolerance 2.00 px. Inside the band, but the evidence fits clearly worse with it (RMS inflation): accept as design intent?
- `H_near_rectangle_1deg`: c3 perpendicular g1/g4: perpendicular: measured 89.09 deg (0.91 deg from ideal); constrained max residual 1.63 px vs tolerance 2.00 px. Inside the band, but the evidence fits clearly worse with it (RMS inflation): accept as design intent?
- `H_near_rectangle_1deg`: c4 perpendicular g2/g3: perpendicular: measured 89.13 deg (0.87 deg from ideal); constrained max residual 1.80 px vs tolerance 2.00 px. Inside the band, but the evidence fits clearly worse with it (RMS inflation): accept as design intent?
- `H_near_rectangle_1deg`: c6 perpendicular g3/g4: perpendicular: measured 89.13 deg (0.87 deg from ideal); constrained max residual 1.80 px vs tolerance 2.00 px. Inside the band, but the evidence fits clearly worse with it (RMS inflation): accept as design intent?
- `H_rounded_rect_small_r`: g1: corner region fits sharp_corner and chamfer_line and fillet_arc; the evidence does not decide between them
- `H_rounded_rect_small_r`: g4: corner region fits sharp_corner and chamfer_line and fillet_arc; the evidence does not decide between them
- `H_rounded_rect_small_r`: c1 parallel g1/g2: parallel: measured 1.10 deg (1.10 deg from ideal); constrained max residual 2.02 px vs tolerance 2.00 px. Beyond the evidence band: accept as design intent?
- `H_rounded_rect_small_r`: c2 perpendicular g1/g3: perpendicular: measured 88.99 deg (1.01 deg from ideal); constrained max residual 2.00 px vs tolerance 2.00 px. Beyond the evidence band: accept as design intent?
- `H_rounded_rect_small_r`: c3 parallel g1/g5: parallel: measured 1.08 deg (1.08 deg from ideal); constrained max residual 2.02 px vs tolerance 2.00 px. Beyond the evidence band: accept as design intent?
- `H_rounded_rect_small_r`: c11 coincident g1/g2: near-collinear junction (1.10 deg): vertex is ill-conditioned; merge or keep as a step?. Beyond the evidence band: accept as design intent?
- `H_rounded_rect_small_r`: g1 (L0): the proposed constraints applied together move it 2.02 px from its evidence, beyond the 2 px band (each passed alone). Review c4, c16.

</details>

## Noise sensitivity (perpendicular decisions)

Each row: the same shape re-sampled with independent seeds. Counts are over 4 corner hypotheses × runs. A *proposed* perpendicular on a skewed shape is silent perfection.

Tolerance policies: *fixed* = the default 2 px; *matched* = max(2, 3.5 σ), the documented rule that the band must cover the contour's own noise (σ known here; on real data it must be measured from the contour source, never chosen to get an answer).

| shape | policy | tol px | σ px | runs | runs with 4 lines | perpendicular decisions | GT Hausdorff median / max px | slowest run s |
|---|---|---|---|---|---|---|---|---|
| rectangle (90 deg) | fixed | 2 | 0.0 | 5 | 5 | proposed 20 | 0.13 / 0.13 | 0.1 |
| rectangle (90 deg) | fixed | 2 | 0.25 | 5 | 5 | proposed 20 | 0.13 / 0.13 | 0.1 |
| rectangle (90 deg) | fixed | 2 | 0.5 | 5 | 5 | proposed 20 | 0.13 / 0.94 | 0.1 |
| rectangle (90 deg) | fixed | 2 | 0.75 | 5 | 0 | proposed 27, question 19 | 1.49 / 2.38 | 4.7 |
| rectangle (90 deg) | fixed | 2 | 1.0 | 5 | 0 | proposed 76, question 47 | 3.08 / 8.63 | 11.7 |
| rectangle (90 deg) | matched | 2 | 0.5 | 5 | 5 | proposed 20 | 0.13 / 0.94 | 0.1 |
| rectangle (90 deg) | matched | 3.5 | 1.0 | 5 | 3 | proposed 22 | 1.09 / 2.79 | 0.5 |
| rectangle (90 deg) | matched | 5.25 | 1.5 | 5 | 4 | proposed 22, question 2 | 0.22 / 0.73 | 0.8 |
| rectangle (90 deg) | matched | 7 | 2.0 | 5 | 4 | proposed 23, question 3 | 0.30 / 5.02 | 0.5 |
| skew 2 deg | fixed | 2 | 0.0 | 5 | 5 | question 20 | 0.13 / 0.13 | 0.1 |
| skew 2 deg | fixed | 2 | 0.25 | 5 | 5 | question 20 | 0.13 / 0.13 | 0.1 |
| skew 2 deg | fixed | 2 | 0.5 | 5 | 5 | question 20 | 0.14 / 0.17 | 0.1 |
| skew 2 deg | fixed | 2 | 0.75 | 5 | 0 | proposed 22, question 39 | 1.61 / 1.83 | 5.3 |
| skew 2 deg | fixed | 2 | 1.0 | 5 | 0 | - | 2.93 / 3.82 | 12.3 |
| skew 2 deg | matched | 2 | 0.5 | 5 | 5 | question 20 | 0.14 / 0.17 | 0.1 |
| skew 2 deg | matched | 3.5 | 1.0 | 5 | 4 | proposed 2, question 20 | 0.25 / 2.46 | 0.5 |
| skew 2 deg | matched | 5.25 | 1.5 | 5 | 4 | proposed 21, question 1 | 1.90 / 2.00 | 0.5 |
| skew 2 deg | matched | 7 | 2.0 | 5 | 4 | proposed 20 | 1.95 / 5.39 | 0.4 |
| skew 6 deg | fixed | 2 | 0.0 | 5 | 5 | rejected_by_evidence 20 | 0.13 / 0.13 | 0.1 |
| skew 6 deg | fixed | 2 | 0.25 | 5 | 5 | rejected_by_evidence 20 | 0.13 / 0.14 | 0.1 |
| skew 6 deg | fixed | 2 | 0.5 | 5 | 5 | rejected_by_evidence 20 | 0.14 / 0.18 | 0.1 |
| skew 6 deg | fixed | 2 | 0.75 | 5 | 0 | proposed 12, question 26, rejected_by_evidence 22 | 5.45 / 6.13 | 4.5 |
| skew 6 deg | fixed | 2 | 1.0 | 5 | 0 | - | 2.94 / 3.82 | 12.1 |
| skew 6 deg | matched | 2 | 0.5 | 5 | 5 | rejected_by_evidence 20 | 0.14 / 0.18 | 0.1 |
| skew 6 deg | matched | 3.5 | 1.0 | 5 | 4 | question 19, rejected_by_evidence 3 | 0.25 / 2.61 | 0.4 |
| skew 6 deg | matched | 5.25 | 1.5 | 5 | 4 | question 22 | 0.35 / 0.63 | 0.4 |
| skew 6 deg | matched | 7 | 2.0 | 5 | 4 | proposed 1, question 18 | 0.44 / 5.89 | 0.4 |

## Scale and sampling density (rounded rectangle, σ 0.3 px)

| scale | spacing px | points | primitives (l/a) | expected kinds | closed | GT Hausdorff px | questions | runtime ms |
|---|---|---|---|---|---|---|---|---|
| 0.5 | 0.5 | 660 | llllllll | False | True | 1.31 | 7 | 103 |
| 0.5 | 1.0 | 330 | llllllll | False | True | 0.79 | 4 | 80 |
| 0.5 | 2.0 | 162 | llllllll | False | False | 1.78 | 5 | 90 |
| 0.5 | 4.0 | 80 | llllllll | False | True | 1.02 | 4 | 52 |
| 1.0 | 0.5 | 1324 | alalalal | True | True | 0.39 | 1 | 311 |
| 1.0 | 1.0 | 660 | alalalal | True | True | 0.26 | 2 | 249 |
| 1.0 | 2.0 | 330 | llllalal | False | False | 2.10 | 4 | 149 |
| 1.0 | 4.0 | 162 | alalalll | False | True | 1.52 | 2 | 152 |
| 2.0 | 0.5 | 2648 | alalalal | True | True | 0.13 | 0 | 828 |
| 2.0 | 1.0 | 1324 | alalalal | True | True | 0.16 | 3 | 408 |
| 2.0 | 2.0 | 660 | alalalal | True | True | 0.51 | 0 | 279 |
| 2.0 | 4.0 | 330 | alflal | False | False | 0.74 | 0 | 243 |

## External evaluation: ShadowScan synthetic renders

Contours traced from `corpus/photos/*.png` with a plain Otsu threshold (this harness, not ShadowScan's pipeline). Scale = corpus `ref-width` / traced outer width, so the outer width is not an independent check; hole diameters are. Renders are synthetic.

| image | loops | kinds | hole truth mm | circles found | circle Ø mm | error to nearest truth mm (corpus tol) | equal radius (circle pairs scored) | hypotheses | questions | closed loops |
|---|---|---|---|---|---|---|---|---|---|---|
| plate_with_holes.png | 6 | lllll; c; c; c; c; aa | 5x4, 12x1 | 4/5 | [4.824, 4.886, 4.978, 11.884] | [-0.176, -0.114, -0.022, -0.116] (±0.3) | {'same_truth/proposed': 3, 'unscored/proposed': 3, 'unscored/question': 4} | 27 | 16 | 4/6 |
| irregular_bracket.png | 3 | lllllll; c; aa | 6.5x2 | 1/2 | [6.394] | [-0.106] (±0.3) | {'unscored/question': 2, 'unscored/proposed': 1} | 28 | 11 | 2/3 |
| washer.png | 2 | aa; c | 21x1 | 1/1 | [20.811] | [-0.189] (±0.3) | {'unscored/proposed': 1} | 5 | 3 | 1/2 |
| plate_with_cutout.png | 4 | lllll; lllll; c; c | 4x2 | 2/2 | [3.667, 3.931] | [-0.333, -0.069] (±0.3) | {'same_truth/question': 1} | 47 | 22 | 3/4 |
| rounded_plate_with_slot.png | 4 | alalalal; alal; c; c | 4.5x2 | 2/2 | [4.134, 4.444] | [-0.366, -0.056] (±0.3) | {'unscored/proposed': 7, 'same_truth/question': 1} | 41 | 9 | 4/4 |
| pcb_board.png | 52 | llllllll; c; c; c; c; c; c; c; c; c; c; c; all; alllalll; llllllllll; alllalll; llalll; llalll; llaa; llalll; lllf; lall... | 3.2x12 | 11/12 | [3.276, 3.288, 3.317, 3.319, 3.322, 3.322, 3.328, 3.331, 3.345, 3.356, 3.357] | [0.076, 0.088, 0.117, 0.119, 0.122, 0.122, 0.128, 0.131, 0.145, 0.156, 0.157] (±0.25) | {'same_truth/proposed': 55, 'unscored/question': 326, 'unscored/proposed': 660} | 8156 | 1275 | 19/52 |

Kinds legend: l line, a arc, c circle, f freeform.
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

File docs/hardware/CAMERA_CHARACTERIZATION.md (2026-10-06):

# Camera characterization — evidence to decision (#40)

Status, 2026-10-06:

- **The pipeline is built and tested on synthetic fixtures only.**
- **No camera has been characterized.** No camera role is chosen.
- Nothing on this page is a measured camera result unless it is marked MEASURED, with its source.

```
physical capture (UNO Q)          capture_raw.sh + `camera_characterize capture`
  → immutable source evidence     frames/ + sha256 in dataset.json; never rewritten
  → metadata validation           `validate`: contract, files, sizes, hashes, plan coverage
  → calibration / image quality   `analyze`: ChArUco intrinsics, centre/edge geometry,
                                  edge-rise focus, exposure, Scout measurements
  → repeatability                 unmoved series → spread; verified truth → accuracy
  → comparable metrics + gate     `compare`: per-camera metrics, three roles or
                                  INSUFFICIENT EVIDENCE (decision_criteria.json)
  → report                        `report`: derived/<version>/report.md
```

One command, once the datasets are in place:
`python3 tools/camera_characterize/camera_characterize.py all <experiment>`.
The tool is in [`tools/camera_characterize/`](../../tools/camera_characterize/README.md);
the capture plan is in [CAMERA_CAPTURE_MATRIX.md](CAMERA_CAPTURE_MATRIX.md).

## 1. What is known about the three cameras

| Fact | Class | Source |
|---|---|---|
| All three are Sony IMX219 8 MP modules | DOCUMENTED | Arducam listings via #40 |
| B0394: M12 manual focus, ~75° H / 60° V, "<3 %" lens distortion, 24 × 25 mm board | DOCUMENTED (vendor) | #40. The "<3 %" figure is the vendor's definition on the vendor's sample, **not our calibrated distortion** |
| B0390: fixed focus, ~62.2° H, 25 × 24 mm | DOCUMENTED (vendor) | #40 |
| B0393: motorized focus. On Raspberry Pi, autofocus needs `dtoverlay=imx219,vcm` plus the rpicam/libcamera RPi IPA tuning `imx219_af.json` | DOCUMENTED | [Arducam IMX219 motorized-focus guide](https://docs.arducam.com/Raspberry-Pi-Camera/Motorized-Focus-Camera/Quick-Start-Guide/IMX219-Motorized-Focus-Camera/) (lists B0393) |
| On the Pi, that overlay declares the lens as an `adi,ad5398` VCM at I2C `0x0c`, linked to the sensor through `lens-focus` | DOCUMENTED | [raspberrypi/linux `imx219-overlay.dts`](https://github.com/raspberrypi/linux/blob/rpi-6.12.y/arch/arm/boot/dts/overlays/imx219-overlay.dts) |
| UNO Q kernel 7.0.0 has `imx219.ko` and Arduino `imx219-csi{0,1}-{2,4}lanes` overlays | MEASURED | board filesystem, PR #42 bench log |
| B0393 enumerates on CAMERA1 after the overlay fix + re-bind; ABGR8888 640×480 / 1280×720 at ~60 fps via libcamera's simple pipeline; ≥1640×1232 fails (32 MB CMA) | MEASURED | PR #42 bench log 2026-10-04 (raw run dirs not yet archived in the repo) |
| Raw SRGGB10 packed 1640×1232 (2056 B/line, black ~64) streams via camss/v4l2 | MEASURED | PR #42, run `B0393/20261004T232839Z-raw` |
| **B0393: no lens/VCM subdevice enumerates on UNO Q; lens rests at far focus, blurry at ~15 cm** | MEASURED (compatibility result) | PR #42, run `B0393/20261004T233254Z-all` |
| CSI camera "up" on UNO Q | REPORTED, unarchived | Matthew, #40 comment 2026-10-04. SKU/still/reboot/mode not recorded |
| B0394 enumeration on UNO Q | UNKNOWN | ENXIO before the overlay fix; not re-tested in the record |
| B0390 on UNO Q | UNKNOWN | never confirmed (one run was actually the B0393) |
| UNO Q kernel has an `adi,ad5398` lens driver; Arduino overlays describe a lens node | UNKNOWN → BENCH | `modinfo ad5398`, `find /lib/modules -name '*ad5398*'`, live DT. The empty lens subdev suggests no (INFERRED) |
| Calibrated intrinsics, distortion, edge geometry, focus envelope, repeatability, accuracy, lighting robustness | BENCH REQUIRED | this pipeline, once the matrix is captured |

**Do not install Raspberry Pi autofocus software on the UNO Q.** `imx219_af.json`
belongs to the RPi vc4 IPA, and the UNO Q runs libcamera's simple pipeline
with no AF algorithm. Until a lens subdevice exists on the UNO Q, the B0393's
lens rests at an unknown position that no software can read or set
(`focus_mode: not_exposed`). That is a platform-compatibility result
(`focus_control_exposed: false`). It is **not** a reproducible focus state:
the gate's `focus_state_recorded` criterion stays INSUFFICIENT for it. Only
separate evidence, plus a recorded criteria change, could establish that the
rest position repeats.

## 2. Evidence contract

Schemas: `platypus.camera_experiment/1` and `platypus.camera_dataset/1`. The
code is [`camchar/contract.py`](../../tools/camera_characterize/camchar/contract.py).

```
<experiment>/experiment.json          datasets compared, representative distance
<experiment>/datasets/<id>/dataset.json
<experiment>/datasets/<id>/frames/    immutable sources (+ capture logs)
<experiment>/datasets/<id>/capture_plan.json   planned cells (coverage)
<experiment>/derived/<ANALYSIS_VERSION>/       everything computed; deletable
```

| Block | Fields (all required; `"UNKNOWN"` allowed and reported) |
|---|---|
| `camera` | sku, sensor, silkscreen, revision, unit_id, lens, focus_type |
| `platform` | host, repo_sha, kernel, image, csi_port, enumeration, capture_stack |
| `bringup` (gate input) | enumerates, reboot_repeat, dsi_coexistence, focus_control, evidence (csi_bench run dirs) |
| `physical` (gate + handoff) | board_w_mm, board_h_mm, lens_stack_mm, mounting_holes, optical_center_offset_mm, connector_side, cable. Each is `{value, status, source}`; only `status: measured` counts |
| `targets` | `charuco` (squares, square_mm, marker_to_square, dictionary), `scout_reference` (reference_mm), `planar_part` (truth length/width). Every dimension carries a status: `verified` / `nominal_unverified` / UNKNOWN |
| per frame (or `defaults`) | capture_command, pixel_format, frame_rate, exposure_us, analogue_gain, white_balance, focus_mode, focus_position, working_distance_mm, scene, placement, lighting, targets, timestamp_utc |
| per ok frame | frame_id, path, sha256, format (`raw10p` / `raw16` / `abgr8888` / `yuyv` / `png` / `pgm` / `ppm`), width, height; raw Bayer also stride, bayer_pattern, black_level, white_level |
| optional | plan_cell, plan_index, repeat_series, repeat_index, calibration_set, mount_id, notes |
| `mount_id` (calibration frames) | the physical mounting the set was taken on. `init` writes `<dataset_id>/mount-1` for set A and `.../mount-2` for set B (after remount). Constant within a set, or the set is invalid |
| failures | `outcome: capture_failed / discarded` + `failure_reason`. Kept in the record, never analysed, listed in the report |

**Rules:**

- Unknown means `"UNKNOWN"`. The validator warns, and the gate treats it as missing evidence.
- A sha256 mismatch, a missing file, a wrong size, or a path outside the dataset
  excludes that frame.
- A schema or section error refuses the whole analysis.
- `analyze` never opens a source for writing. It re-hashes every source after
  the run and aborts on any change.
- Adding a camera means adding a dataset with a new `sku`. The architecture does not change.

**Storage (decision for Matthew):** one raw frame is 2.53 MB, so about 75 frames
per camera comes to roughly 190 MB per camera. Recommendation:

- commit `experiment.json`, the `dataset.json` files, `capture_plan.json`, the
  capture logs and `derived/`;
- archive each dataset's `frames/` as a zip on a GitHub release (or Git LFS);
- record the zip's sha256 in the experiment notes.

The per-frame hashes in `dataset.json` keep the evidence verifiable either way.

## 3. Analyses and their limits

| Analysis | Output | Limits (by design) |
|---|---|---|
| Exposure | mean, median, p01/p99, RMS contrast, clipped % (≥99.5 % full scale), crushed % (≤0.5 %) | raw is linear; ABGR/YUYV/PNG are tone-mapped. Compare within one format only |
| Region sharpness | normalised Tenengrad and Laplacian variance on a 3×3 grid; corner/centre ratio | scene-dependent: compare the same scene and placement only |
| Edge rise (focus) | median 10–90 % width (px) of the 20 mm reference square's edges, 9 profiles per edge | blur of the whole chain at that pixel grid. Comparable across distances, at the same resolution only. Not MTF and not a resolution claim |
| Calibration | OpenCV pinhole k1 k2 p1 p2 k3 from ChArUco: K, distortion, std devs, per-view RMS, accepted/rejected views with reasons, coverage, model displacement at image corners, undistortion preview | no post-hoc view rejection. A set is invalid if the focus state changes inside it. Minimum 10 views |
| Calibration stability | `calibration_independent_sets` = distinct `mount_id`s among ok sets at one size; max relative fx/fy difference across those mountings | a set without a mount_id, or repeating one already counted (A + A, or the same mount in two datasets), does not count as independent. Fewer than two independent mountings → INSUFFICIENT (never FAIL); only the measured delta can fail |
| Centre / edge geometry | per ChArUco frame: reprojection RMS by zone; line-straightness RMS as captured and after undistortion; planar residual (mm) | the planar residual uses the board's own scale: shape, not absolute accuracy |
| Repeatability | Scout length/width through `scout_measure` (the product analyzer, unchanged): n accepted/refused, mean, std, range, relative spread; as captured and undistorted | unmoved series only |
| Accuracy | mean (bias), mean \|error\| and max \|error\| against the part's **verified** truth | never computed from nominal dimensions. **No correction factor is ever applied** |
| Temporal noise | median per-pixel std across an unmoved series | only meaningful when nothing moved |

Zones: radius from the principal point, normalised to the farthest image
corner. Centre is below 1/3; edge is 2/3 and above.

## 4. Decision gate

[`decision_criteria.json`](../../tools/camera_characterize/decision_criteria.json)
fixes every threshold **before any physical frame was analysed**. Every report
carries its sha256.

**Roles:**

- **Reference / measurement:** stable intrinsics, calibratable distortion,
  centre ≈ edge geometry, repeatable focus, a working envelope, and Scout repeatability.
- **Compact product:** packaging limits plus adequate geometry, envelope,
  focus behaviour, stability, and bring-up.
  - The board and lens-stack limits are deliberately `null` until Fusion
    supplies them (#41/#33).
  - So the product role is INSUFFICIENT EVIDENCE by construction until then.
- **Fallback:** known working path, predictable over reboots and lighting, and
  distinct from the product camera.

**Outcomes:**

- **PROPOSED:** exactly one eligible camera. Matthew confirms it.
- **CANDIDATES:** several are eligible; there is no automatic tie-break.
- **INSUFFICIENT EVIDENCE:** a needed metric or threshold is missing.
- **NO ELIGIBLE CAMERA:** every camera failed at least one criterion.

Focus rules:

- `fixed`, `manual_locked`, or `motorized_position` with a recorded position
  on every quantitative frame → PASS.
- `auto`, or a motor position missing → FAIL.
- UNKNOWN, `not_exposed`, or a motorized module claiming fixed/manual →
  INSUFFICIENT.
- `focus_control_exposed` reports platform compatibility separately and is not
  a criterion.

There is no weighted score. Synthetic datasets can never produce a role.
Criteria changes are listed in `decision_criteria.json → changes`. Revision r2
was made after independent review, before any data, and changed no threshold
value.

## 5. Reuse — what already existed

| Existing | Used as |
|---|---|
| `tools/csi_bench/csi_bench.sh` + CSI_CAMERA_BENCH.md (PR #42, open) | bring-up evidence (T1–T4, T10) feeding `bringup`; not duplicated |
| Raw capture recipe (PR #42 bench log) | packaged as `capture_raw.sh`. **Never run as a script** |
| `services/vision` ScoutAnalyzer | measured through `tools/scout_measure` (new ~140-line bridge, no new measurement logic) |
| `docs/hardware/calibration_sheet.pdf` (20 mm square) | Scout reference + edge-rise target |
| Engineering Observation evidence classes | observed (pixel facts), derived (mm), unresolved (UNKNOWN) |
| `hardware/pcb/CAMERA_EVIDENCE_INTAKE.md` | the PCB consumer; the report's "PCB / Fusion handoff" block maps onto its tables B/C |

New: a ChArUco target, because the existing sheet cannot constrain
distortion. 7×10 squares, 20 mm, 14 mm DICT_4X4_50 markers:
[`targets/charuco_7x10_20mm.svg`](../../tools/camera_characterize/targets/charuco_7x10_20mm.svg).

- Print at 100 % on matte paper and mount it flat.
- Measure 6 squares with calipers before setting `square_mm_status: verified`.
- Its dimensions are not claimed until measured. Intrinsics do not depend on
  the square size; mm residuals and accuracy do.

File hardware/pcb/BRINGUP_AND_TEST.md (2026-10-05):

# Perception Head Rev A — bring-up and test strategy

Defined **before layout** so the board is built to be debugged. Reference
designators and test points are from the Rev A schematic.

## 1. Safe power-up configuration (by hardware, no firmware involved)

| Function | Default with host absent / in reset / expander at POR | Mechanism |
|---|---|---|
| ToF rail (+3V3_TOF) | **OFF** | R7 pulls U1 EN low; TCA9534 POR = inputs |
| Illumination 5 V | **OFF** | R13 pulls U3 EN low |
| LED current set-point | **0 mA** | R17 pulls ILLUM_VSET to 0 V when ILLUM_SET floats |
| Illumination hard kill | available | close JP1 → ILLUM_EN tied to GND (R27 isolates the expander) |
| EEPROM | **write-protected** | R24 pulls WP high |
| ToF interface mode | I2C | R9 straps SPI/I2C low |
| IMU address | 0x68 | R11 SDO → GND |
| IMU INT1/INT2, expander P2 | defined low | R30/R29/R28 100 kΩ pull-downs |

**Firmware init order for U6 (mandatory):** write Output register (0x01) = 0x00
→ then Configuration register (0x03) with P0, P3, P4, P7 as outputs; leave P1
(TOF_LPN), P2, P5, P6 as inputs. Writing config first would drive outputs to the
POR value 0xFF (ToF on, LEDs enabled, EEPROM writable).

## 2. Failure isolation (the RGB path must survive everything)

The camera's CSI path never touches this board electrically. The head draws
only from host 5 V and 3V3 and drives only MCU pins. Required demonstrations:

| Fault injected | Expected | Check |
|---|---|---|
| J1 unplugged while Linux captures | CSI preview/capture unaffected | capture before/after, no kernel errors |
| ToF rail off / carrier removed | bus A (IMU/EEPROM/expander) still ACKs; bus B absent | i2c scans |
| ToF hung | power-cycle via P0 (≥10 ms off) recovers it without touching bus A | scope TP6/TP7 |
| LED short on J3 | U3 limits, FAULT (TP26) low, host 5 V stays in spec | scope TP1/TP3 |
| IMU dead | ToF + illumination unaffected | — |
| EEPROM blank/corrupt | software reports "uncalibrated head", capture still allowed | firmware test |

## 3. Bring-up sequence (per board)

Instruments: current-limited bench supply, DMM, scope (≥2 ch), USB-C meter,
UNO Q + harness, Pololu #3419, a dummy LED load (one white LED on a GH lead),
thermocouple or IR thermometer.

| Step | Action | Pass criteria | Stop if |
|---|---|---|---|
| B0 | Unpowered: inspect, photograph both sides; resistance +5V_HOST→GND, +3V3_HOST→GND, TOF_LDO_OUT→GND, +5V_ILLUM→GND | No short (capacitor charge ramps are OK) | <10 Ω sustained |
| B1 | **3V3 only** via J2 (Qwiic) from bench supply 3.3 V, 50 mA limit | TP5 ≈3.3 V, SH3 drop → logic current ≤5 mA; TP6, TP3 ≈0 V | current-limit hit |
| B2 | Replace the bench supply with the UNO Q Qwiic cable on J2; scan bus A | ACK 0x20, 0x50, 0x58, 0x68 | missing device → rework that device only |
| B3 | Expander safe-init (order above); toggle P7 | D2 blinks; TP20 and TP25 stay low until commanded | outputs glitch high |
| B4 | EEPROM: read serial, attempt write with WP high (must fail), WP low (P4) write/readback record | serial non-zero/stable; write blocked/allowed as expected | — |
| B5 | IMU: chip ID, 8 kB config upload, data-ready on IMU_INT1 (TP21) | INT pulses at set ODR; gravity ≈1 g | — |
| B6 | Add **+5V** via J1, 200 mA limit, ToF still off | TP2 ≈5 V; +5V_HEAD current <1 mA; TP3 ≈0 | — |
| B7 | Enable ToF rail (P0) **without** carrier | TP6 = 3.29 V ±2 % (3.23–3.36 V); rise monotonic | out of range → check R5/R6 |
| B8 | Fit Pololu carrier (unpowered), enable rail | TP8 AVDD ≥3.13 V, TP9 1.8 V; ACK 0x29 on bus B | AVDD low → T2 |
| B9 | ULD init + ranging 4×4 @10 Hz then 8×8 @15 Hz, 30 min | SH2 voltage → ToF current (record); AVDD under load; INT on TP17; frames valid | resets, AVDD <3.13 V |
| B10 | Scope I2C_B, TOF_INT_N and TOF_SYNC (open-drain) at the real harness length, 400 kHz and 1 MHz, with host 3V3 at its actual value; repeat with C18/C19 fitted | clean edges; I2C_B low ≤0.15 V at the carrier; high ≥ VCC(B) − 0.4 V; levels match ICD §5a | oscillation → T4 mitigation |
| B11 | ToF reset: P0 low 10 ms → TP6 <0.3 V → re-enable → re-init | recovers every time (20 cycles); bus A unaffected | back-feed holds rail up → T5 |
| B12 | Illumination with dummy LED on J3, JP1 open: ILLUM_EN high, ILLUM_SET 0 → 3.3 V in steps | TP27 (mV) = mA, linear to ~254 mA; no ringing on TP27 (else fit C15) | runaway / oscillation |
| B13 | Thermal at full scale, 5 min continuous | Q1/Q2 rise recorded; LED temp recorded | >80 °C case → duty limit |
| B14 | Limit test: short J3 pins via 1 Ω | U3 limits ≈0.6–0.7 A, FAULT low (TP26), host 5 V stays ≥4.75 V | host resets |
| B15 | Integration: UNO Q + Media Carrier + display + CSI camera + head all running | §2 table; power matrix row recorded | any CSI/DSI regression |

Record every step in an evidence file (photos, scope captures, numbers, board
serial from B4) — same discipline as `docs/contest/evidence/`.

## 4. Current-measurement strategy

| Quantity | How | Resolution with a 4½-digit DMM |
|---|---|---|
| Head 5 V current | V across SH1 (0.05 Ω) at TP1/TP2 | 0.1 mV → 2 mA |
| ToF current | V across SH2 (0.1 Ω) at TP6/TP7 | 0.1 mV → 1 mA |
| Logic current | V across SH3 (1 Ω) at TP4/TP5 | 0.1 mV → 0.1 mA |
| LED current ch1/ch2 | V at TP27/TP28 to GND (1 Ω) | 1 mV = 1 mA |
| System current | USB-C inline meter on UNO Q input | per meter spec |
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

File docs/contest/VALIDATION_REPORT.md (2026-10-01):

# Scout validation report

Generated by `tools/scout_validation` against `vision.scout_analyzer.v3` +
`ai.fastener_classifier.v2` on the synthetic ground-truth battery. Regenerate
with `scout_validation REPORT.md`; the output is deterministic for a given
build. Failure cases PASS when the pipeline refuses for the expected reason.
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

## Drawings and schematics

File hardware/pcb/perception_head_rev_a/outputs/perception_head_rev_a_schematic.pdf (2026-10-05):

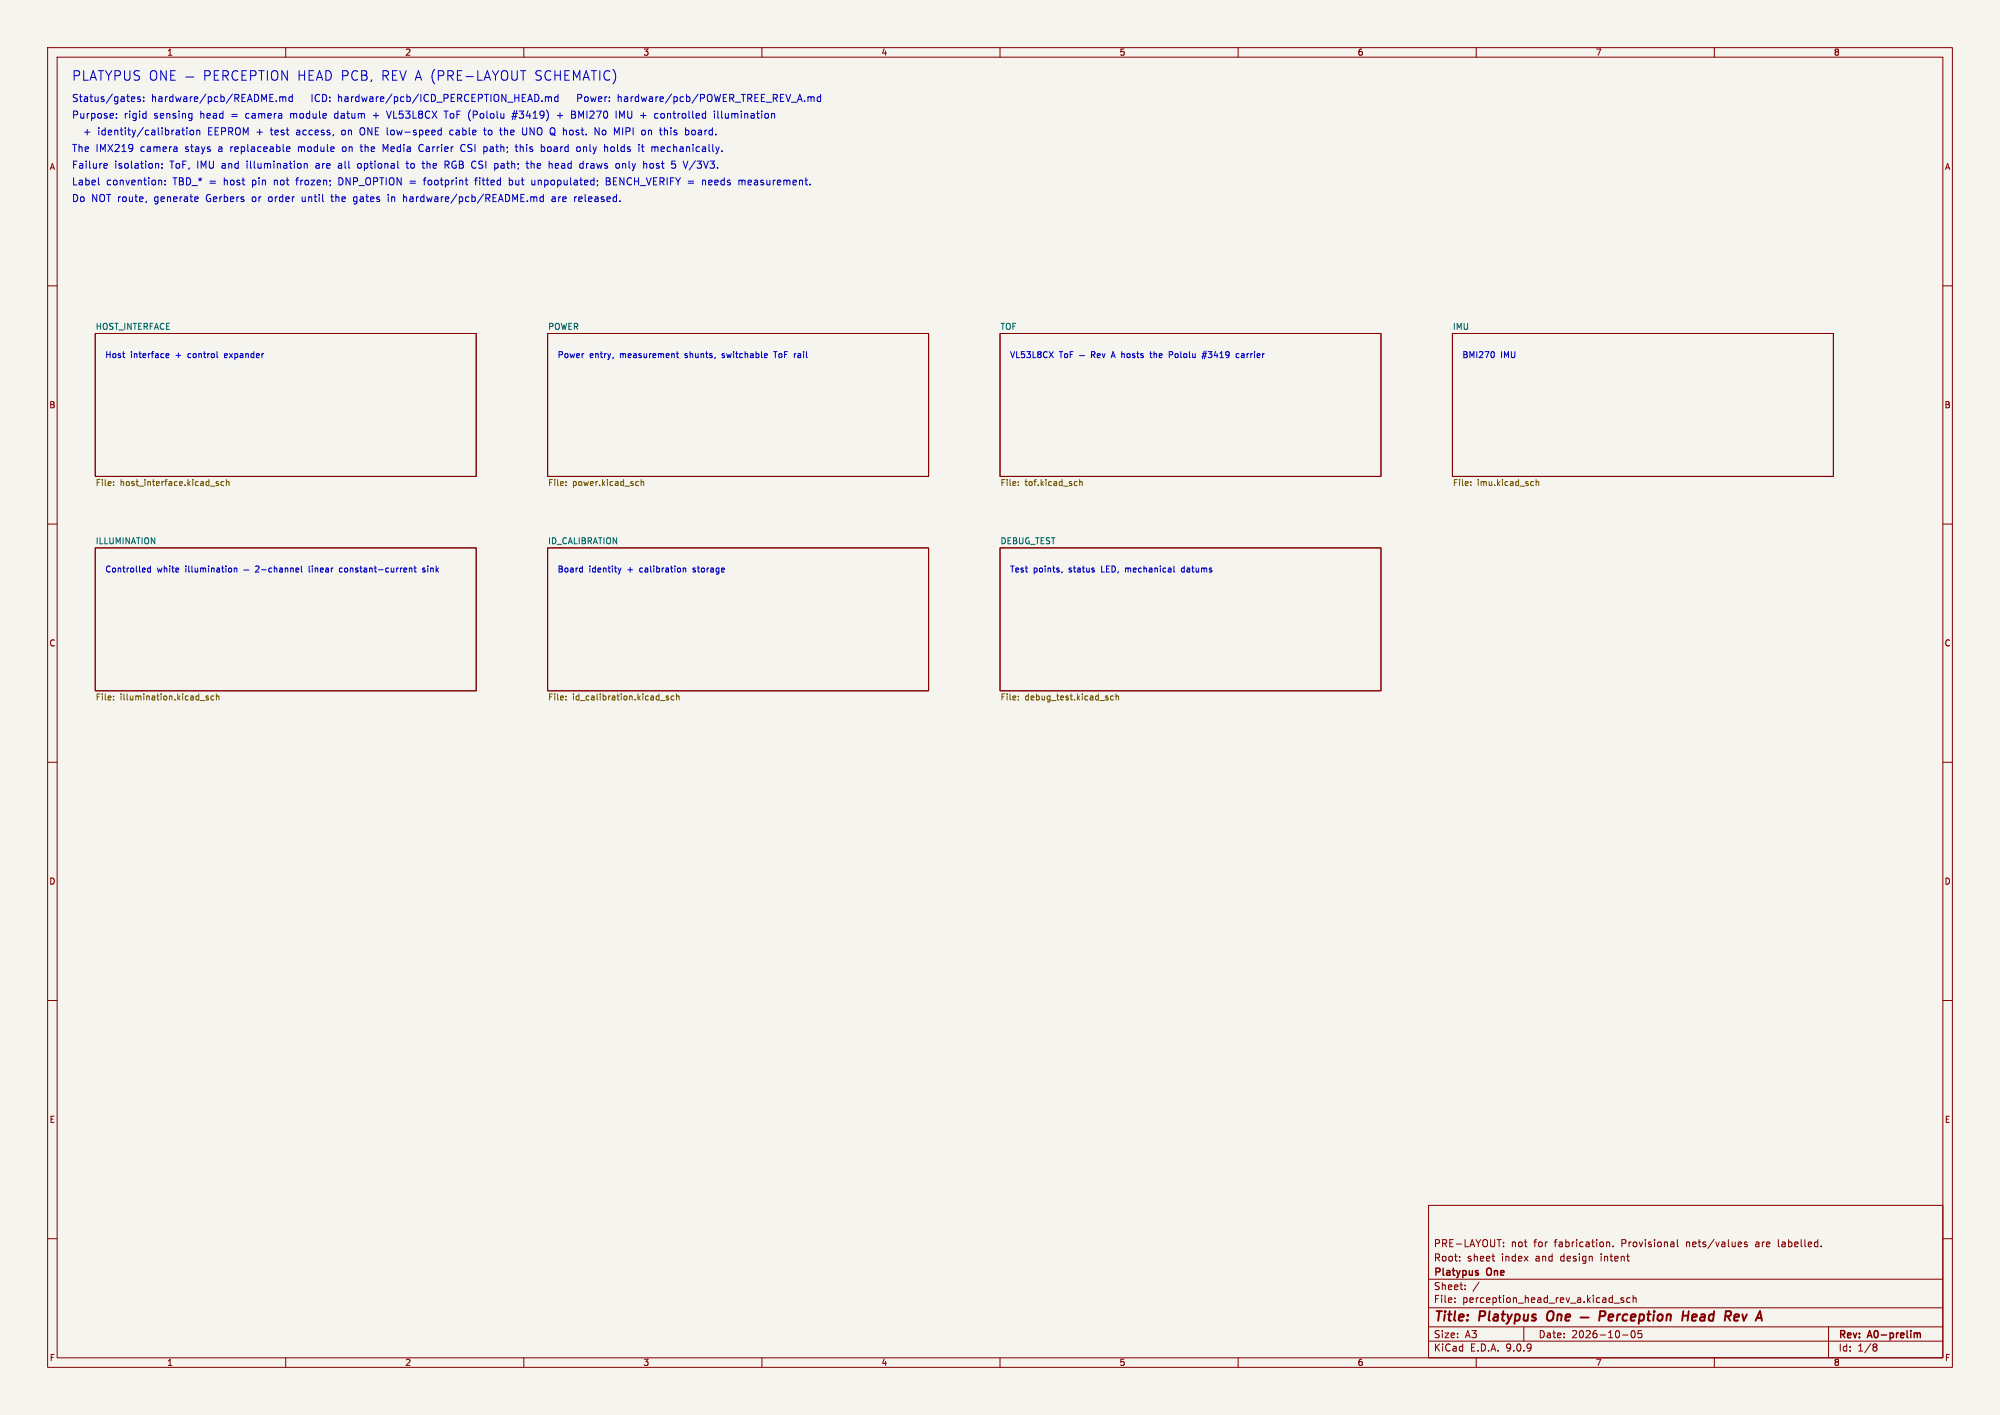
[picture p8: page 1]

Id: 1/8 Title: Platypus One þÿ Perception Head Rev A

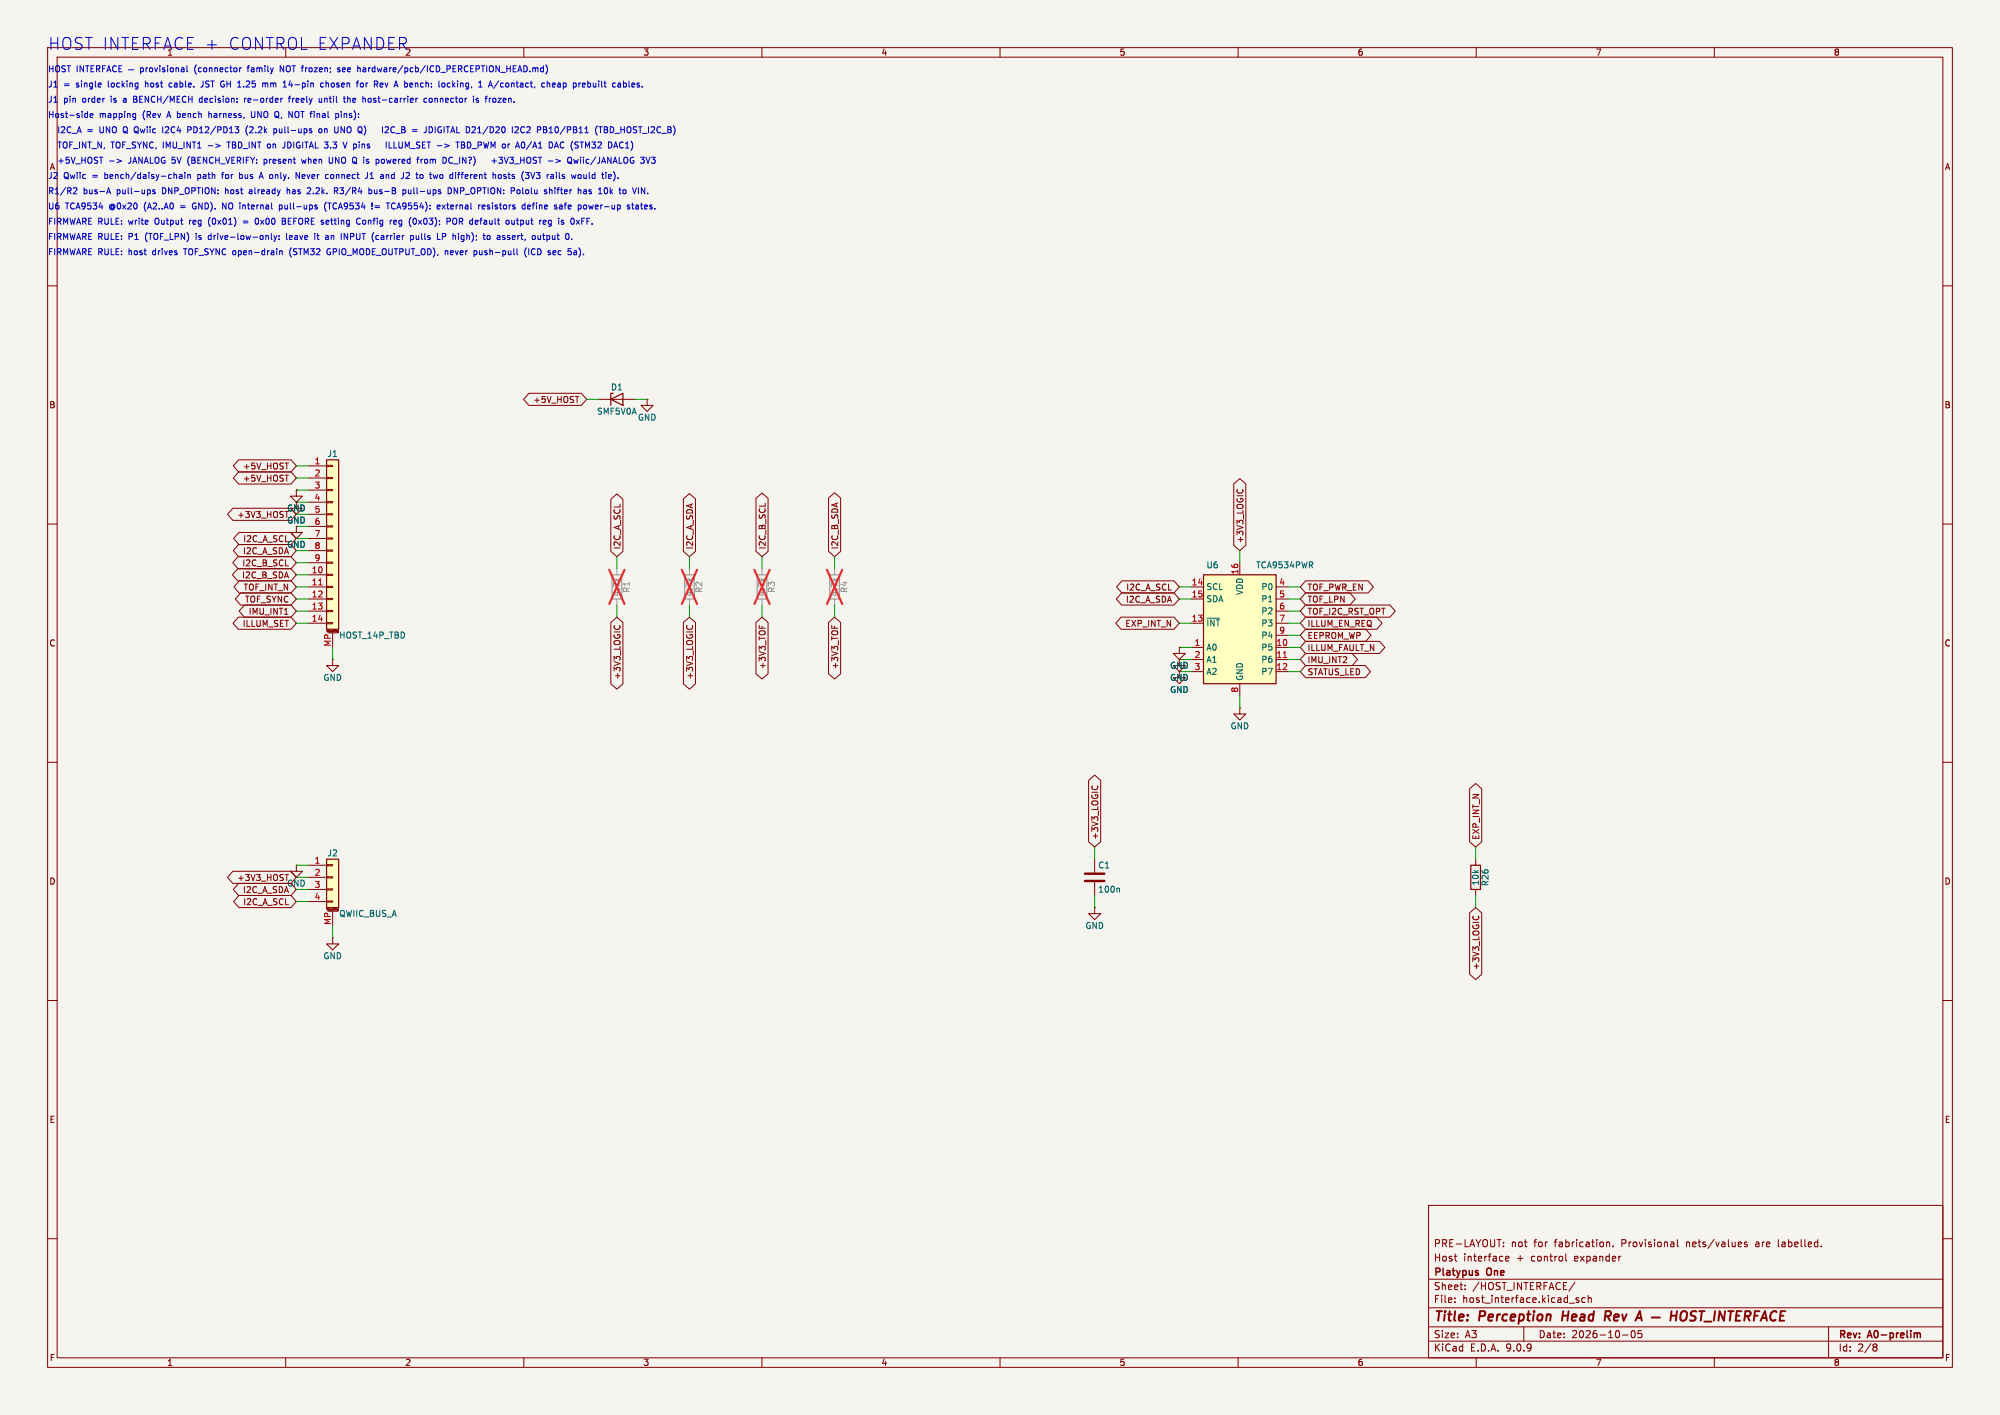
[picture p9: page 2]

HOST INTERFACE + CONTROL EXPANDER

Id: 2/8 Title: Perception Head Rev A þÿ HOST_INTERFACE

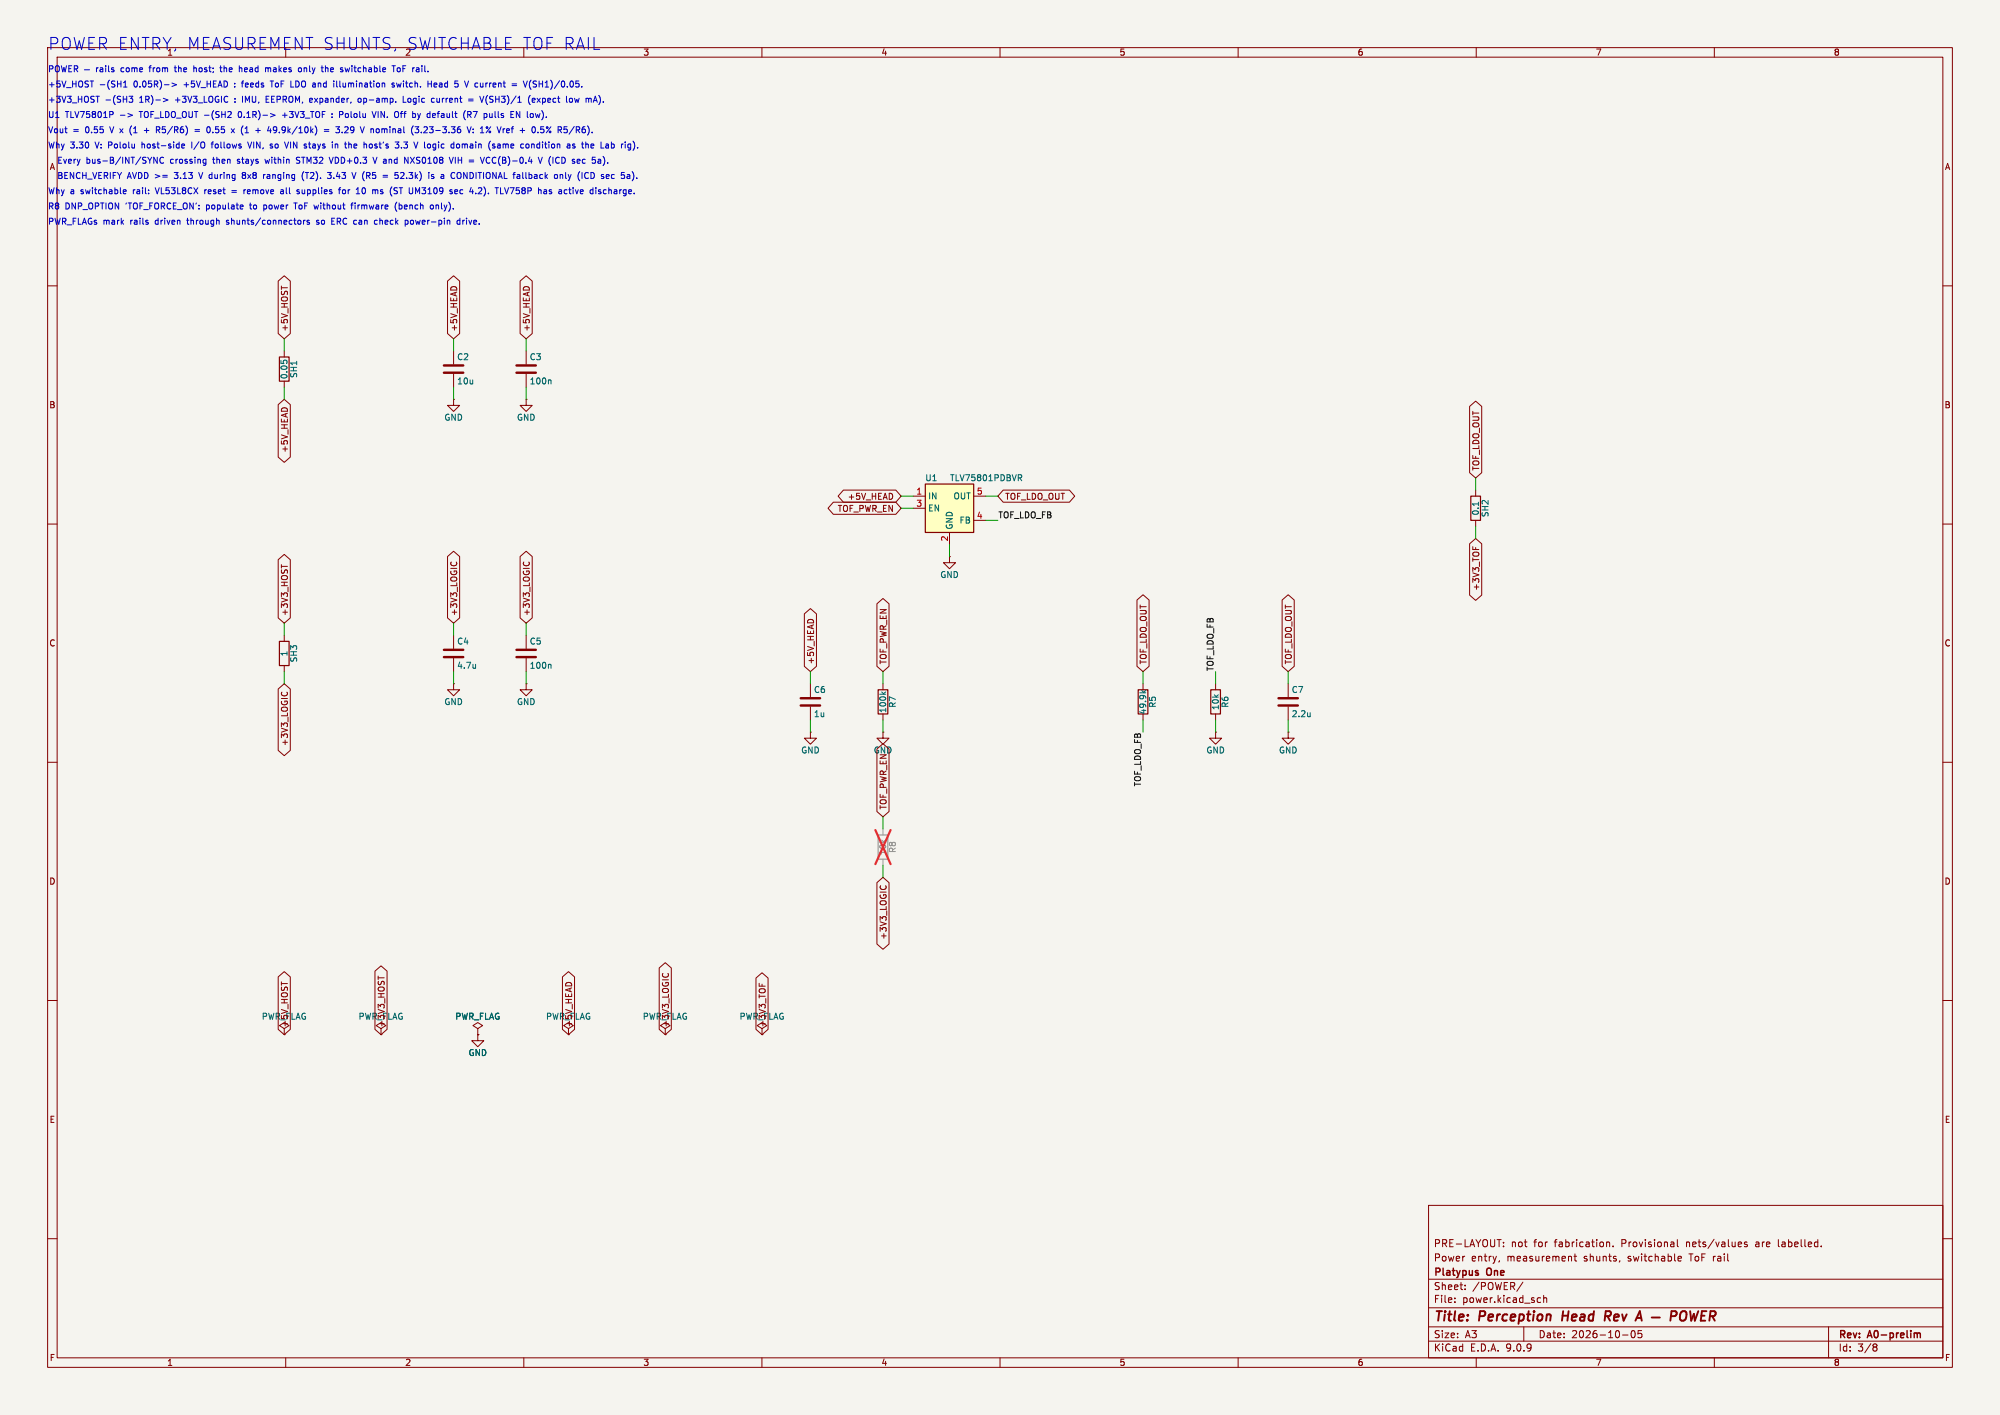
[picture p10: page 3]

POWER ENTRY, MEASUREMENT SHUNTS, SWITCHABLE TOF RAIL

Id: 3/8 Title: Perception Head Rev A þÿ POWER

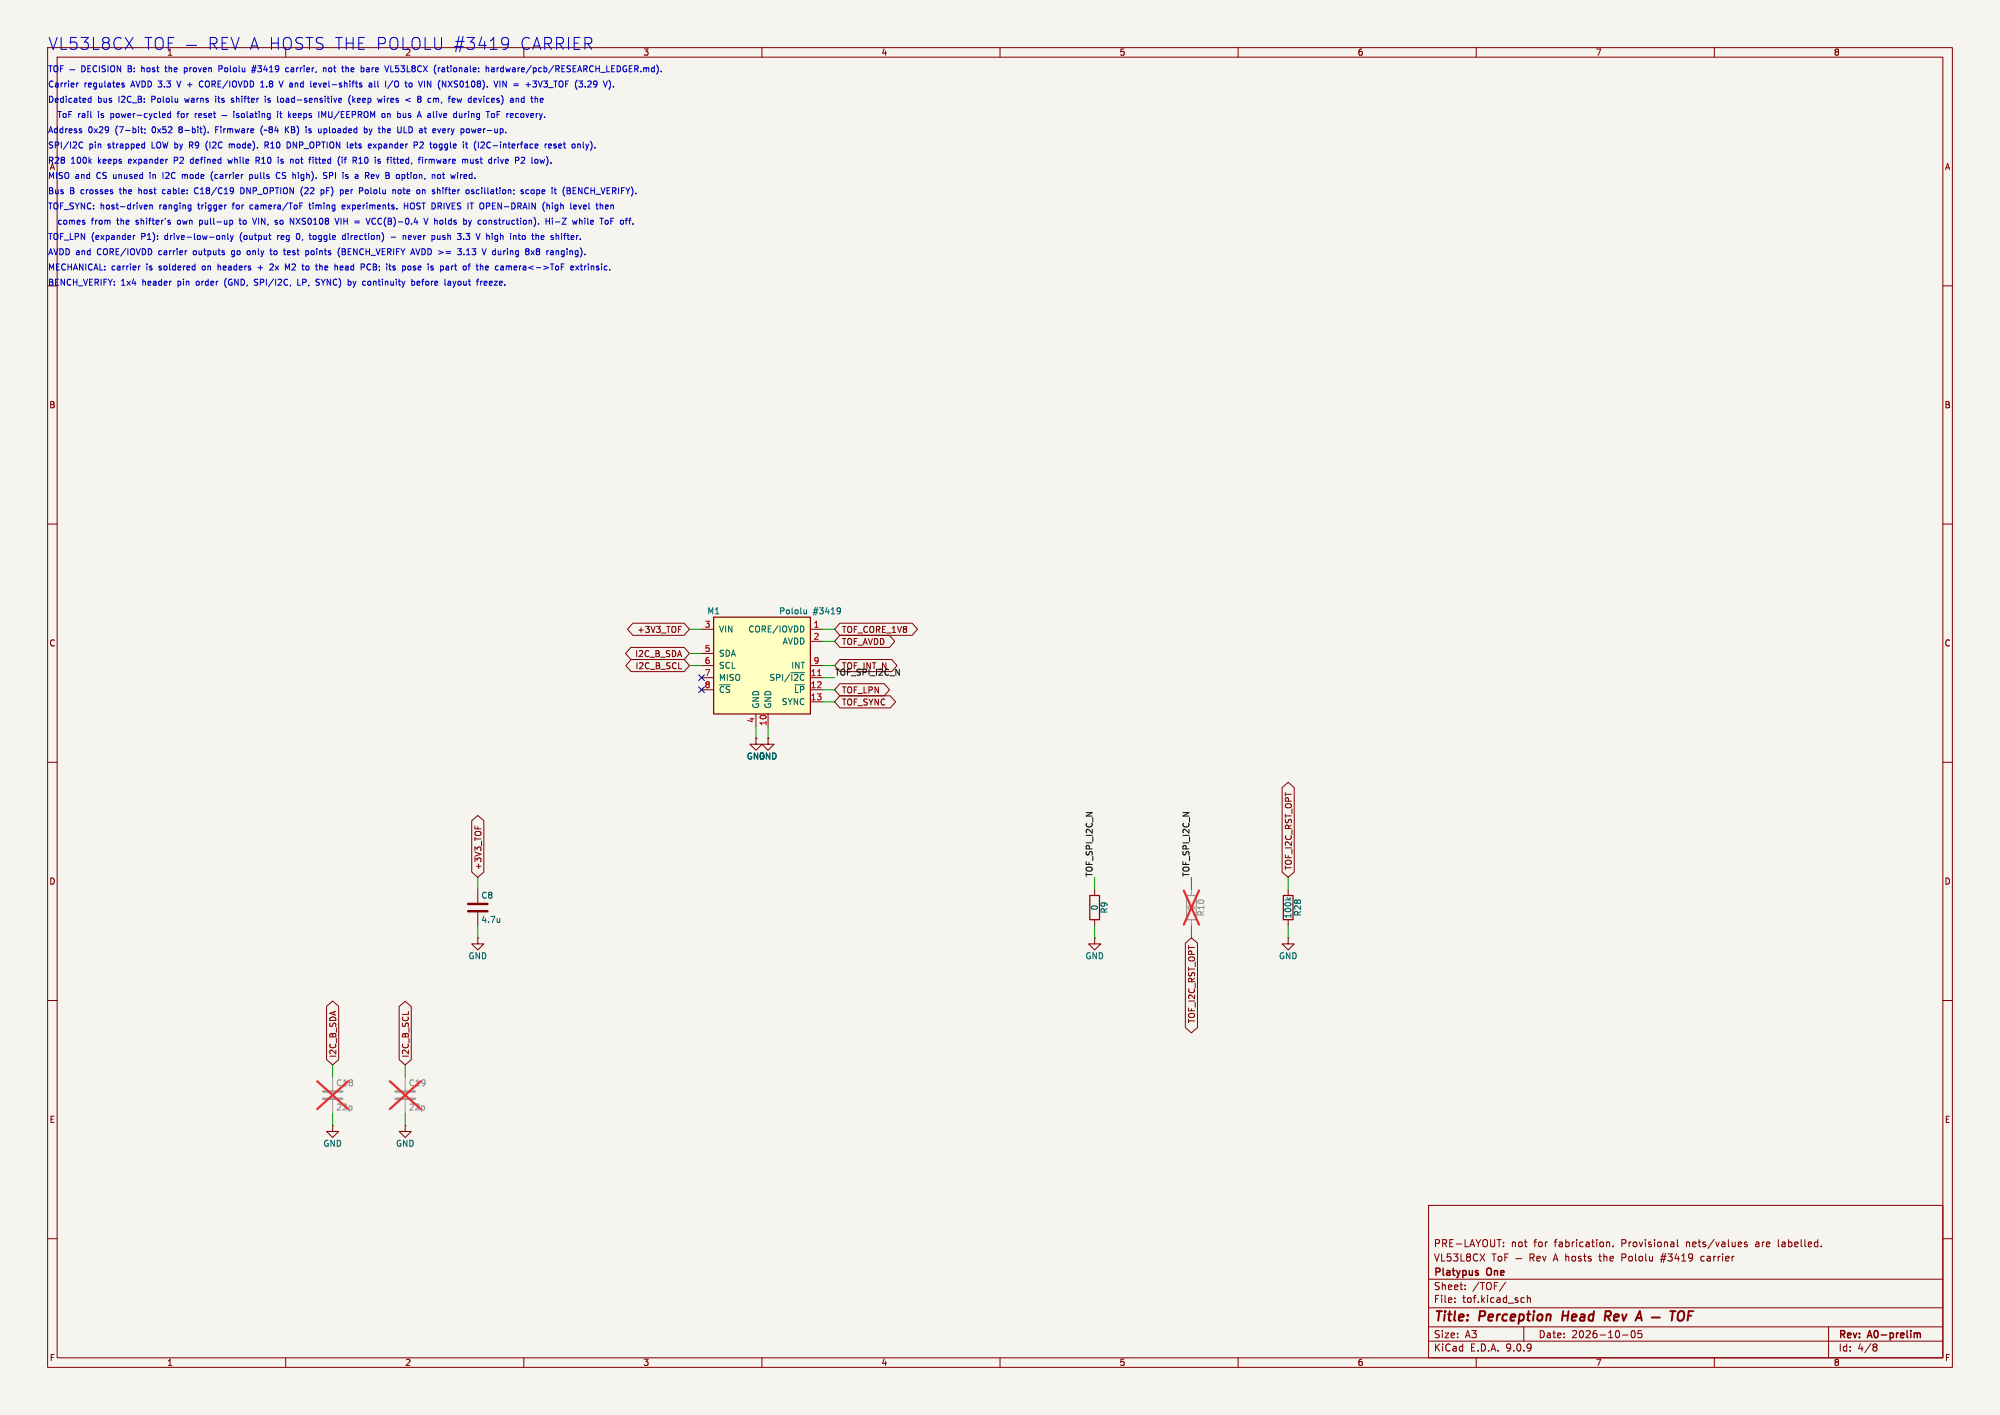
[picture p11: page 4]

VL53L8CX TOF þÿ REV A HOSTS THE POLOLU #3419 CARRIER

4 GND 10 CORE/IOVDD 1 AVDD 2

Id: 4/8 Title: Perception Head Rev A þÿ TOF

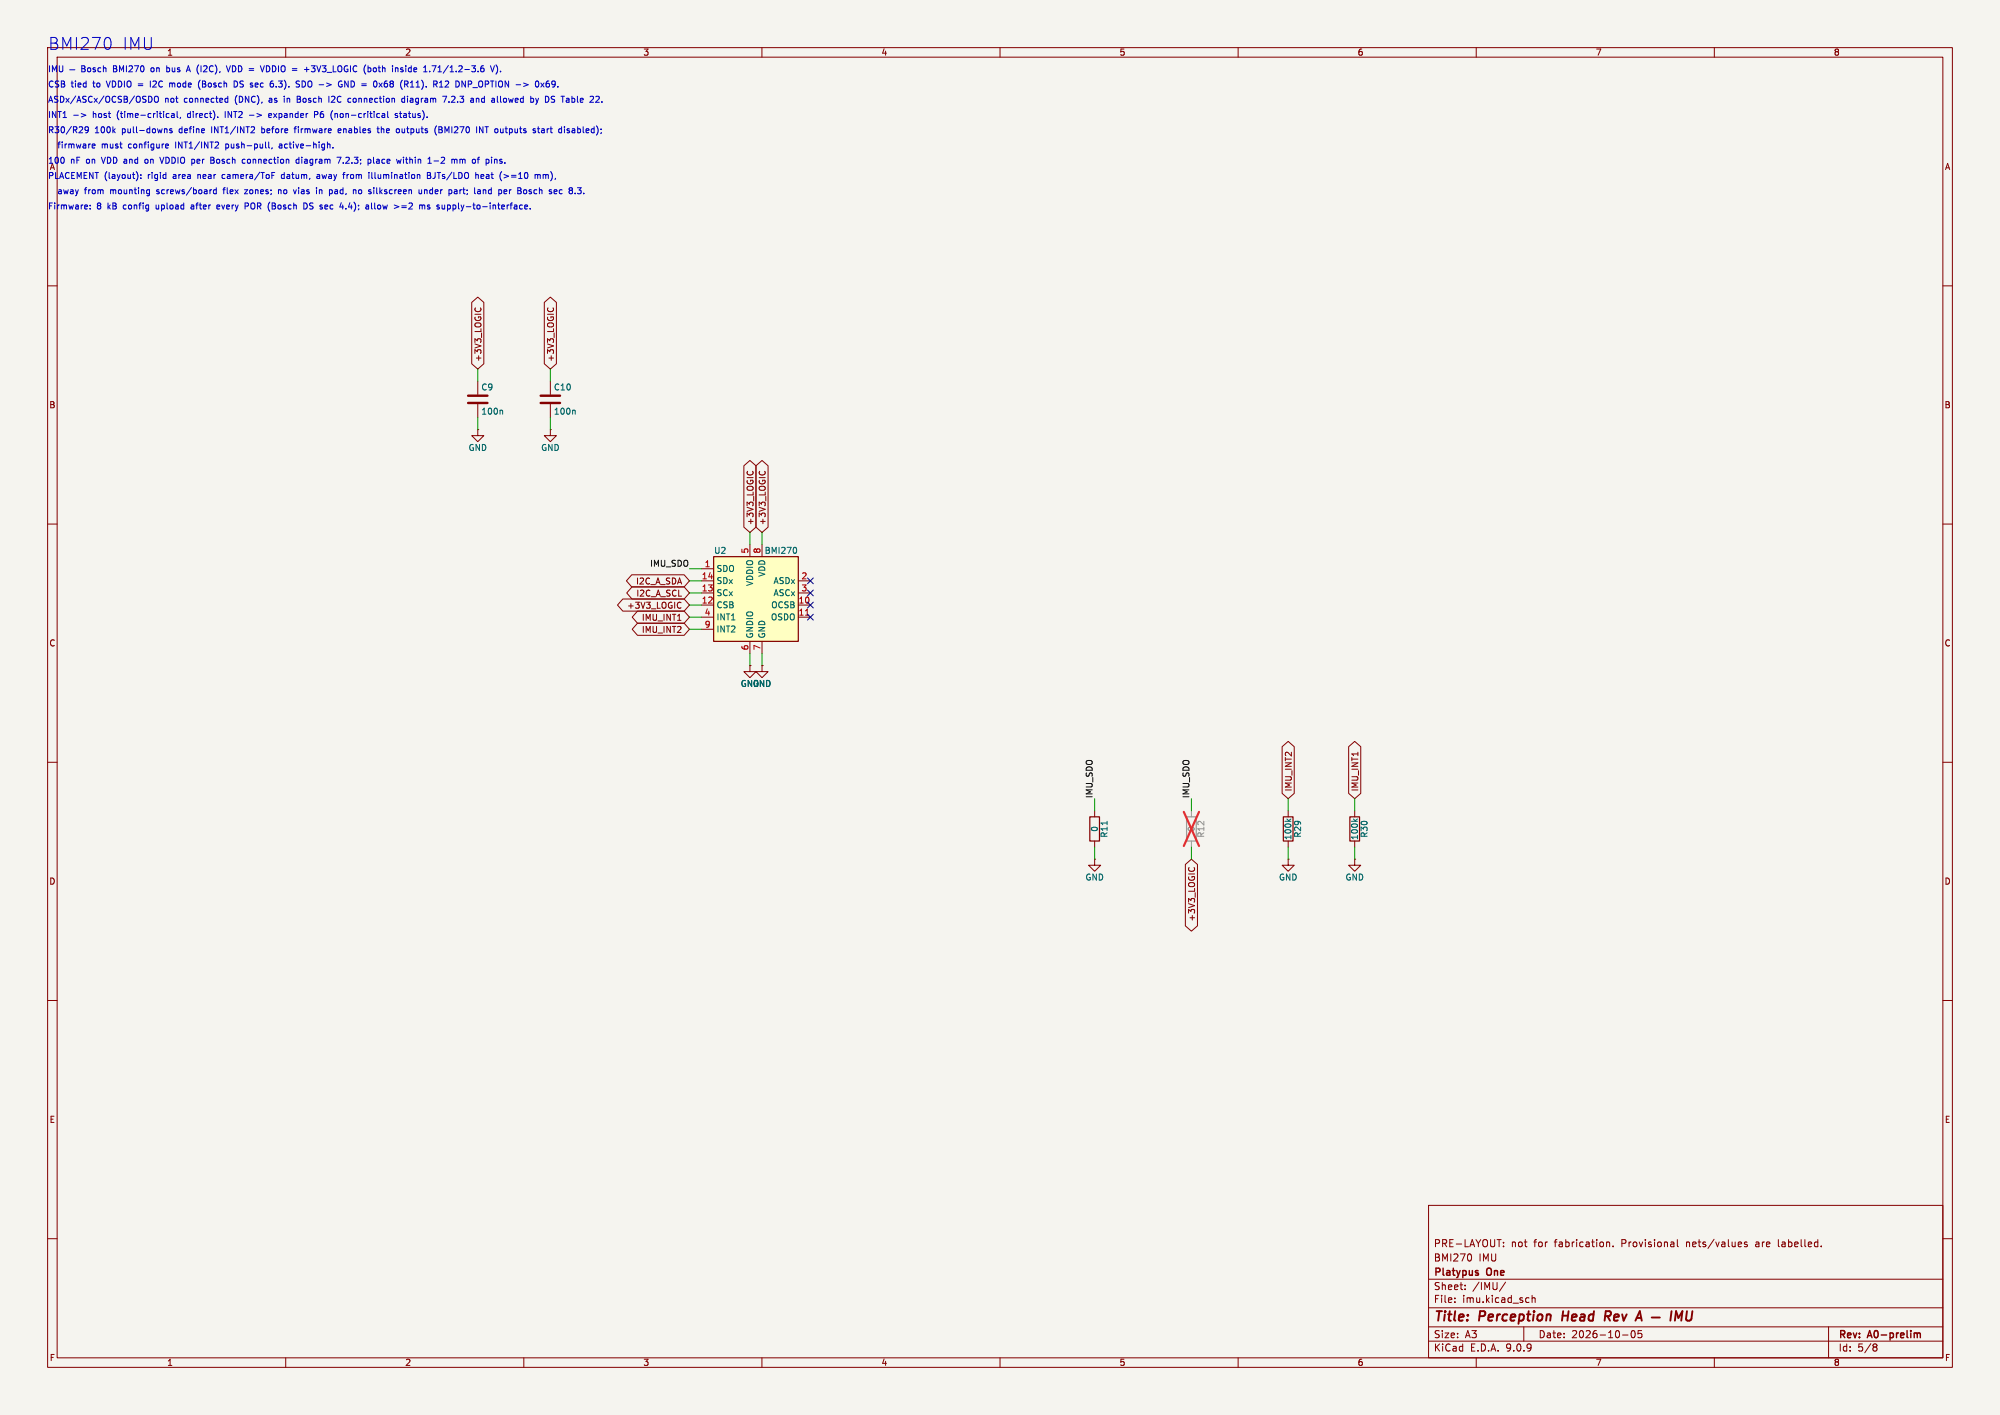
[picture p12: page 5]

7 ASDx 2 ASCx 3 OCSB 10 OSDO 11 U2 BMI270 GND

Id: 5/8 Title: Perception Head Rev A þÿ IMU

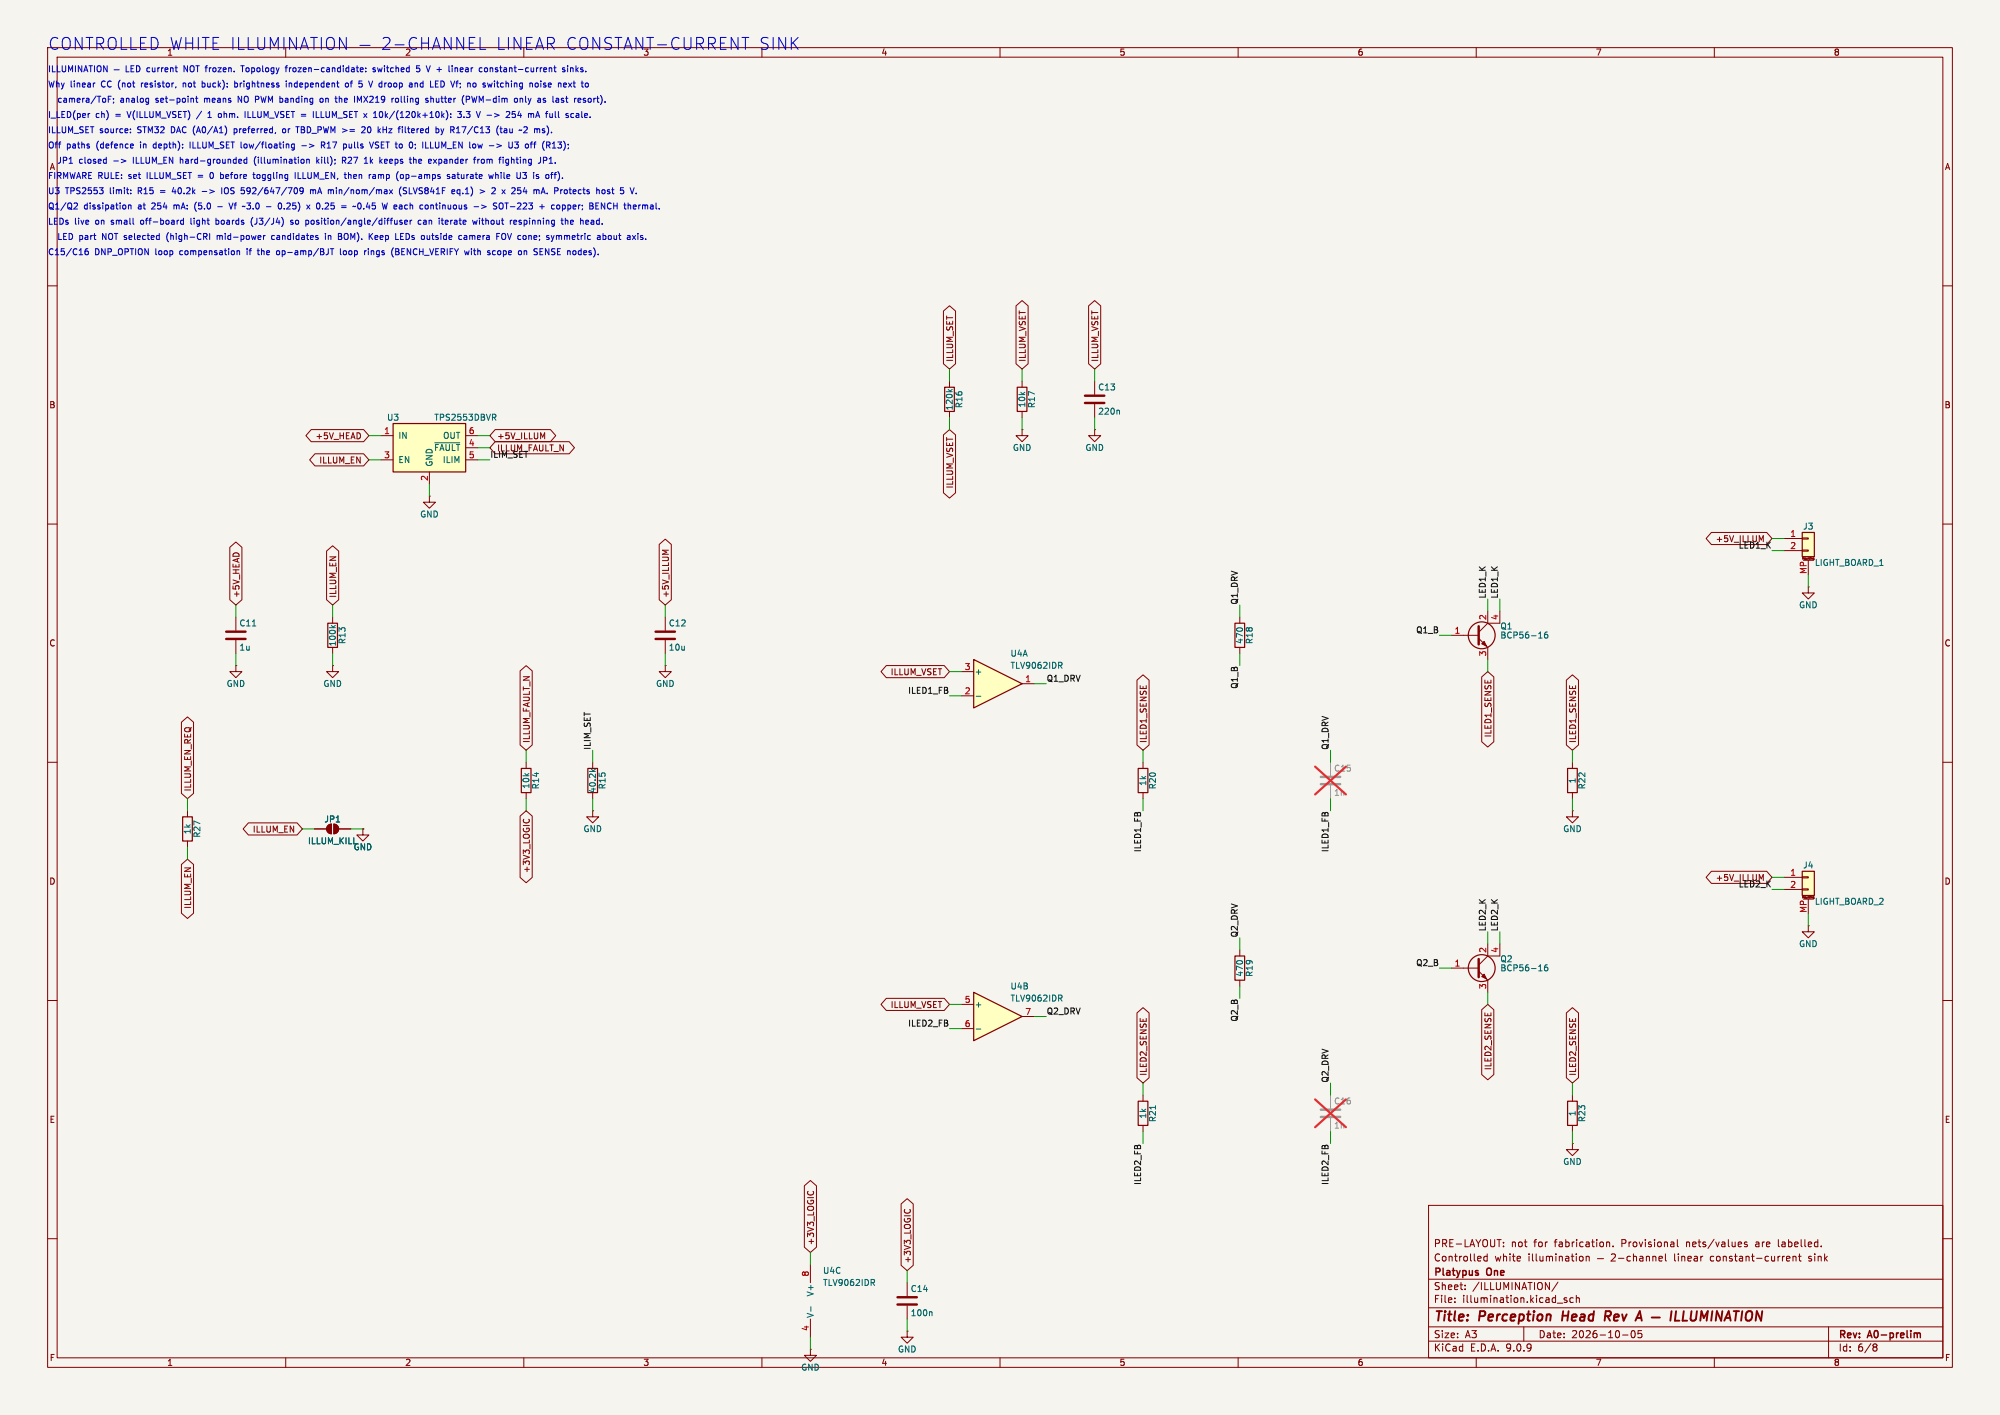
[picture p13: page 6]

Id: 6/8 Title: Perception Head Rev A þÿ ILLUMINATION

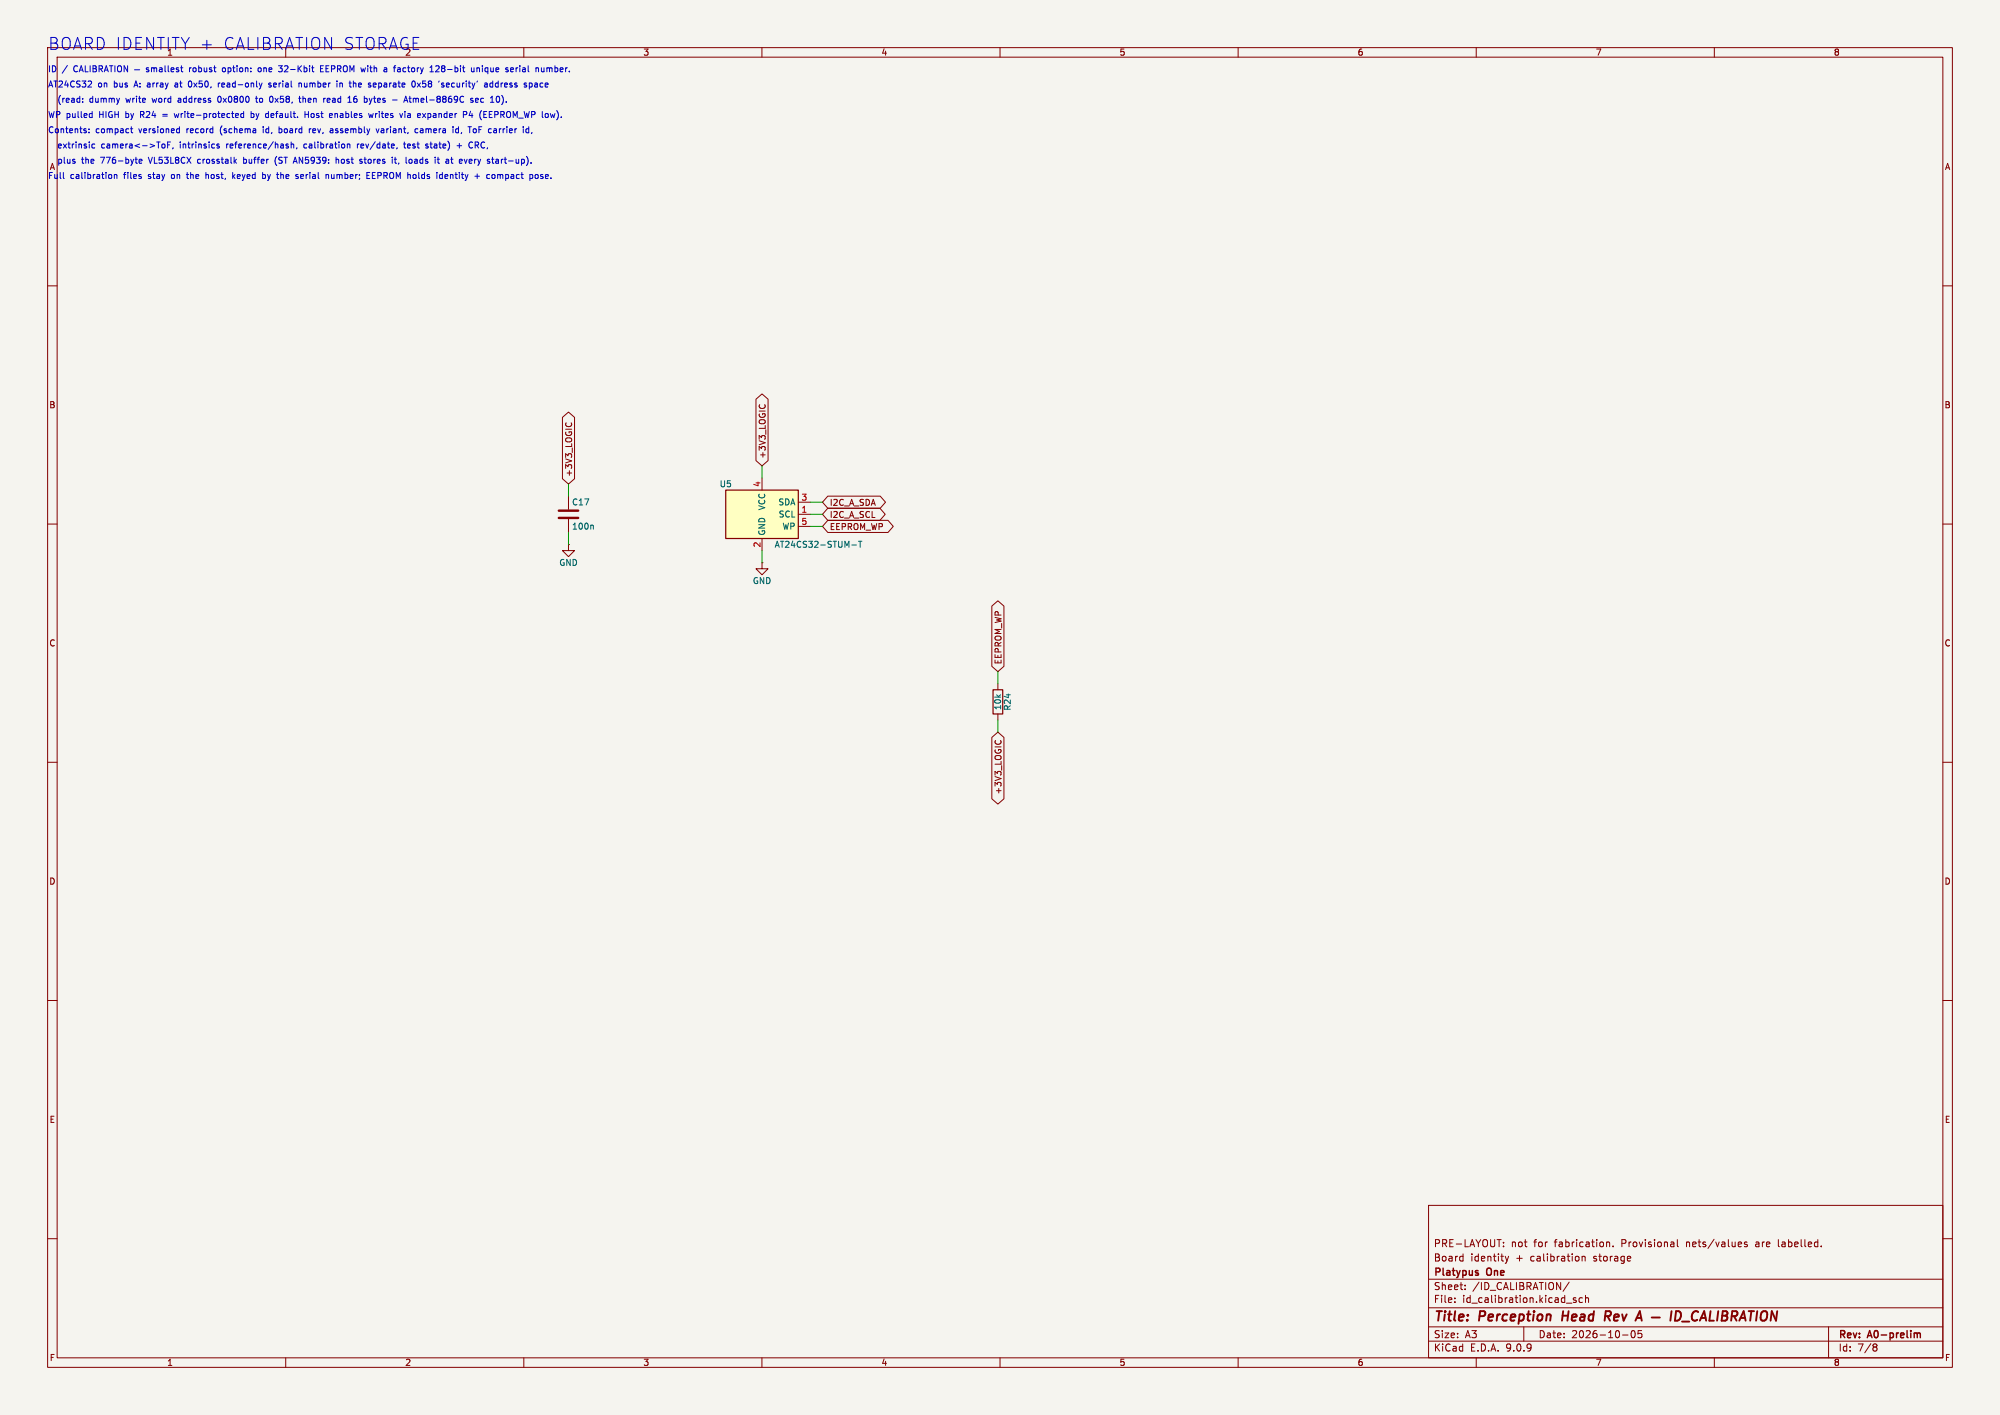
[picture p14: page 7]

2 SDA 3 SCL 1 WP 5 U5 AT24CS32-STUM-T 10k R24 GND

File: id_calibration.kicad_sch Sheet: /ID_CALIBRATION/
Id: 7/8 Title: Perception Head Rev A þÿ ID_CALIBRATION

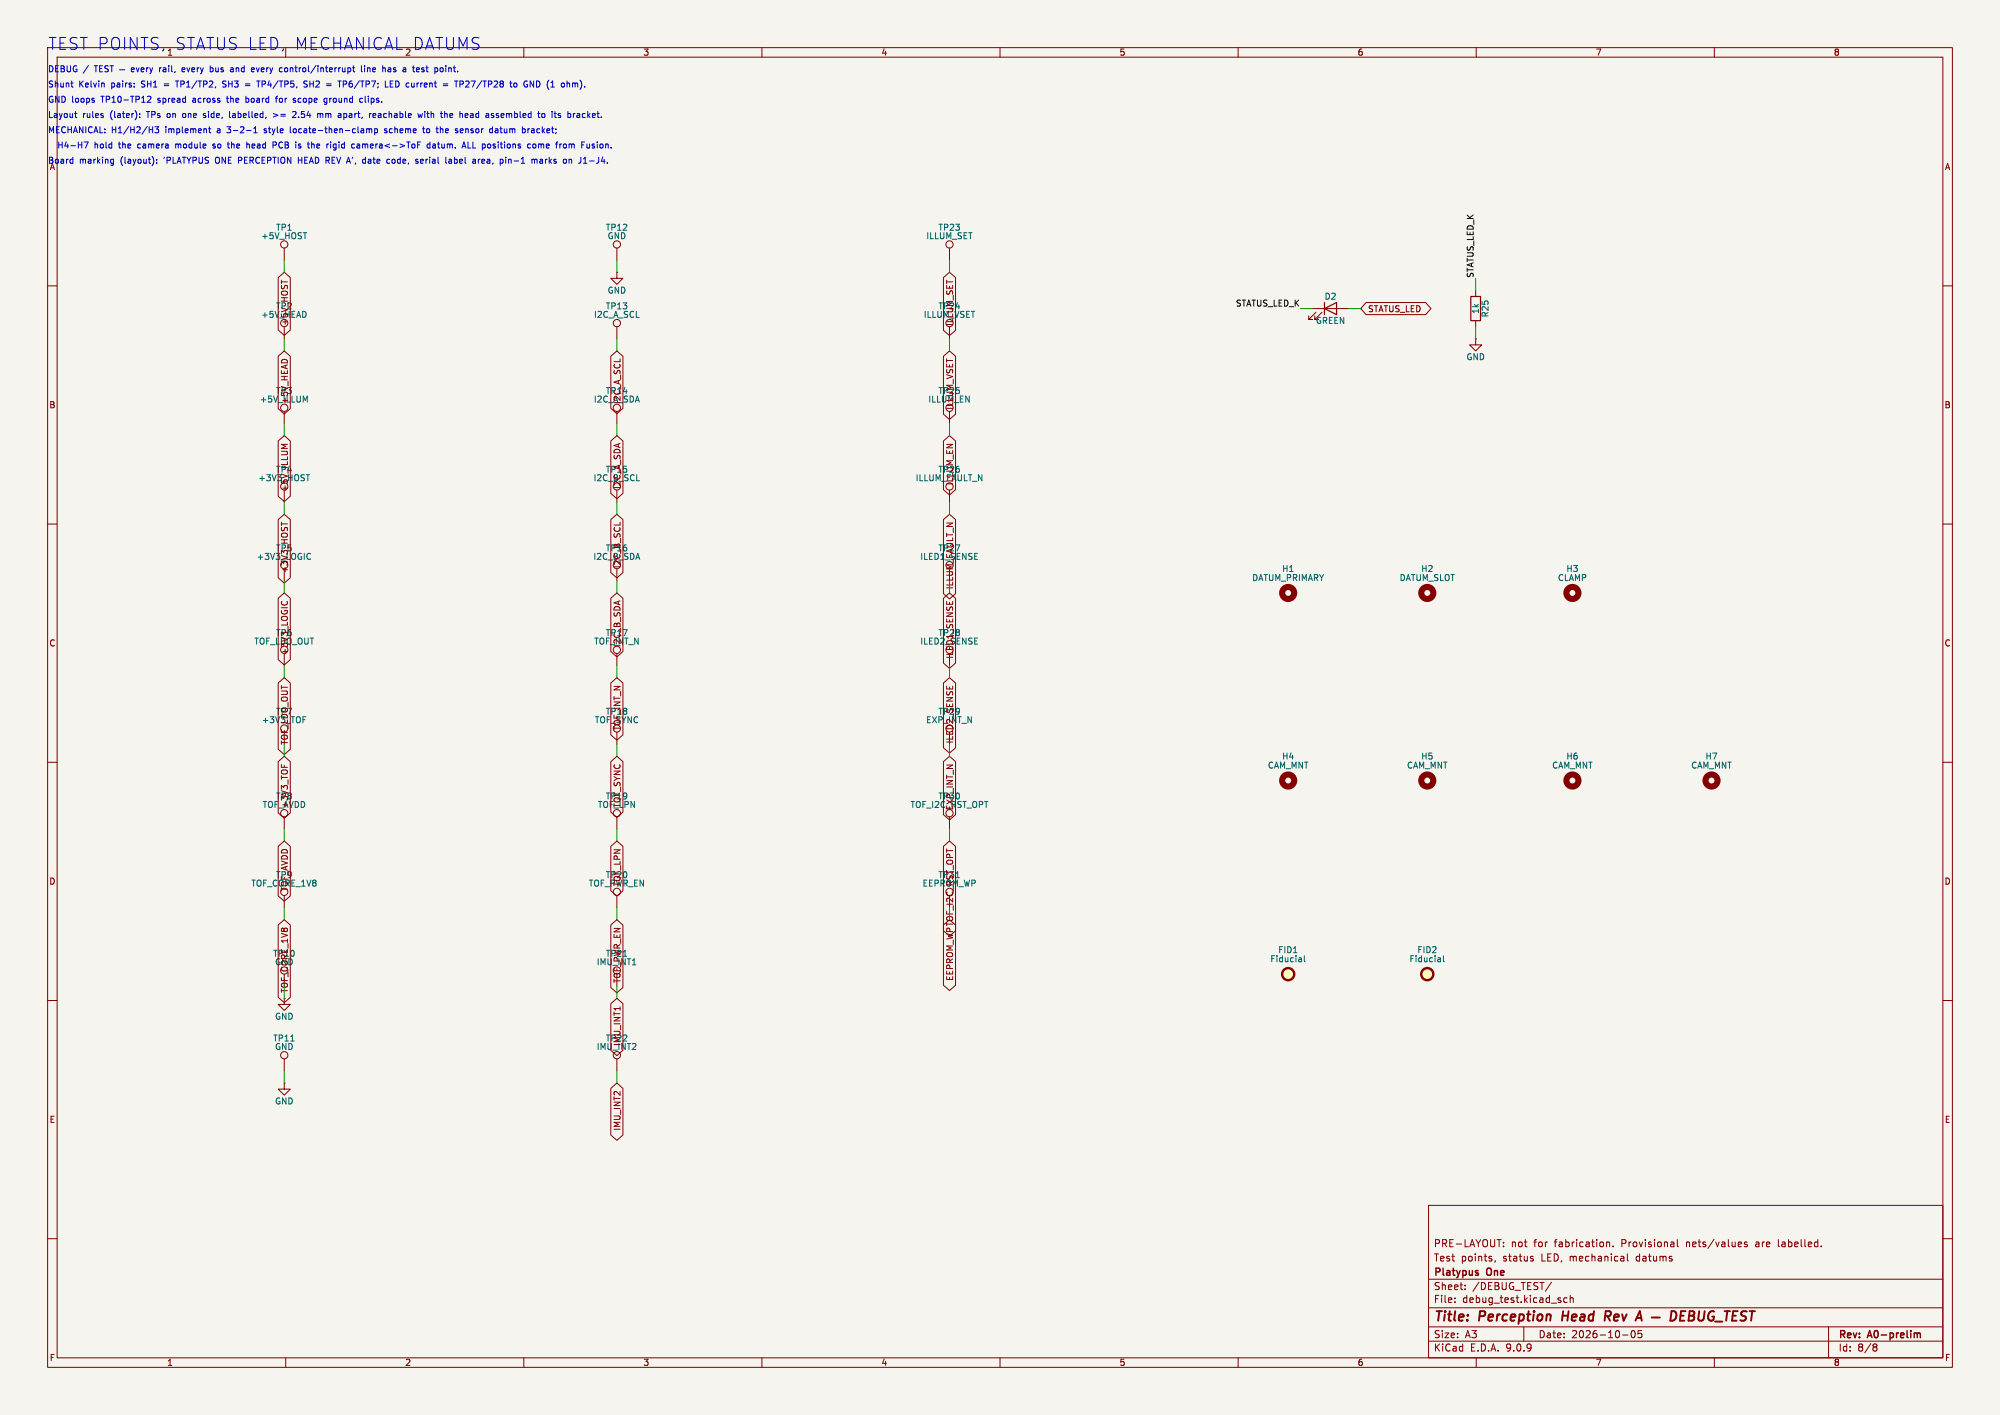
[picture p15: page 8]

STATUS_LED_K TEST POINTS, STATUS LED, MECHANICAL DATUMS

File: debug_test.kicad_sch Sheet: /DEBUG_TEST/
Id: 8/8 Title: Perception Head Rev A þÿ DEBUG_TEST

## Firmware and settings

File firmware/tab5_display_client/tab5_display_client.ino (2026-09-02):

// PlatypusOS display client — M5Stack Tab5 (temporary prototype panel).
//
// The dumb half of docs/protocols/presentation.md: receive pixel tiles over
// USB CDC serial, blit them, report touch. No widget tree, no app knowledge —
// swapping this panel for the final integrated display changes nothing above
// the host's HAL (ADR-0001).
//
// Shares the presentation-link codec verbatim:
//   arduino-cli compile --fqbn m5stack:esp32:m5stack_tab5 firmware/tab5_display_client \
//     --build-property "compiler.cpp.extra_flags=-I<repo>/platform/display/include -std=gnu++2a"
// (Exact FQBN from `arduino-cli board listall` after installing the M5Stack
// core; the codec needs C++20 — the ESP32-P4 toolchain provides it.)
#include <M5Unified.h>

#include <platypus/hal/link/Framing.hpp>

namespace link = platypus::hal::link;

namespace {

constexpr std::uint16_t kProtocolVersion = 1;
constexpr std::uint32_t kMaxPayload = 16384;  // bounds per-frame latency on CDC
constexpr std::uint8_t kCapTouch = 1u << 0;
constexpr std::uint8_t kCapBacklight = 1u << 3;

link::Decoder decoder;
std::uint16_t openFrameId = 0;
bool frameOpen = false;

void sendFrame(std::uint16_t topic, const std::uint8_t* payload, std::size_t count) {
    const auto frame =
        link::encode(topic, {reinterpret_cast<const std::byte*>(payload), count});
    if (frame) Serial.write(reinterpret_cast<const std::uint8_t*>(frame->data()), frame->size());
}

void putU16(std::uint8_t* out, std::uint16_t value) {
    out[0] = static_cast<std::uint8_t>(value & 0xFF);
    out[1] = static_cast<std::uint8_t>(value >> 8);
}

std::uint16_t getU16(const std::byte* data) {
    return static_cast<std::uint16_t>(std::to_integer<std::uint16_t>(data[0]) |
                                      (std::to_integer<std::uint16_t>(data[1]) << 8));
}

void sendHelloReply() {
    std::uint8_t reply[28] = {};
    putU16(reply, kProtocolVersion);
    putU16(reply + 2, static_cast<std::uint16_t>(M5.Display.width()));
    putU16(reply + 4, static_cast<std::uint16_t>(M5.Display.height()));
    reply[6] = 0;  // RGB565 little-endian
    reply[7] = kCapTouch | kCapBacklight;
    reply[8] = static_cast<std::uint8_t>(kMaxPayload & 0xFF);
    reply[9] = static_cast<std::uint8_t>((kMaxPayload >> 8) & 0xFF);
    reply[10] = static_cast<std::uint8_t>((kMaxPayload >> 16) & 0xFF);
    reply[11] = static_cast<std::uint8_t>((kMaxPayload >> 24) & 0xFF);
    const char* name = "m5stack-tab5";
    for (std::size_t i = 0; name[i] != '\0'; ++i) reply[12 + i] = name[i];
    sendFrame(link::topics::kHelloReply, reply, sizeof(reply));
}

void sendAck(std::uint16_t frameId, std::uint8_t status) {
    std::uint8_t ack[3];
    putU16(ack, frameId);
    ack[2] = status;
    sendFrame(link::topics::kFrameAck, ack, sizeof(ack));
}

void handleTile(const link::Message& message) {
    if (message.payload.size() < 12) return;
    const auto* p = message.payload.data();
    const auto frameId = getU16(p);
    if (!frameOpen || frameId != openFrameId) return;  // stale tile: discard
    const auto x = getU16(p + 2);
    const auto y = getU16(p + 4);
    const auto w = getU16(p + 6);
    const auto h = getU16(p + 8);
    const auto encoding = std::to_integer<std::uint8_t>(p[10]);
    if (encoding != 0) return;  // raw only in this client (no RLE16 capability)
    if (x + w > M5.Display.width() || y + h > M5.Display.height() ||
        message.payload.size() != 12u + static_cast<std::size_t>(w) * h * 2u) {
        sendAck(frameId, 1);  // protocol error: drop the frame
        frameOpen = false;
        return;
    }
    // RGB565 little-endian wire order; verify byte order on the bench and
    // flip setSwapBytes if colors come out wrong (checklist step 5).
    M5.Display.setSwapBytes(false);
    M5.Display.pushImage(x, y, w, h, reinterpret_cast<const std::uint16_t*>(p + 12));
}

void handleMessage(const link::Message& message) {
    const auto* p = message.payload.data();
    switch (message.topic) {
        case link::topics::kHello:
            sendHelloReply();
            break;
        case link::topics::kPing:
            sendFrame(link::topics::kPong,
                      reinterpret_cast<const std::uint8_t*>(p), message.payload.size());
            break;
        case link::topics::kFrameBegin:
            if (message.payload.size() >= 4) {
                openFrameId = getU16(p);
                frameOpen = true;
            }
            break;
        case link::topics::kTile:
            handleTile(message);
            break;
        case link::topics::kFrameEnd:
            if (frameOpen && message.payload.size() >= 2 && getU16(p) == openFrameId) {
                sendAck(openFrameId, 0);
                frameOpen = false;
            }
            break;
        case link::topics::kBacklight:
            if (message.payload.size() >= 2)
                M5.Display.setBrightness(static_cast<std::uint8_t>(getU16(p) >> 8));
            break;
        default:
            break;  // unknown topics ignored, never errors
    }
}

void pumpTouch() {
    M5.update();
    const auto detail = M5.Touch.getDetail();
    std::uint8_t event[5];
    if (detail.wasPressed()) {
        event[0] = 0;  // Down
    } else if (detail.isPressed() && detail.wasDragged()) {
        event[0] = 1;  // Move
    } else if (detail.wasReleased()) {
        event[0] = 2;  // Up
    } else {
        return;
    }
    putU16(event + 1, static_cast<std::uint16_t>(detail.x));
    putU16(event + 3, static_cast<std::uint16_t>(detail.y));
    sendFrame(link::topics::kTouch, event, sizeof(event));
}

}  // namespace

void setup() {
    auto config = M5.config();
    M5.begin(config);
    M5.Display.fillScreen(TFT_BLACK);
    M5.Display.setTextSize(2);
    M5.Display.drawString("PlatypusOS link: waiting for host...", 16, 16);
    Serial.begin(115200);
}

void loop() {
    while (Serial.available() > 0) {
        if (auto message =
                decoder.feed(std::byte{static_cast<std::uint8_t>(Serial.read())}))
            handleMessage(*message);
    }
    pumpTouch();
}

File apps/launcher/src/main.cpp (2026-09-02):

// PlatypusOS — composition root.
//
// This is the ONLY translation unit that knows concrete types. It builds the
// board, wires services, registers apps, and runs the shell loop. Everything
// below this file speaks only in interfaces.
#include "HostSimBoard.hpp"
#include "LauncherApp.hpp"

#include <platypus/appfw/AppContext.hpp>
#include <platypus/appfw/AppRegistry.hpp>
#include <platypus/appfw/EventQueue.hpp>
#include <platypus/apps/EngineeringScoutApp.hpp>
#include <platypus/apps/SettingsApp.hpp>
#include <platypus/filesystem/ProjectStore.hpp>
#include <platypus/renderer/Renderer.hpp>

#ifndef _WIN32
#include "linked/LinkedDisplay.hpp"
#include "linked/SerialTransport.hpp"
#include "unoq/UnoQBoard.hpp"
#endif

#include <atomic>
#include <charconv>
#include <chrono>
#include <csignal>
#include <cstdint>
#include <cstdio>
#include <memory>
#include <string>
#include <string_view>
#include <system_error>  // std::errc, compared against from_chars_result::ec
#include <thread>

namespace {
std::atomic<bool> g_running{true};  // signal-handler flag; sole permitted "global"
void handleSignal(int) {
    g_running = false;
}

bool parseDimension(std::string_view text, std::uint16_t& out) {
    unsigned value = 0;
    const auto* const last = text.data() + text.size();
    const auto [end, ec] = std::from_chars(text.data(), last, value);
    if (ec != std::errc{} || end != last) return false;
    if (value == 0 || value > 4096) return false;  // sanity bounds, not a policy
    out = static_cast<std::uint16_t>(value);
    return true;
}

/// Parses "WIDTHxHEIGHT" (e.g. "800x480"), returning `fallback` unchanged if
/// the spec is malformed. ADR-0001 keeps the panel dynamic, so the simulated
/// geometry is a runtime choice rather than a compiled-in constant.
platypus::hal::DisplayInfo parseGeometry(std::string_view spec,
                                         platypus::hal::DisplayInfo fallback) {
    const auto separator = spec.find('x');
    if (separator == std::string_view::npos) return fallback;

    auto parsed = fallback;
    if (!parseDimension(spec.substr(0, separator), parsed.width) ||
        !parseDimension(spec.substr(separator + 1), parsed.height))
        return fallback;
    return parsed;
}

/// Frame sink for headless runs (no window backend, no linked display): the
/// renderer needs a real IDisplay, and boards legitimately report the display
/// as absent. Accepts frames, produces no events.
class HeadlessDisplay final : public platypus::hal::IDisplay {
   public:
    explicit HeadlessDisplay(platypus::hal::DisplayInfo info) : info_(info) {}
    platypus::hal::DisplayInfo info() const noexcept override { return info_; }
    platypus::hal::Status setBacklight(float) override { return {}; }
    platypus::hal::Status present(std::span<const std::byte>) override { return {}; }
    platypus::hal::Status onTouch(std::function<void(const platypus::hal::TouchEvent&)>) override {
        return {};
    }
    platypus::hal::Status onButton(
        std::function<void(const platypus::hal::ButtonEvent&)>) override {
        return {};
    }

   private:
    platypus::hal::DisplayInfo info_;
};
}  // namespace

int main(int argc, char** argv) {
    std::signal(SIGINT, handleSignal);
    std::signal(SIGTERM, handleSignal);

    // --- Hardware -----------------------------------------------------------
    // --board hostsim (default) | unoq (POSIX targets only).
    // --display-link PATH connects a LinkedDisplay over serial (ADR-0001
    //   prototype path; default /dev/ttyACM0) when the board is unoq.
    // --geometry WxH sizes the simulated/headless panel. Nothing downstream
    //   sees these values: apps and the renderer read IDisplay::info().
    auto geometry = platypus::sim::kDefaultSimGeometry;
    std::string boardChoice = "hostsim";
    std::string linkDevice = "/dev/ttyACM0";
    for (int i = 1; i + 1 < argc; ++i) {
        const std::string_view arg(argv[i]);
        if (arg == "--geometry") geometry = parseGeometry(argv[i + 1], geometry);
        if (arg == "--board") boardChoice = argv[i + 1];
        if (arg == "--display-link") linkDevice = argv[i + 1];
    }
    // Declared before the board so the queue outlives every registered driver
    // callback during shutdown.
    platypus::appfw::EventQueue eventQueue;

    std::unique_ptr<platypus::hal::IBoard> board;
#ifndef _WIN32
    if (boardChoice == "unoq") {
        platypus::unoq::UnoQBoard::Config config;
        auto transport = std::make_unique<platypus::linked::SerialTransport>(linkDevice);
        if (transport->open().ok()) {
            auto display = std::make_shared<platypus::linked::LinkedDisplay>(std::move(transport));
            if (display->connect().ok()) {
                std::printf("linked display: %ux%u via %s\n", display->info().width,
                            display->info().height, linkDevice.c_str());
                config.display = std::move(display);
            } else {
                std::fprintf(stderr, "linked display on %s: no session; running headless\n",
                             linkDevice.c_str());
            }
        } else {
            std::fprintf(stderr, "linked display: cannot open %s; running headless\n",
                         linkDevice.c_str());
        }
        board = std::make_unique<platypus::unoq::UnoQBoard>(std::move(config));
    }
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

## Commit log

2026-08-10 Initial commit: PlatypusOS platform, UNO Q bring-up, contest docs
    - Layered C++20 architecture (apps -> services -> platform HAL)
    - App framework (IApp/AppContext/AppRegistry), launcher + settings apps
    - Win32 sim display, HostSimBoard, UnoQBoard + MCU bridge (framing + serial)
    - Unit tests (registry, renderer, MCU framing) - all passing under MSVC
    - AU 2027 contest snapshot, BOM, test checklists, acquisition roadmap,
    industrial design notes + media references
    [arduino_q.step]
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2026-08-25 docs(hardware): display decision comparison + merged BOM rev B
    - DISPLAY_COMPARISON.md: consolidates 3.2" SPI / 4.3" RGB+bridge /
    DSI panel / HDMI-fixture options; key finding: UNO Q's ANX7625 gives
    USB-C DP alt-mode video, muxed with a MIPI-DSI connector, so DSI is
    the handheld-viable product path and a plain monitor is the fastest
    prototyping fixture
    - BOM.md rev B: merges envelope BOM, keeps alternates (camera, ToF,
    IMU, display) pending Matthew's analysis; radar deferred to V2
    - BOM_v0_1.md now scoped to packaging envelopes, points to canonical BOM
2026-08-25 docs(adr): establish ADR process and record dynamic display decision
    The repository accumulated four conflicting display directions (3.2" SPI,
    5-7" LCD, 4.3" 800x480 RGB, linked Tab5) with no decision between them,
    while the code hardcoded 320x240.
    ADR-0001 records the owner's decision: the display target stays deliberately
    dynamic. Geometry is a runtime property read from IDisplay::info(), and
    prototyping runs against a linked external display until the production panel
    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
2026-08-25 docs(protocols): spec the presentation link protocol v0.1
    Specifies the transport-independent seam between PlatypusOS and an external
    display client, so the prototype panel never leaks into the UI.
    The seam is hal::IDisplay itself: the linked display is a driver, and apps,
    renderer, and layout code stay unaware the panel is remote. Geometry is
    negotiated in HelloReply rather than assumed, which is the runtime half of
    ADR-0001.
    Written before the code deliberately - the first bring-up sprint gets a
    contract instead of a serial link invented at the bench.
    Two findings the bandwidth analysis forced out:
    - A full 800x480 RGB565 frame is 768 kB; USB CDC sustains roughly one per
    second. Dirt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
2026-08-25 feat(sim): make simulated display geometry a runtime choice
    The renderer already sized its framebuffer from hal::DisplayInfo, but both
    simulator displays hardcoded 320x240, so the one resolution the code could
    actually run was the one least likely to ship. ADR-0001 makes the panel
    deliberately dynamic; this is the code half of that decision.
    - HostSimBoard and Win32SimDisplay take geometry by injection, defaulting to
    320x240 via kDefaultSimGeometry.
    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
2026-08-25 docs(contest): prepare the Sep 7 hardware application
    The application window was extended from Aug 23 to Sep 7, 2026, so Phase 0 is
    live again. Adds a working checklist carrying everything that can be prepared
    in advance: project page copy, story beats, a paste-ready BOM excerpt with the
    two mandatory lines (UNO Q and Fusion), draft form answers, and a modelling
    brief for the .f3d.
    Submission stays with the owner - nothing here attempts a web submission, and
    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
2026-08-25 docs: add STATUS.md and fold this session's decisions into the roadmap
    STATUS.md is the rolling answer to "where is this actually" - milestones,
    open decisions with what each one blocks, known gaps, and next actions split
    by who can do them. It also carries a verification table recording that the
    sim geometry change is committed uncompiled, so that debt is visible rather
    than implied by a commit message nobody re-reads.
    Roadmap changes follow from ADR-0001 and the presentation link spec:
    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
2026-08-25 fix(sim): include <system_error> for std::errc
    from_chars_result::ec is std::errc, which is formally declared in
    <system_error>. Implementations generally expose it through <charconv>, but
    relying on that is a portability bet with no upside - and the repo's own rule
    is include what you use.
    Still uncompiled here; see STATUS.md verification table.
    [main.cpp]
2026-08-25 docs(adr): ADR-0002 — DSI panel is the production display; verify sim geometry
    - ADR-0002 records the owner's decision: 4.3-5in MIPI-DSI 800x480 capacitive,
    native Linux drive; ESP32-S3 bridge demoted to fallback (gate Sep 30);
    3.2in SPI kept as descope net. Refines ADR-0001, does not supersede it.
    - STATUS.md: verification table cleared - sim geometry change builds clean,
    all tests pass, 800x480 smoke-tested on the MSVC machine. Adds TARS task:
    DSI panel candidates research -> docs/hardware/DSI_PANEL_CANDIDATES.md
    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
2026-08-30 Implement Engineering Observation contract v0.1 (C++ + serialization + tests) (#10)
    * feat(observation): implement Engineering Observation contract v0.1
    Implements docs/architecture/ENGINEERING_OBSERVATION_CONTRACT.md as a new
    services/observation library (issue #9 groundwork). Types mirror the
    contract record; observed/derived/inferred/unresolved stay structurally
    distinct. Includes:
    - Minimal dependency-free JSON layer (insertion-ordered objects, strict
    RFC 8259 parser with \u escapes incl. surrogate pairs, duplicate-key
    rejection, depth cap, shortest-round-trip numbers)
    - toJson/fromJson: contract field order, deterministic byte-stable output
    (records diff cleanly in git), unknown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
2026-08-30 feat(scout): camera -> artifact -> observation capture vertical slice
    First physical-evidence path through PlatypusOS (issue #9, DigiKey chunk 2):
    - platform/camera/src/v4l2: V4l2Camera implementing ICamera for UVC
    devices on the UNO Q Linux side (mmap ring, EINTR-safe ioctls, RAII,
    bounded waits, explicit errors). Linux-only target; NOT COMPILED here
    (Windows dev machine) - needs UNO Q/Linux verification.
    - platform/camera/include/platypus/hal/testing: deterministic FakeCamera
    (pure-function fixture frame, failure injection) keeps host-first dev.
    - services/observation/CaptureService: frame -> saved image + validated
    EngineeringObservation JSON in observations/<id>/. All-or-nothi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
    [main.cpp]
2026-08-30 docs(contest): verify live contest dates; correct repo visibility note
    - Recipients announcement moved Sep 18 -> Sep 25, 2026 (live page, 2026-08-30);
    Sep 7 application close and Dec 20 submission close confirmed unchanged.
    - Checklist section 1 verification boxes checked with findings.
    - STATUS: repository is currently private (renamed Matthewjg95/PlatypusOne);
    LICENSE + go-public still required before the Hackster link.
2026-08-30 docs: re-anchor roadmap to Sep 25 announcement; record local MSVC verification
    - ACQUISITION_ROADMAP: recipients announcement verified moved Sep 18 -> Sep 25
    (live page, 2026-08-30); parts order and bring-up re-dated, phase headings
    and risk table updated; bring-up now overlaps the Oct 19 PCB spin-1 order.
    - STATUS: host build + tests verified on the new dev machine (VS 2022 Build
    Tools / MSVC 14.44 / CMake 4.4.3, fresh configure, all tests pass); Host CI
    is now the primary build signal.
2026-08-31 feat(vision): Scout analyzer - calibration + deterministic measurement
    MVP build-order step 3 (DIGIKEY_ENGINEERING_SCOUT_MVP.md), host-side and
    dependency-free: Otsu binarization, 4-connected components, square-reference
    calibration (side = sqrt(area), tolerant of small rotations), principal-axis
    subject extents in mm via second central moments.
    Evidence emission keeps the contract honest: pixel facts are OBSERVED, mm
    values are DERIVED with provenance chains to the observed claims and source
    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
2026-08-31 feat(ui): real 5x7 bitmap font + Engineering Scout result card (MVP step 5)
    renderer: hand-authored 5x7 column-encoded font (printable ASCII, hollow-box
    replacement glyph), drawText integer scaling, textWidth/textHeight metrics.
    Visually verified via the new tools/ui_preview --font-specimen render.
    apps/engineering_scout: single-card result UI. drawObservationCard is a pure
    function of record + renderer geometry: headline measurement, inferred
    identity with confidence bar, then OBSERVED / DERIVED / INFERRED / UNRESOLVED
    sections each in a dedicated color (the contract honesty rules as layout),
    plus the first NEXT recommendation. App shell loads the newest observation,
    redraws only when dirt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
    [main.cpp]
2026-08-31 feat(validation): 21-case Scout battery + measurement/matching fixes it caught
    tools/scout_validation: deterministic synthetic ground-truth battery (7 bolts,
    6 nuts at varied rotations, 2 washers, 4 intentional failure refusals, 2
    honest-unknown cases) run through the real analyzer + classifier; markdown
    report committed as docs/contest/VALIDATION_REPORT.md and gated in CI via
    test_scout_validation. hal::testing::SyntheticScene is the shared scene
    builder.
    The battery's first run caught two real defects, both fixed:
    - vision.scout_analyzer.v2: width is now the MINIMUM support width over a
    1-degree direction sweep (rotation-invariant; a rotated hexagon measures
    its across-flats). The pri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
    [main.cpp]
2026-08-31 feat(filesystem): typed settings store (closes M2)
    Line-oriented name=type:value persistence (deliberately not JSON: flat
    settings diff cleanly and survive on-device hand edits). Atomic save via
    temp + rename; deterministic sorted output; typed getters with defaults;
    malformed lines skip and count rather than fail, so a damaged file degrades
    to defaults key by key. int->double reads widen; other mismatches fall back.
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2026-08-31 feat(tools): nut variant for the scout card demo; use SyntheticScene
    ui_preview --scout-card-demo OUT.ppm [bolt|nut] - the nut render doubles as
    a public proof of the rotation-invariant v2 width measurement (15-deg M6
    hexagon still reads its across-flats). Inline scene pixels replaced with the
    shared hal::testing::SyntheticScene builder.
    [main.cpp]
2026-08-31 feat(ui): source-image thumbnail on the Scout result card
    Renderer gains drawImage (nearest-neighbour blit, gray8/RGB888). The card
    reserves a right column when a thumbnail is present - sections lay out
    against the narrower width so nothing collides - and aspect-fits the source
    frame under a SOURCE tag. The app loads the record's first netpbm artifact
    (new P5/P6 loader, truncation-safe); ui_preview passes the synthetic scene
    through in demo mode and loads the artifact beside a record JSON.
    [main.cpp]
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2026-09-02 docs(bringup): first UNO Q session status board + committed scout renders
    Brief P4: nine-step first-session board (UNTESTED/PASS/FAIL/BLOCKED), tied
    to the existing checklists and the presentation-link protocol. Brief P3
    audit result recorded in the session log: no dimension coupling and no
    Scout type leakage into shared layers (sim defaults and test fixtures only).
    docs/media/renders holds the genuine software renders for the Hackster page.
2026-09-02 ci: add Linux/GCC job - first compile of the UNIX-only target code
    Brief P1: the UNO Q runs Debian, but until now only MSVC ever built the
    tree; V4l2Camera, UnoQBoard, and SerialMcuBridge have never been compiled
    anywhere. ubuntu-latest is the closest CI stand-in for the target short of
    the board itself.
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2026-09-02 fix(board): spell out Config() default argument for GCC
    GCC rejects `Config config = {}` as a default argument on the aggregate
    with default member initializers; MSVC accepts it. First finding from the
    new Linux CI job, which exists precisely to catch target-platform breaks
    before the UNO Q does.
2026-09-02 fix(board): delegate the no-config UnoQBoard constructor from the .cpp
    GCC cannot evaluate Config NSDMIs in a default argument inside the
    enclosing class; the delegating constructor is defined where Config is
    complete. Round two of the Linux CI job doing its job.
2026-09-02 fix: v4l2 include path in the capture tool + format the unoq board files
    V4l2Camera.hpp never resolved against the target include root
    (platform/camera/src) - the correct path is v4l2/V4l2Camera.hpp. Latent
    since PR #11: no build had ever compiled the Linux-only path until the new
    CI job. Round three.
    [main.cpp]
2026-09-02 fix(camera): delegate FakeCamera default construction for GCC
    Same enclosing-class NSDMI rule as UnoQBoard::Config, fixed the same way;
    swept the tree for remaining `= {})` nested-aggregate default arguments and
    found none. Round four.
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2026-09-18 feat(scout): measure YUYV frames and analyze in the capture harness
    The capture and analysis halves of the Scout slice could not meet. The
    analyzer accepted RGB888/Gray8 only, while the capture harness selected
    the largest MJPEG mode and no decoder exists in the tree - so a UVC
    webcam (the bench Adesso CyberTrack H4 offers MJPEG and YUYV, and
    neither RGB888 nor GREY) would capture successfully and then fail
    analysis with UnsupportedFormat. It went unnoticed because FakeCamera
    emits RGB888, a format the real hardware never produces.
    - vision: toGray() handles packed YUYV by keeping the luma byte that
    leads each pixel; the format gate and the buffer-size expectation
    follow. Compressed for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
    [main.cpp]
2026-09-18 feat(firmware): platypus mascot on the UNO Q LED matrix
    Replaces the factory heart/animation demo on the 8x13 matrix with the
    project's own mascot, and doubles as the MCU aliveness proof that
    TEST_CHECKLISTS §1 asks for - a paddling platypus shows the MCU is
    running our code rather than factory firmware, and photographs better
    for the documentation score.
    Four frames at 220 ms (glide, kick, glide, blink), written as literal
    0/1 rows so the shape stays editable by eye. Proportion carries the read
    at 104 LEDs: a two-row bill and three-row tail against a six-row body.
    NOT COMPILED - the UNO Q core was not available here and the board's MCU
    runs Zephyr, so the exact matrix API is unconfirmed;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
    [led_matrix_platypus.ino]
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2026-09-20 docs(bringup): Session A checklist; bench script picks the real capture node
    The bare UNO Q already exposes /dev/video0 and /dev/video1 with no camera
    attached - they are the Qualcomm Venus codec's M2M decoder/encoder nodes,
    and they list pixel formats. bench_session.sh selected the first node and
    told the webcam from its metadata node by format count, so on this board
    it would have handed the codec to the capture harness. It now filters by
    the Video Capture capability (excluding memory-to-memory), skips the rest
    with a reason, and pins --mode 640x480 for the live capture, since that is
    the YUYV ceiling on typical webcams and the format the analyzer needs.
    TEST_CHECKLISTS gains Session A: t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
2026-09-20 fix: clear the three warnings GCC 14 raised on the first native UNO Q build
    The board's compiler (Debian 13, GCC 14.2 aarch64) is newer than CI's
    GCC 12 and MSVC, and flagged three sites neither had:
    - SerialMcuBridge::digitalWrite: std::byte{level ? 1u : 0u} narrows
    unsigned to unsigned char in list-initialisation. Cast explicitly.
    - mcu::encode: reserve() + push_back() trips GCC 12-14's spurious
    -Wfree-nonheap-object through the inlined _M_realloc_append guard. The
    frame size is known up front, so build it sized and indexed instead -
    no reallocation path either. Wire bytes are unchanged; the framing
    tests and the linked-display round trip prove it.
    - runValidation: GCC mis-track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
    [SerialMcuBridge.cpp]
2026-09-20 style: clang-format the hardware files touched by the GCC 14 warning fixes
    CI formats every changed file whole, and Framing.hpp / SerialMcuBridge.cpp
    carried pre-existing violations. Whitespace only.
    [SerialMcuBridge.cpp]
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2026-09-28 fix(vision): never measure a blob that runs off the frame edge
    Bench evidence, 2026-09-21: hand-held lighting over the calibration sheet
    left a vignetted rim darker than Otsu's threshold, so the whole border of
    the scene segmented as one huge blob. It was not a square, so it could not
    be the reference - but it was the largest remaining blob, which made it the
    subject, and the analyzer confidently reported 119 x 70 mm for a printed
    40 x 8 mm bar. Nothing in the record hinted that the number was nonsense.
    A partly visible blob cannot be measured: a clipped square yields a wrong
    scale and a clipped subject a wrong length, both silently. Segmentation now
    records touchesBorder per blob and drops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
2026-09-29 fix(scout): kiosk includes KmsHelpers for connector names
    [main.cpp]
2026-09-29 fix(scout): kiosk string literals split by a tooling escape bug
    [main.cpp]
2026-09-29 fix(scout): kiosk parses --fake
    [main.cpp]
2026-09-30 feat(kiosk): systemd unit + platypus-mode toggle between desktop and kiosk
    The kiosk needs DRM master, which the stock image's lightdm/Xorg holds, so
    every boot meant `sudo systemctl stop lightdm` by hand. platypus-kiosk.service
    declares Conflicts=display-manager.service, so systemd itself guarantees the
    desktop and the kiosk never contend for the screen; `platypus-mode` switches
    between them now and at boot (multi-user.target vs graphical.target), with
    `kiosk --once` for a session that reverts on reboot, and `status`.
    The unit runs as the checkout's owner, never root, with video/input groups
    for DRM, V4L2 and evdev; restarts every 5 s until a camera is plugged in;
    and stops with SIGTERM, w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
2026-09-30 fix(kiosk): USB-C host mode in kiosk mode; wait for the webcam, never exit
    Enabling the DSI panel leaves the UNO Q's only USB-C port in device (ADB
    gadget) mode: the ANX7625 USB-C bridge loses its DSI input and fails to
    probe ("fail to parse DT: -19"), so nothing switches the dwc3 role to host
    and no hub or webcam ever enumerates. The kiosk then exited on "no V4L2
    camera", leaving a black console that only a reboot back to the desktop
    cleared. Undocumented upstream; found on the bench.
    - platypus-kiosk.service switches the role to host before the kiosk starts
    and back to device (restoring ADB) after it stops. Forcing host is safe
    here: the board's only VBUS source, the PMIC usb_vbus reg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
    [main.cpp]
2026-09-30 fix(vision): flatten uneven lighting before thresholding (scout_analyzer v3)
    Bench, 2026-09-29, late-night desk lamp: frames that looked fine to the eye
    were refused as "no 20 mm square found". A desk lamp's falloff plus the
    webcam's vignetting left one corner of the paper ~7x darker than the
    centre; one global Otsu threshold put the dim paper in the foreground, and
    it merged with the square and the screw into a single blob touching the
    frame edge. The MVP's acceptance bar is ordinary bench lighting - uneven
    light and moderate shadows - so this is a correctness bug, not a setup one.
    flattenIllumination() models the paper as a smooth cubic surface in (x, y),
    fitted by least squares to a samp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
2026-09-30 fix(vision): refuse subjects smaller than the smallest in-scope part
    With the fastener out of frame, the largest remaining blob was a speck on
    the paper and it was measured with full confidence (bench, 2026-09-29:
    2.1 x 1.8 mm for a square-only frame). The subject must now be at least
    10 mm^2 - an M3 nut, the smallest in-scope part, is ~26 mm^2 - scaled
    through the reference so the floor holds at any camera height. Test covers
    a speck above the old 64 px blob floor (refused) and an M3-nut-sized part
    (measured). Validation battery still 21/21.
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2026-09-30 docs(hardware): concrete DSI bring-up plan for the panel on the bench (#26)
    * docs(hardware): concrete DSI bring-up plan for the panel actually on the bench
    Photographs of the bench hardware on 2026-09-28 overturned two assumptions
    in DSI_PANEL_CANDIDATES.md. The panel is the Waveshare 5inch DSI LCD
    (800x480, ICN6211 bridge, 15-pin 1.0 mm FPC), not the 5-DSI-TOUCH-A with a
    stock Arduino profile, so `display=5-dsi-touch-a` would configure the wrong
    panel. And the carrier's DISPLAY connector is 22-pin 0.5 mm, so neither
    cable in hand joins them.
    DSI_BRINGUP.md records the as-built hardware and the three gaps with what
    closes each: a 15<->22 DSI cable; the launch-era image's missing carrier
    o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
2026-10-01 Stabilize kiosk launch guidance and exercise offscreen capture in CI
    Correct --once's message: it preserves the existing boot configuration.
    Check that the Linux kiosk saves a synthetic source frame, observation JSON,
    preview and result card; retain unresolved fields. No hardware or accuracy
    claim, and no measurement/classification algorithm changes.
    Refs #32.
2026-10-01 docs: stabilize submitted Dream Lab baseline and evidence record
    Record the completed September 30 submission and actual merge/CI state.
    Preserve the later branch write-up byte-for-byte, hash available artifacts,
    correct the real screw identity and stale panel procedure, and provide
    one pinned UNO Q build/launch/recovery sequence with a run record.
    Raw final captures, actual tested SHA, physical media and native baseline
    replay remain explicit gates. No new algorithm tuning. Refs #32.
2026-10-05 hardware(pcb): add Perception Head Rev A pre-layout design package (#44)
    Merge the reviewed Rev A pre-layout schematic/design baseline. Physical bench, camera, ToF, power, mechanical, layout, and fabrication gates remain open; no physical results are implied.
    [debug_test.kicad_sch, host_interface.kicad_sch, id_calibration.kicad_sch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]
2026-10-06 display: prepare compact 3.5in DSI evaluation path (#45)
    Merge the reviewed compact-display research, reversible UNO Q software path, bench acceptance tooling, portrait kiosk support, and Fusion parameter inputs. No compact-display physical compatibility o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
    [compact_display_mechanical.csv]
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2026-10-07 sketch_intent: benchmark, demo, design doc and CI
    - bench/benchmark.py: dev and frozen held-out fixtures scored against
    ground truth (false proposals, missed, questions), noise and sampling
    sweeps, ShadowScan synthetic renders and the scan-0053 washer as
    evaluation-only sets; failure cases listed first
    - demo/run_demo.py: end-to-end CLI demo with overlays and Mesh2CAD export,
    including the refusals (open gap, freeform, uncalibrated)
    - docs/architecture/SKETCH_INTENT_RESOLVER.md: canonical home, contract,
    decision rules, review/export, limitations, physical gate still owed
    - .github/workflows/sketch-intent.yml: tests (Mesh2CAD export validation
    at a pinned commit when reachable),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
